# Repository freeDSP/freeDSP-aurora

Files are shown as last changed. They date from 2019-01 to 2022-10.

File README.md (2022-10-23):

FreeDSP logo

# freeDSP aurora

An open source and open hardware [freeDSP](https://freedsp.github.io) board based on ADAU1452 with 8 analog I/O, S/P-DIF I/O, ADAT I/O, USB Audio, WiFi, Bluetooth.

It supports various and convenient physical addons and multiple software plugins, and is controlled by web interface.

## Main features

* Analog Devices ADAU1452, 294.912 MHz, 32-bit SigmaDSP
	* 6144 SIMD instructions per sample @ 48kHz fs
	* 40kWords of data RAM
	* 800ms digital audio delay pool @ 48kHz fs
	* 8 stereo ASRCs with 139dB DNR
* XMOS XE216-512-TQ128 for multichannel bidirectional audio streaming
* ESP32 for WiFi or Bluetooth control
* AKM AK4458 32bit-DAC
* AKM AK5558 32bit-ADC
* Supporting sample rates between 44.1kHz and 192kHz
* 8 analog balanced input channels, +6dBu
* 8 analog balanced output channels, +6dBu
* S/P-DIF input and output
* ADAT input and output
* Wordclock input and output
* Support for display, rotary encoder, volume potentiometer, temperature sensor, PWM controlled fan, IR sensor
* One freeDSP expansion header
* USB Audio Class 2 Bidirectional streaming with 8 channels in and 8 channels out, full-duplex. Works with ASIO driver under Windows 10 and driverless under macOS and Linux.
* Realtime control software over WiFi or Bluetooth available under an open source license
* THD DAC: -103dB @ 1kHz, 0dBfs, fs=48kHz
* THD ADC: -101dB @ 1kHz, 0dBfs, fs=48kHz
* Latency: 1.125ms (talkthrough ADC->DSP->DAC)
* Board dimensions: 110mm x 110mm

MAIN COORDINATOR: [dspverden](https://github.com/dspverden)

## Contributing

**Please take care on which branch you're currently working!**

Branches:

- *master* - this branch always holds the latest released revision
- *develop* - this is the develop branch with new features. Please base your patches on this branch.

[Build instructions](BUILDING.md) | [Addons](ADDONS/README.md) | [User Documentation](DOCUMENTATION/)

## License
<br />This work is licensed under a <a rel="license" href="http://creativecommons.org/licenses/by-sa/4.0/">Creative Commons Attribution-ShareAlike 4.0 International License</a>.

## Related Projects
- [Generate Aurora Plugins from SigmaStudio Exports (Alternative to Aurora's python scripts)](https://github.com/archi/aurora-tool)
- [PCB with startup delay (I2C) mod with a DM 2.4" OLED](https://github.com/Ca-Wi/freeDSP-aurora-extension-i2c-mod-display)
- [PCB to expand the freeDSP aurora expansion port with 3V3 regulator](https://github.com/Ca-Wi/freeDSP-aurora-expansion-port-extender)

## Custom Plugins
- [7.1 Homecinema Plugin with Highpassfilter by pillepalle1234](https://github.com/pillepalle1234/FreeDSP-Aurora-7.1-Homecinema-Plugin-Highpass)

## Links

- [Buy Aurora board and addons](https://auverdion.de/)
- [freeDSP](https://freedsp.github.io)
- [Kickstarter campaign](https://www.kickstarter.com/projects/auverdion/freedsp-aurora-dsp)
- [DIYAudio forum (english)](https://www.diyaudio.com/forums/digital-line-level/334055-freedsp-aurora-dsp-8-os-usb-audio-dif-adat-bluetooth-wifi-contro.html)
- [DIYHifi forum (german, features)](https://www.diy-hifi-forum.eu/forum/showthread.php?18572-freeDSP-aurora-Der-Feature-Thread)
- [DIYHifi forum (german, specs)](https://www.diy-hifi-forum.eu/forum/showthread.php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)
- [ADAU1452 at Analog Devices](https://www.analog.com/en/products/adau1452.html)
- [ESP32 at Espressif](https://www.espressif.com/en/products/socs/esp32/overview)
- [XMOS XE216-512-TQ128 datasheet](https://www.xmos.com/file/xe216-512-tq128-datasheet)
- [AKM 4458](https://www.akm.com/us/en/products/audio/audio-dac/ak4458vn/)
- [AKM 5558](https://www.akm.com/us/en/products/audio/audio-adc/ak5558vn/)

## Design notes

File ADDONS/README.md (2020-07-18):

# Addons

## Add-On A: The woodworker’s friend

Perfect for an active loudspeaker 

- 1x XLR Analog in
- 1x RCA Analog in
- 1x TOSlink in (for S/P-DIF via glassfiber)
- 1x RCA Digital in (for S/P-DIF via coaxial cable)
- 1x RCA Digital out (connect a subwoofer)
- 1x XLR Analog Out (connect a subwoofer)
- 1x USB
- Volume potentiometer

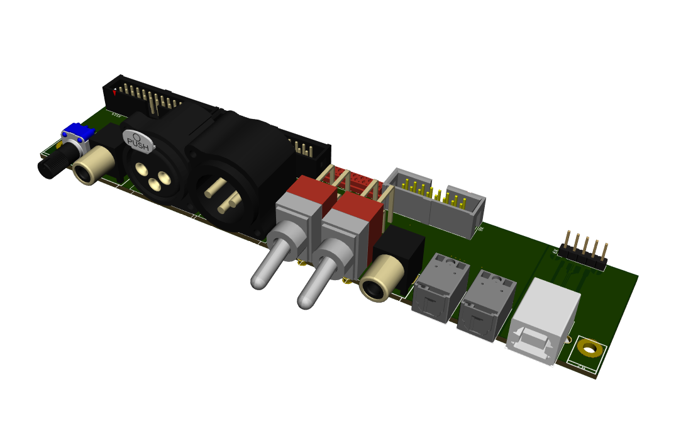
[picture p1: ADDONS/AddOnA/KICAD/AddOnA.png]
Board


### Links

* [Schematics and backplates v1.0.0](AddOnA%201.0.0/)
* [Schematics and backplates](AddOnA/)

## Add-On B: Down with developers

Pre-amp / 7.1-management without limits.

- 8x XLR Analog Out, unbalanced (RCA) is possible too
- 8x RCA Analog In
- 8x XLR Analog In
- 4x RCA Digital In (for S/P-DIF via Cinch)
- 4x TOSlink Digital In ((for S/P-DIF via LWL)
- 1x USB in

All digital inputs are up for multiplexing

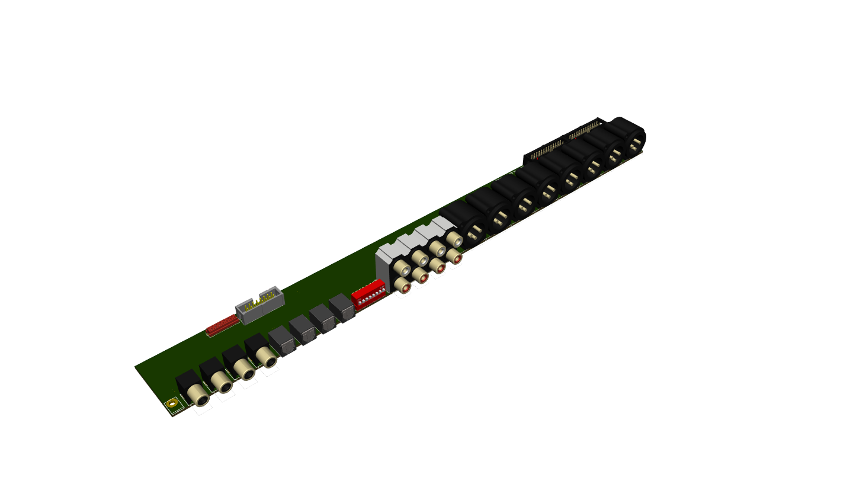
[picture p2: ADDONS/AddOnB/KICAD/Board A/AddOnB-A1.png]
Board A

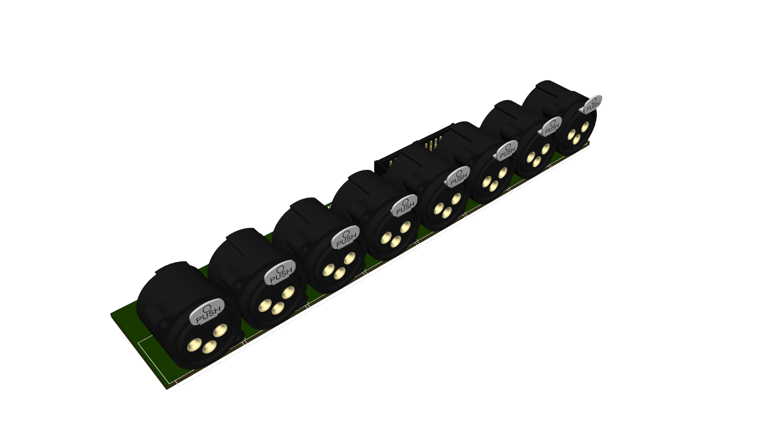
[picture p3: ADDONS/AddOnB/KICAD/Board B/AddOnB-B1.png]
Board B


### Links

* [Schematics and backplates](AddOnB/)

## Add-On C: For those who love to take control over the crowd

Loudspeaker management system for your next gig.

- 8x XLR Analog Out
- 4x XLR Analog In, two ADCs parallel for a much better SNR
- 1x TOSlink in
- 1x TOSlink out
- 1x XLR Digital In AES/EBU
- 1x XLR Digital Out AES/EBU
- 1x USB

All TOSlink can be used with ADAT or S/P-DIF.

### Links

* [Schematics and backplates](AddOnC/)

## Add-On D: Balanced Life

* 8x XLR analog input (balanced)
* 8x XLR analog output (balanced)

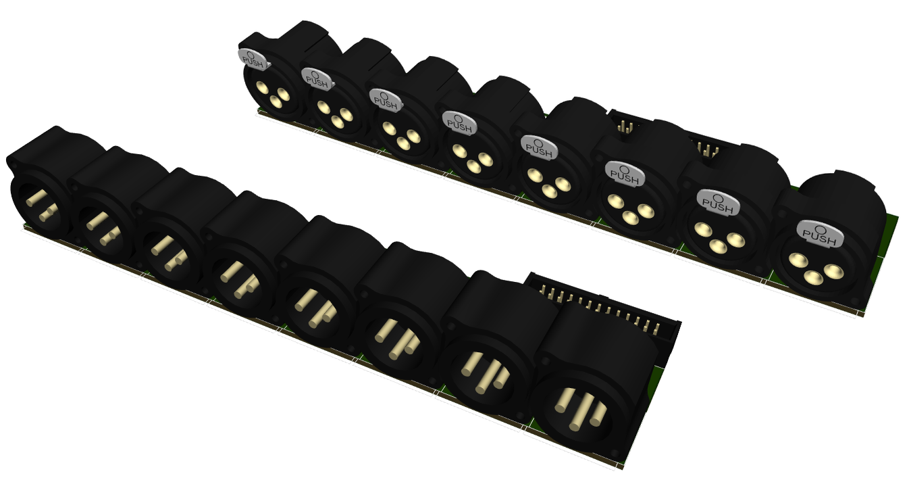
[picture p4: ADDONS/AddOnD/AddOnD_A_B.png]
Board A & B


### Links

* [Schematics and backplates](AddOnD/)

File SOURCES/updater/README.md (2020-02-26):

Updating Aurora DSP with a new binary.

Step 1
Connect your USB2Serial converter to your Aurora DSP. See the UserManual_1.1.1.pdf regarding the required wire connections.

Step 2
Open a terminal and change to directory: <path to repository>/SOURCES/WEBAPP/ESP32/updater

Step 3
On macOS you may have to make the install script executable by typing chmod +x update.sh

Step 4
On macOS execute the firmware update by running ./update.sh <your_com_port>
On Win10 execute the firmware update by running update.bat <your_com_port>
Replace <your_com_port> with the name of your USB2Serial converter, e.g. /dev/cu.SLAB_USBtoUART on macOS or COM7 on Win10.

Step 5
Follow the instructions on your screen.

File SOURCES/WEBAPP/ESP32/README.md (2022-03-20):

# How to build ESP32 firmware

## Installing ArduinoIDE

Go to https://www.arduino.cc/en/Main/Software or use your preferred package manager to install ArduinoIDE.

## Installing the ESPAsyncWebServer library

Follow the next steps to install the ESPAsyncWebServer library:

1. Download the ESPAsyncWebServer library from https://github.com/me-no-dev/ESPAsyncWebServer/archive/master.zip.  
2. Unzip the .zip folder and you should get `ESPAsyncWebServer-master` folder.
3. Rename your folder from `ESPAsyncWebServer-master` to `ESPAsyncWebServer`.
4. Move the `ESPAsyncWebServer` folder to your Arduino IDE installation libraries folder.

## Installing the Async TCP Library for ESP32

The ESPAsyncWebServer library requires the AsyncTCP library to work. Follow the next steps to install that library:

1. Download the AsyncTCP library from https://github.com/me-no-dev/AsyncTCP/archive/master.zip.  
2. Unzip the .zip folder and you should get `AsyncTCP-master` folder.
3. Rename your folder from `AsyncTCP-master` to `AsyncTCP`.
4. Move the `AsyncTCP` folder to your Arduino IDE installation libraries folder.

## Installing the Arduino ESP32 Filesystem Uploader

1. Go to https://github.com/me-no-dev/arduino-esp32fs-plugin/releases/ and click the `ESP32FS-1.0.zip` file to download.
2. Unzip the .zip folder and you should get `ESP32FS` folder
3. Move the `ESP32FS` folder to your Ardino IDE installation tools folder.  
You should have a similar folder structure: `<home_dir>/Arduino/tools/ESP32FS/tool/esp32fs.jar`.

## Installing the ArduinJSON library

1. Open the Arduino Library Manager
2. Search for `ArduinoJson`
3. Select the version: `6.13.0`
4. Click Install.

## Installing the U8g2 library

1. Open the Arduino Library Manager
2. Search for `U8g2`
3. Select the version: `2.27.6`
4. Click Install.

## Installing the IRremote Library

1. Download the IRremote library from https://github.com/dspverden/Arduino-IRremote/archive/master.zip.
2. Unzip the .zip folder and you should get `Arduino-IRremote-master` folder.
3. Rename your folder from `Arduino-IRremote-master` to `Arduino-IRremote`.
4. Move the `Arduino-IRremote` folder to your Arduino IDE installation libraries folder.

## Installing ESP32 boards

1. Open ArduinoID `File > Preferences` dialog, and add following URL to Additional Cards setting:
- https://dl.espressif.com/dl/package_esp32_index.json

2. Open `Tools > Card Types > Manage Cards` and install `ESP32 dev module`.
3. Select `Tools > Card Types > ESP32 Arduino > ESP32 Dev Module` as card.

Ensure Python is in your PATH (as `python`) and it has pyserial module installed.

## Uploading Code and Files

Before uploading, read [firmware update documentation](../../../DOCUMENTATION/AN001%20Firmware%20Update%20EN.pdf).

1. Open the file `aurora.ino` in your ArduinoIDE and click on Upload.
2. After uploading the code, you need to upload the data files.
3. Go to `Tools > ESP32 Data` Sketch Upload and wait for the files to be uploaded.

## That's it

You can now compile and upload new ESP32 firmware.

----

# Alternative method using espmake32 (experimental)

**Following instructions are meant only for espmake32, else skip this!**

## espmake32

Download and install [espmake32](https://github.com/plerup/makeEspArduino).

## Download and install libraries

You have to download the last libraries manually, you'll find them here:

1. [ArduinoJson](https://github.com/bblanchon/ArduinoJson/releases/download/v6.13.0/ArduinoJson-v6.13.0.zip)
2. [u8g2](https://github.com/olikraus/u8g2/archive/master.zip), which does not offer proper releases. Let's hope master doesn't break anything.
3. [IRremote](https://github.com/z3t0/Arduino-IRremote/archive/master.zip). However, while [this PR from dspverden](https://github.com/z3t0/Arduino-IRremote/pull/689) isn't merged, you'll probably prefer [dspverden's branch](https://github.com/dspverden/Arduino-IRremote/archive/master.zip).

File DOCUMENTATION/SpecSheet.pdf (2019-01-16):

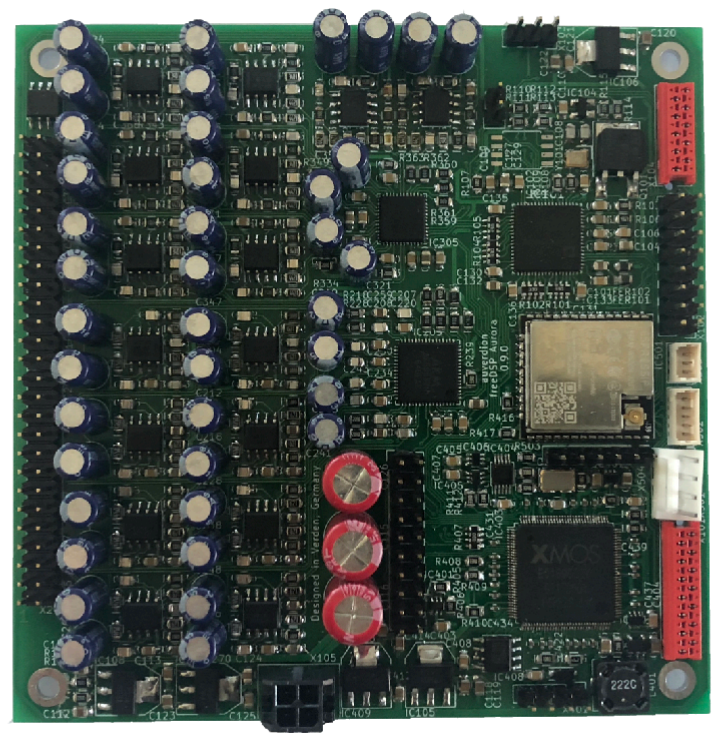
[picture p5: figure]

# FREEDSP-AURORA SPECIFICATIONS PRELIMINARY

auverdion | 1

## REVISION HISTORY

Revision | Description | Date
v1.0 | Initial Version | 15 Jan 2019
auverdion | 2

## ABOUT FREEDSP-AURORA

The freeDSP-aurora is a cost-effective real-time audio signal processing solution for researchers and the do-it-yourself community. It is a bare circuit board that can be incorporated into your own projects. It comes with no housing. Easy assembling and simple programmability are the main focus. It is based on Analog Devices’ ADAU1452 DSP chip in bundle with the free graphical development environment SigmaStudio. The programming model is function-block based – comparable to other graphical programming languages like PureData or Max/MSP. Many prebuilt blocks (e.g., filters, compressors, effects, or logic) can be placed in the signal path via drag and drop. If the included libraries do not have the functions needed, low-level blocks, such as multipliers and delays, can be wired together to create custom algorithms. For more information please refer to the Analog Devices website.

FreeDSP-aurora offers a wide range of DSP processing options and interface controls with easy programmability. It can be used in various audio applications, e.g.:

Room compensation / system equalization
Digital crossovers in active loudspeaker concepts
Multiband dynamics processing
Delay compensation / phase shift
Bass enhancement
Subwoofer integration
Advanced instrument audio effect units Stereo image widening
…

A XMOS XE216-512-TQ128 MCU is used to expose an USB Audio Class 2 compliant interface to a host computer running macOS, Linux or Windows 10. The boards provides 8 audio input and 8 audio output channels to the host computer. Additionally an ADAT input/ output and a Wordclock input/output is provided by the XMOS MCU.

auverdion | 3

The ESP32 MCU controls the operation of the DSP. Furthermore, it provides WiFi and Bluetooth connectivity and handles peripherals like rotary encoder, display, temperature sensor, PWM controlled fan and IR sensor.

As part of the project an open source software is published that controls the operation of the freeDSP-aurora from macOS, Windows or iOS. Via the control software the user can access all parameters of the uploaded DSP schematic. Due to the open source licenses users can modify the control software for supporting their own DSP schematics.

The plans and software for the freeDSP-aurora board are published under a Creative Commons Attribution NonCommercial ShareAlike 4.0 International (CC BY-NC-SA 4.0) license, which allows the unrestricted use and modification of the module for non-commercial purposes. This means that experienced users can make their own version of the board, extending it and improving it, as long as they credit freeDSP and auverdion and release their designs under the same license.
The freeDSP brand and freeDSP logo are copyright of Sebastian Merchel and Ludwig Kormann and cannot be used without formal permission.
The auverdion brand is copyright of Raphael Knoop and cannot be used without formal permission.
This getting started guide is published under the same CC license.
auverdion | 4

## FEATURES

- Analog Devices ADAU1452, 294.912 MHz, 32-bit SigmaDSP 6144 SIMD instructions per sample @ 48kHz fs 40kWords of data RAM
800ms digital audio delay pool @ 48kHz fs
8 stereo ASRCs with 139dB DNR
- XMOS XE216-512-TQ128 for multichannel bidirectional audio streaming
- ESP32 for WiFi or Bluetooth control
- AKM AK4458 32bit-DAC
- AKM AK5558 32bit-ADC
- Supporting sample rates between 44.1kHz and 192kHz
- 8 analog balanced input channels, +6dBu
- 8 analog balanced output channels, +6dBu
- S/P-DIF input and output
- ADAT input and output
- Wordclock input and output
- Support for display, rotary encoder, volume potentiometer, temperature sensor, PWM controlled fan, IR sensor
- One freeDSP expansion header
- USB Audio Class 2 Bidirectional streaming with 8 channels in and 8 channels out, full-duplex. Works with ASIO driver under Windows 10 and driverless under macOS and Linux.
- Realtime control software for Windows, macOS, Linux, iOS connecting by WiFi or Bluetooth available under an open source license
- Board dimensions: 100mm x 100mm
auverdion | 5

## OVERVIEWS

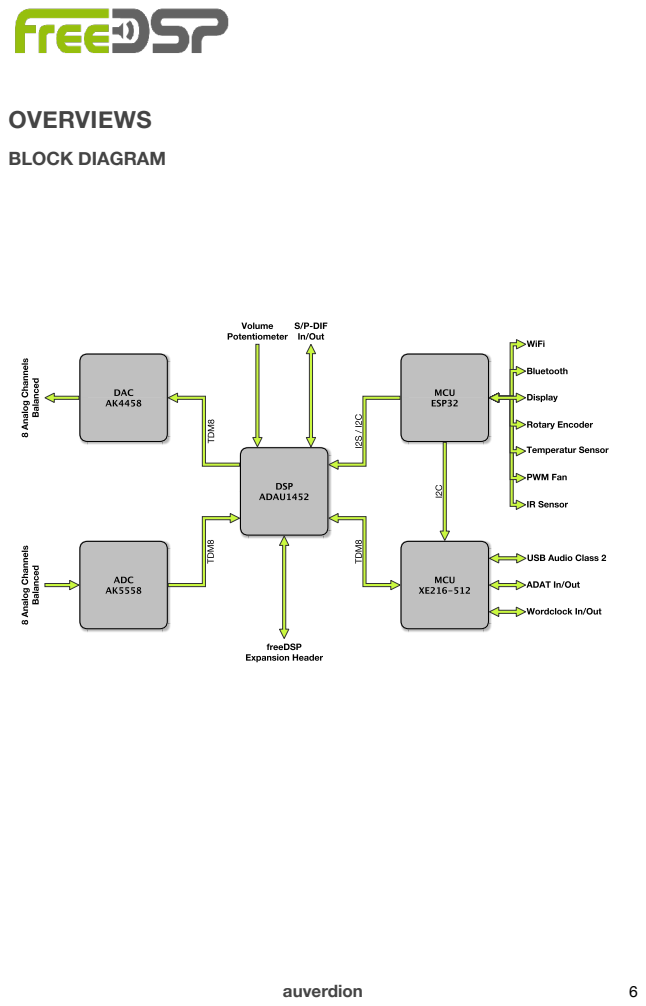
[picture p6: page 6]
BLOCK DIAGRAM; auverdion

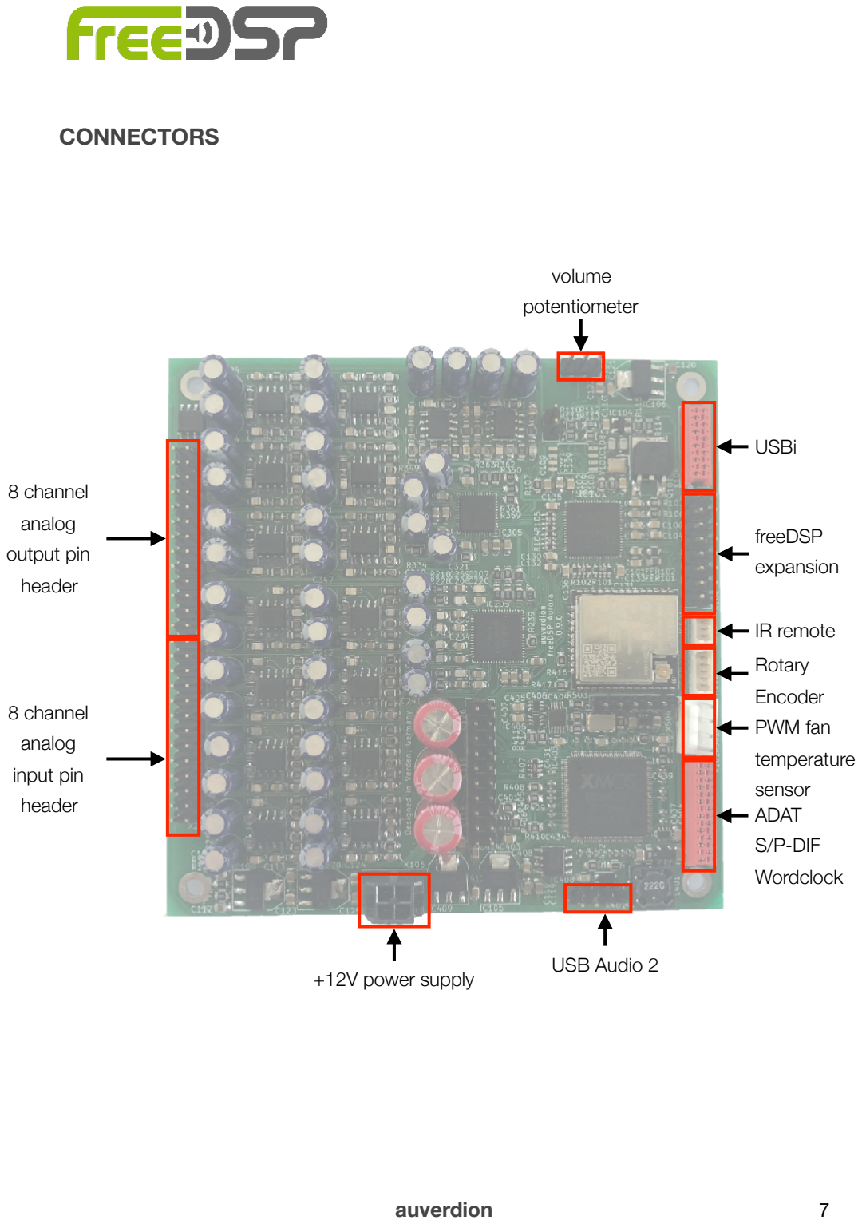
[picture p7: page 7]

CONNECTORS

auverdion | 7

8 channel
analog
output pin
header

8 channel
analog
input pin
header

+12V power supply

volume
potentiometer

USB Audio 2

freeDSP
expansion

USBi

IR remote

ADAT
S/P-DIF
Wordclock

Rotary
Encoder
PWM fan
temperature
sensor

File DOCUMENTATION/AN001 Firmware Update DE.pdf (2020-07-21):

# FIRMWARE UPDATE FREEDSP-AURORA

auverdion | 1

## REVISIONSÜBERSICHT

Revision | Beschreibung | Datum
v1.0.0 | Initial Version | 09 Feb 2020
v1.1.0 | WebOTA hinzugefügt | 26 Feb 2020
v2.1.0 | Empfehlung zum Presetexport hinzugefügt | 20 Jul 2020
auverdion | 2

Revisionsübersicht | 2
Wichtige Information | 4
Update der Firmware via USB | 5
Update vorbereiten | 5
Firmware hochladen | 6
Update der Firmware über webOTA | 12
Hochladen der Firmware | 12
Haftungsausschluss | 14
auverdion | 3

## WICHTIGE INFORMATION

Das freeDSP-Aurora-Board kann Signale erzeugen, die Dein Audiogerät beschädigen können. Bitte lies dieses Application Note und das Handbuch sorgfältig, bevor Du mit der Arbeit mit Deinem Board beginnst. Passe alle Hardware-Einstellungen an und konfiguriere Deine Software, bevor Du ein Audiogerät an freeDSP-aurora anschließt. Beginne immer mit der geringsten Lautstärke an Deinem Verstärker und erhöhe den Pegel langsam, um das Risiko einer Beschädigung Deines Audiosystems zu verringern.

Insbesondere die Installation von Alpha- und Betaversionen kann zu einem fehlerhaften Verhalten führen. Die Installation erfolgt auf eigenes Risiko.

FreeDSP-aurora wird Dir wie gesehen zur Verfügung gestellt. Auverdion gibt keine ausdrücklichen oder stillschweigenden Garantien in Bezug auf seine Funktionalität, Funktionsfähigkeit oder Nutzung, einschließlich, aber nicht beschränkt auf stillschweigende Garantien der Marktgängigkeit, der Eignung für einen bestimmten Zweck oder Rechtsverletzungen. Wir lehnen ausdrücklich jegliche Haftung für direkte, indirekte, Folge-, Neben- oder Sonderschäden ab, einschließlich, aber nicht beschränkt auf Umsatzeinbußen, entgangenen Gewinn, Verluste infolge von Betriebsunterbrechungen oder Datenverlust, unabhängig von der Art der Klage oder der Rechtstheorie, nach der die Haftung geltend gemacht werden kann, selbst wenn wir über die Möglichkeit oder Wahrscheinlichkeit solcher Schäden informiert wurden. Funktionen und Spezifikationen können ohne vorherige Ankündigung geändert werden.

Bitte beachte, dass freeDSP-aurora ein Open-Source-Projekt ist. Da freeDSP-aurora sehr flexibel ist, sind viele Anwendungen möglich. Fragen und neue Ideen können online mit anderen Nutzern diskutiert werden. Bitte verwende das Digital Line Level Subforum @ diyAudio.com oder das auverdion Subforum @ www.diy-hifi-forum.eu, um mit anderen Personen in Kontakt zu treten, die mit freeDSP-aurora arbeiten. Bitte erstelle nur dann individuelle Themen für Dein Anliegen, wenn Du Dein Problem in den vorhandenen Themen nicht findest. Einige Fragen können durch sorgfältiges Lesen dieses Handbuchs beantwortet werden.

auverdion | 4

## UPDATE DER FIRMWARE VIA USB

Dieses Kapitel führt Dich durch alle Schritte, um ein Firmwareupdate über eine USB-Verbindung durchzuführen. Das Update selbst wird durch ein Skript durchgeführt.

UPDATE VORBEREITEN

Für das Aktualisieren der Firmware benötigst Du ein USB2Serial-Modul basierend auf einem FTx232- oder CP2102N-Modul, z.B. https://www.ftdichip.com/Products/Modules/DevelopmentModules.htm#FT2232H_Mini oder ähnlich. Bitte vergewissere Dich, daß Dein Modul mit einer Spannung von 3.3V arbeitet. Module mit +5V Spannung können Deinen freeDSP-Aurora beschädigen.
Ggfs. Musst Du noch einen Treiber für Dein USB2Serial-Modul installieren. Bitte lies hierzu das Handbuch Deines Moduls.

Wenn Du ein Update von Version 2.x.x ausführen willst, exportiere bitte zunächst Deine Presets, damit Du diese nach dem Update wieder importieren kannst.

auverdion | 5

FIRMWARE HOCHLADEN

Um eine neue Firmware auf Deinen freeDSP-Aurora hochzuladen, gehe wie folgt vor:
1. Lade das neueste Release von github: https://github.com/freeDSP/freeDSP-aurora Wenn Du eine Alpha- oder Betaversion (Preview-Versionen) installieren möchtest, musst Du eventuell in den entsprechenden Featurezweig wechseln, indem Du diesen im Dropdown-Menu Branch auswählst, z.B. feature/develop und anschliessend auf Clone or download klickst und Download ZIP auswählst.

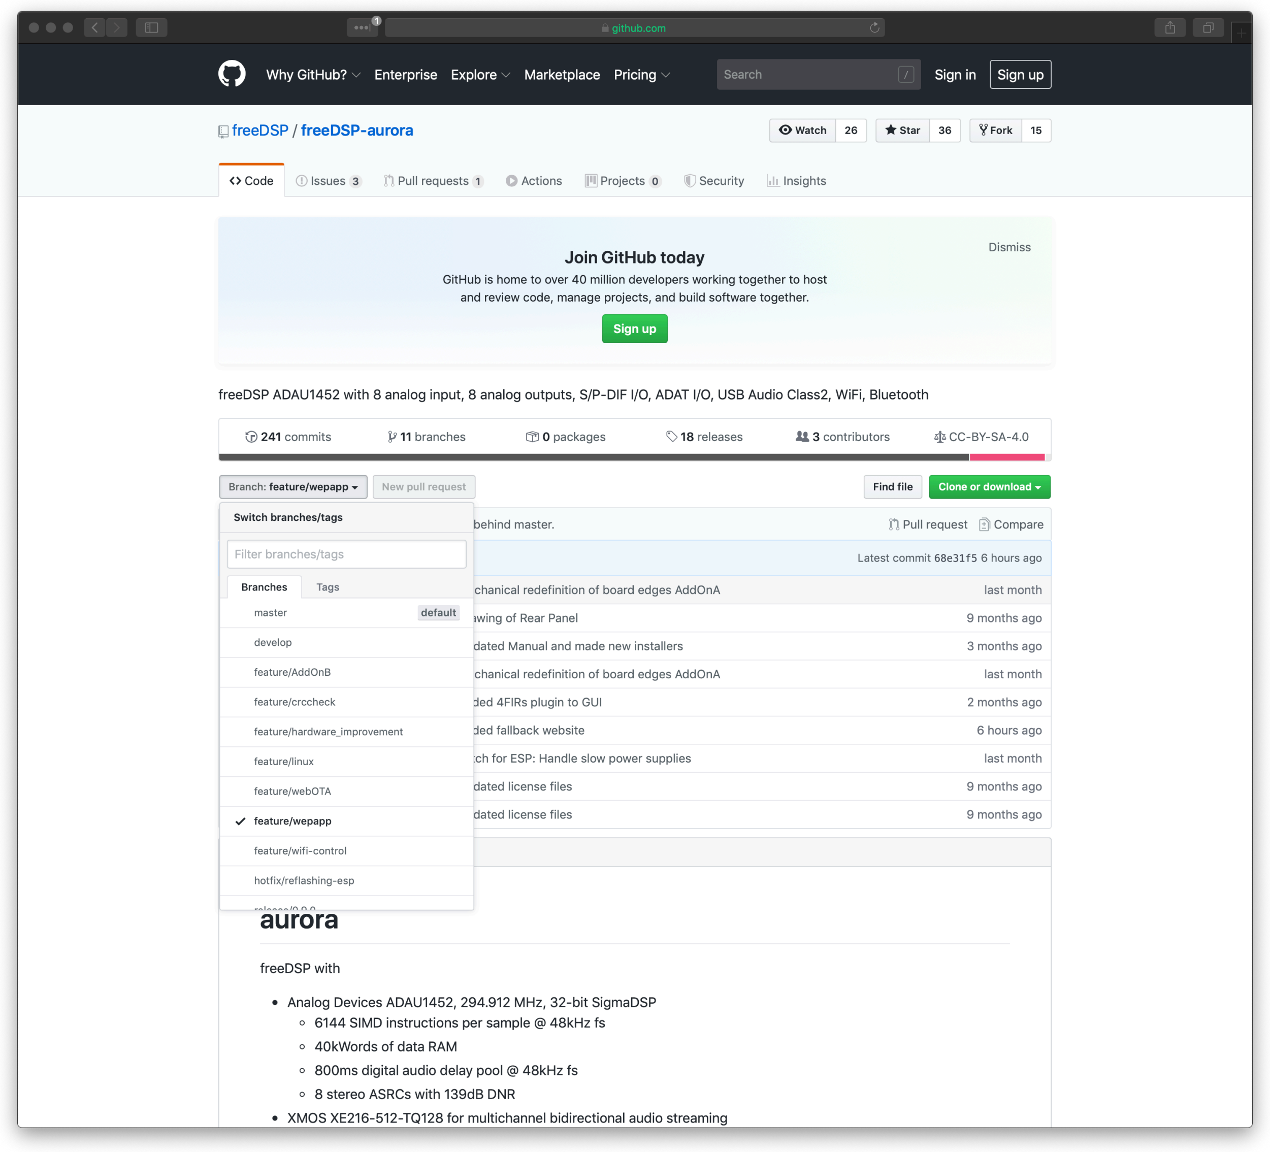
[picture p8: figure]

auverdion | 6

2. Entpacke die heruntergeladene zip-Datei (sofern Dein Computer dies nicht selbstständig erledigt).
3. Schalte Deinen freeDSP-aurora aus.
4. Installiere einen Jumper oder stelle eine Verbindung zwischen Pin 5 und 6 von X504 her. Das Update-Tool wird Dich an diesen Jumper erinnern.

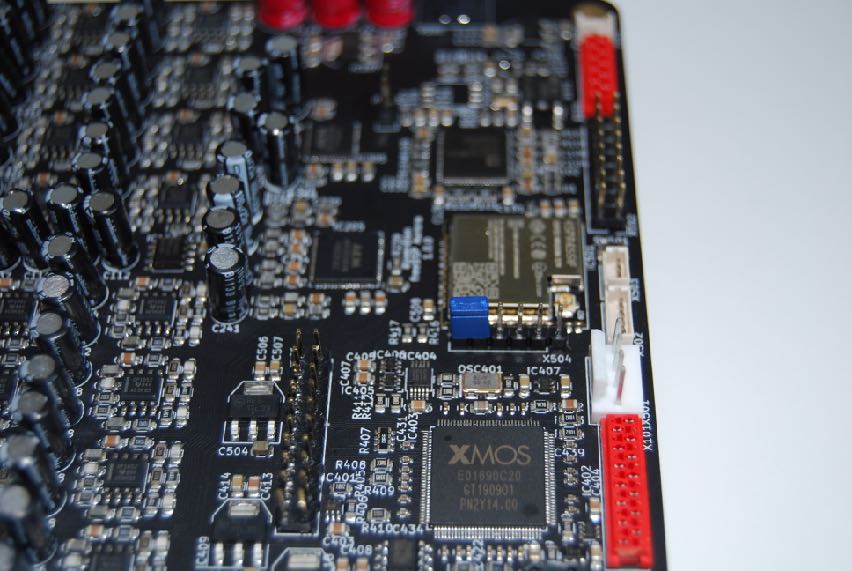
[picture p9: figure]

auverdion | 7

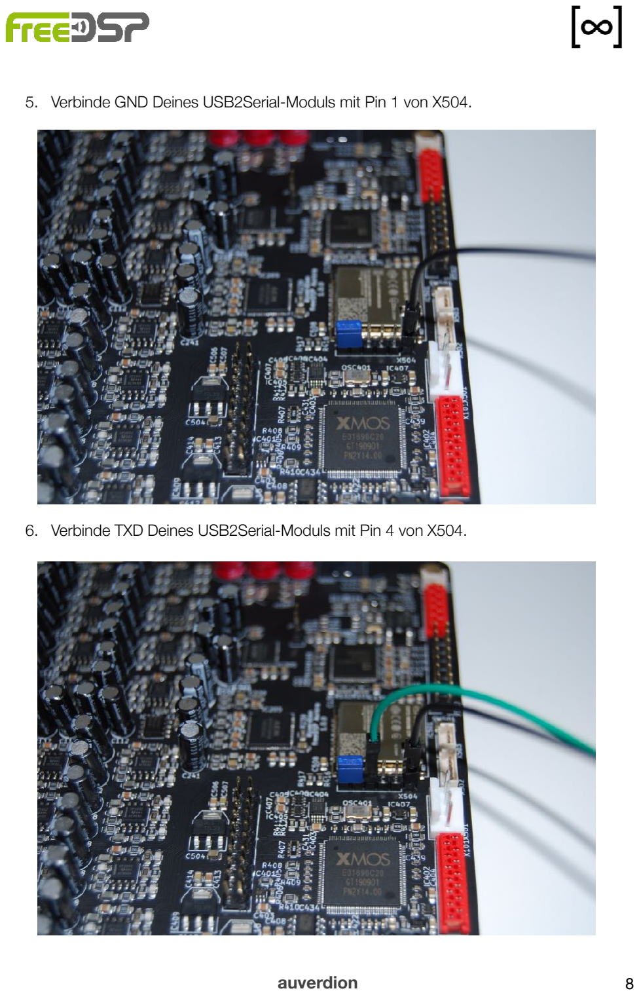
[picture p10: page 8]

5. Verbinde GND Deines USB2Serial-Moduls mit Pin 1 von X504.
6. Verbinde TXD Deines USB2Serial-Moduls mit Pin 4 von X504.
auverdion | 8

7. Verbinde RXD Deines USB2Serial-Moduls mit Pin 3 von X504.

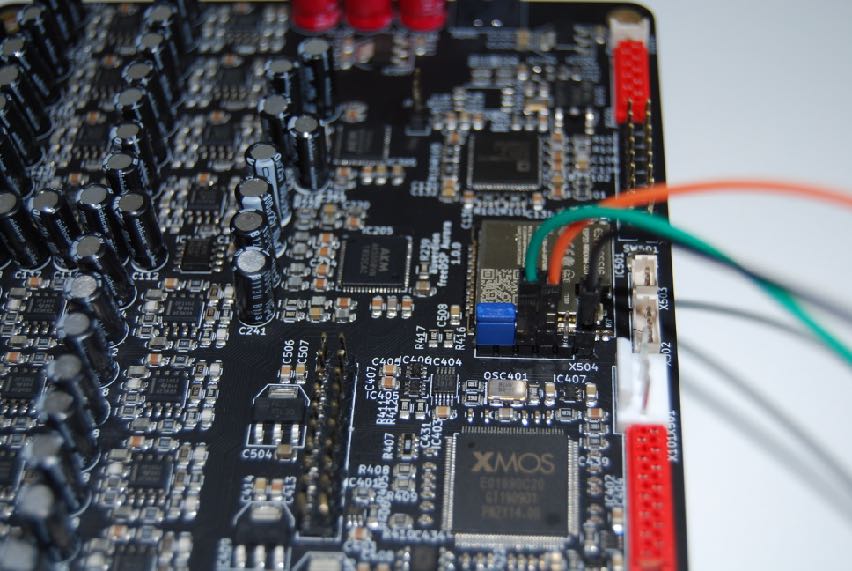
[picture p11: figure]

8. Verbinde Dein USB2Serial-Modul mit Deinem Computer.
9. Schalte freeDSP-Aurora ein.
10. Öffne ein Terminal (Eingabeaufforderung) and wechsle in das Skript-Verzeichnis durch Eingabe von
cd <path_to_repository>/SOURCES/WEBAPP/ESP32/updater
11. Unter macOs kann es sein, dass Du das Updateskript ausführbar machen musst. Gibt dazu ein:
chmod +x update.sh
12. Unter macOS starte das Skript mit ./update.sh <your_com_port>.
Dabei musst Du <your_com_port> durch den Namen Deines USB2Serial-Adapters
ersetzen, z.B. /dev/cu.usbserial-FTRXGG930.
13. Unter Windows gibts Du update.bat <your_com_port> ein.
Dabei musst Du <your_com_port> durch den Namen Deines USB2Serial-Adapters ersetzten, z.B. COM3.
auverdion | 9

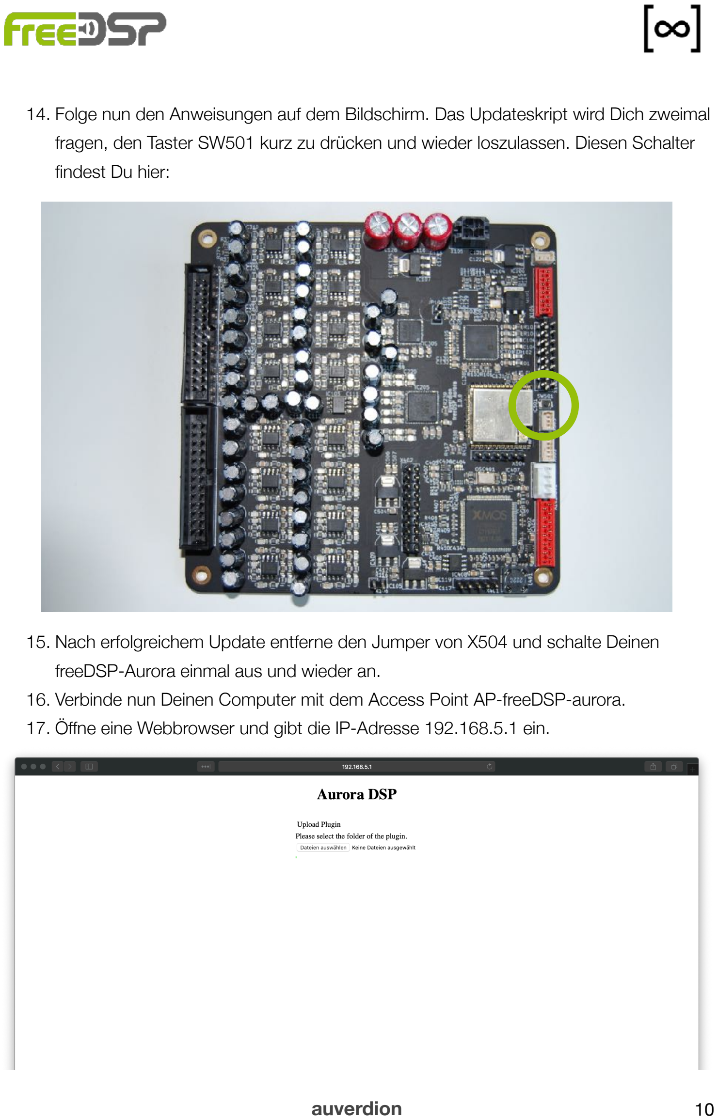
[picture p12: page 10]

14. Folge nun den Anweisungen auf dem Bildschirm. Das Updateskript wird Dich zweimal fragen, den Taster SW501 kurz zu drücken und wieder loszulassen. Diesen Schalter findest Du hier:
15. Nach erfolgreichem Update entferne den Jumper von X504 und schalte Deinen freeDSP-Aurora einmal aus und wieder an.
16. Verbinde nun Deinen Computer mit dem Access Point AP-freeDSP-aurora.
17. Öffne eine Webbrowser und gibt die IP-Adresse 192.168.5.1 ein.
auverdion | 10

18. Klicke nun auf Dateien auswählen und wähle das Verzeichnis mit Deinem Plugin aus. Wichtig: Bitte wähle nur das Verzeichnis, nicht eine Datei in dem Verzeichnis.
Du findest die Plugins im Verzeichnis <path_to_repository>/SOURCES/

WEBAPP/plugins

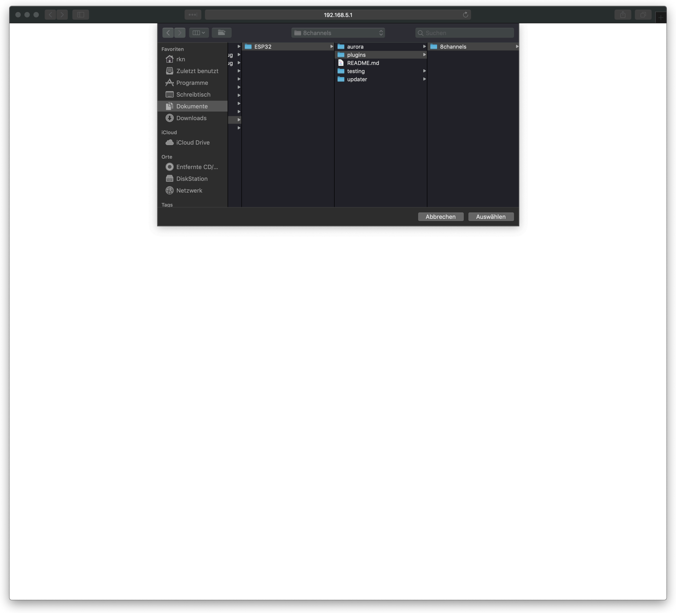
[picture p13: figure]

19. Es wird das gewählte Plugin installiert.
20. Nach erfolgreichem Update startest Du Deinen freeDSP-Aurora neu, verbindest Dich mit dem Access Point AP-freeDSP-aurora und gibst die Adresse 192.168.5.1 in Deinem Webbrowser ein. Du siehts nun das Webinterface Deines gewählten Plugins und kannst damit beginnen, freeDSP-Aurora für Deine Anwendung zu konfiguriere.
auverdion | 11

## UPDATE DER FIRMWARE ÜBER WEBOTA

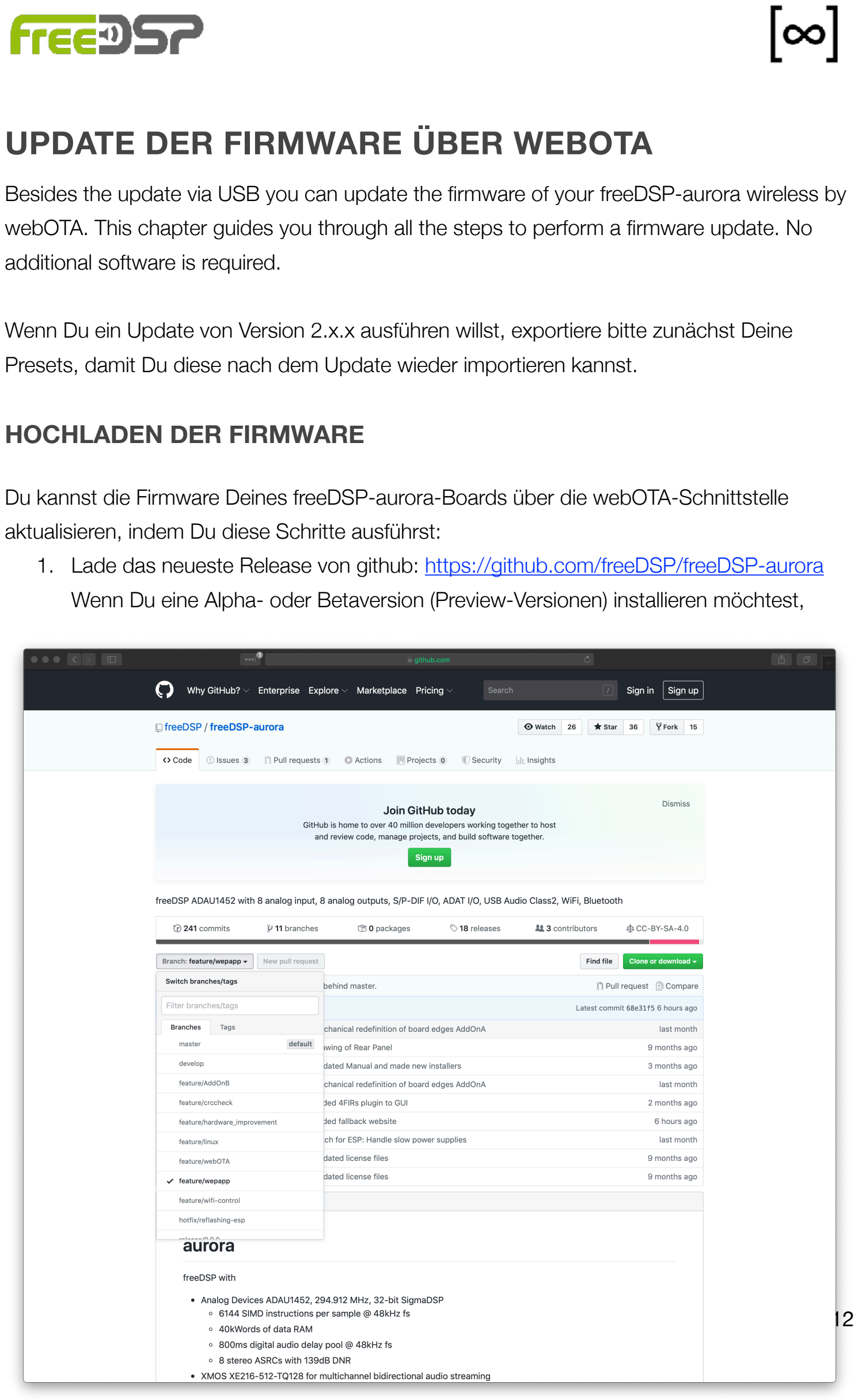
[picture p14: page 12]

Besides the update via USB you can update the firmware of your freeDSP-aurora wireless by webOTA. This chapter guides you through all the steps to perform a firmware update. No additional software is required.

Wenn Du ein Update von Version 2.x.x ausführen willst, exportiere bitte zunächst Deine Presets, damit Du diese nach dem Update wieder importieren kannst.

HOCHLADEN DER FIRMWARE

Du kannst die Firmware Deines freeDSP-aurora-Boards über die webOTA-Schnittstelle aktualisieren, indem Du diese Schritte ausführst:
1. Lade das neueste Release von github: https://github.com/freeDSP/freeDSP-aurora Wenn Du eine Alpha- oder Betaversion (Preview-Versionen) installieren möchtest,
auverdion | 12

musst Du eventuell in den entsprechenden Featurezweig wechseln, indem Du diesen im Dropdown-Menu Branch auswählst, z.B. feature/develop und anschliessend auf Clone or download klickst und Download ZIP auswählst. Die heruntegeladene ZIP-Datei musst Du noch entpacken, falls Dein Computer das nicht selbständig macht.
2. Verbinde Deinen Computer mit dem WiFi-Access-Point AP-freeDSP-aurora.
3. Öffne einen Webbrowser und gib die URL http://192.168.5.1/webota ein.
4. Alternativ kannst Du Deinen Computer mit dem gleichen lokalen WiFi-Netzwerk verbinden, mit dem auch Dein freeDSP-Aurora verbunden ist, und die IP 192.168.5.1 durch die IP ersetzen, die Dein Board von Deinem Router erhalten hat.
5. Klicke auf die Schaltfläche, um die Firmware-Binärdatei von Ihrer Festplatte auszuwählen. Der Dateiname der Firmware ist üblicherweise
aurora.ino.esp32.bin. Die Firmware auf dem neuesten Stand findest Du in

<path_to_repository>/SOURCES/WEBAPP/ESP32/updater
6. Sobald Du eine Datei ausgewählt hast wird die neue Firmware auf Dein Board hochgeladen. Nach dem erfolgreichen Update erhältst Du eine Benachrichtigung und Dein freeDSP-aurora-Board wird anschliessend automatisch neu gestartet.
7. Verbinde Dich mit dem Access Point AP-freeDSP-aurora und gebe http://192.168.5.1/fallback im URL-Feld Deines Browsers ein.
8. Installiere nun das Plugin neu.
9. Dein freeDSP-aurora ist nun auf dem neuesten Stand.
auverdion | 13

## HAFTUNGSAUSSCHLUSS

Alle Produkte, Produktspezifikationen und Daten können ohne Vorankündigung geändert werden, um die Zuverlässigkeit, Funktion oder das Design zu verbessern.
Auverdion, seine Tochtergesellschaften, Vertreter und Mitarbeiter sowie alle Personen, die in seinem oder ihrem Namen handeln, lehnen jegliche Haftung für Fehler, Ungenauigkeiten oder Unvollständigkeiten ab, die in einem Datenblatt, Handbuch, einer Anwendungsnotiz oder einem anderen Dokument zu einem Produkt enthalten sind.
Diese Baugruppe ist nur für den Einsatz in Musikwiedergabegeräten vorgesehen. Es werden keine Angaben zur Eignung für andere Zwecke gemacht. Sofern nicht anders angegeben, beziehen sich die angegebenen Spezifikationen nur auf diese Baugruppe. Die Verantwortung für die Überprüfung der Leistung, Sicherheit, Zuverlässigkeit und Einhaltung der gesetzlichen Normen von Endprodukten mit dieser Baugruppe liegt beim Hersteller des Endprodukts.

Auverdion gibt keine ausdrücklichen oder stillschweigenden Garantien in Bezug auf seine Funktionalität, Funktionsfähigkeit oder Nutzung, einschließlich, aber nicht beschränkt auf stillschweigende Garantien der Marktgängigkeit, der Eignung für einen bestimmten Zweck oder Rechtsverletzung. Wir lehnen ausdrücklich jegliche Haftung für direkte, indirekte, Folge-, Neben- oder Sonderschäden ab, einschließlich, aber nicht beschränkt auf Umsatzeinbußen, entgangenen Gewinn, Verluste infolge von Betriebsunterbrechungen oder Datenverlust, unabhängig von der Art der Klage oder der Rechtstheorie, nach der die Haftung geltend gemacht werden kann, selbst wenn wir über die Möglichkeit oder Wahrscheinlichkeit solcher Schäden informiert wurden.

Die Verwendung von Auverdion-Produkten in lebenserhaltenden Geräten oder Geräten, deren Ausfall erwartbar zu Verletzungen oder zum Tod führen kann, ist nicht zulässig.

auverdion | 14

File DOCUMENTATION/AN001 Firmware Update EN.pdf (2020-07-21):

# FIRMWARE UPDATE FREEDSP-AURORA

auverdion | 1

## REVISION HISTORY

Revision | Description | Date
v1.0.0 | Initial Version | 09 Feb 2020
v1.1.0 | Added webOTA | 26 Feb 2020
v2.1.0 | Added hint for preset export | 20 Jul 20
auverdion | 2

Revision History | 2
Important Information | 4
Updating the Firmware via USB | 5
Preparing for Update | 5
Uploading the Firmware | 6
Updating the Firmware via webOTA | 12
Uploading the Firmware | 12
Disclaimer | 14
auverdion | 3

## IMPORTANT INFORMATION

The freeDSP-aurora board might generate signals that may damage your audio equipment. Please read and understand this manual before starting to work with your board. Adjust all hardware settings and configure your software before connecting any audio equipment to freeDSP-aurora. Always start with low volume on your amplifier and slowly increase the level to reduce the risk of damaging your audio system.

Especially the installation of alpha and beta versions can lead to incorrect behavior. The installation is at your own risk.

freeDSP-aurora is provided to you ‘as is’. Auverdion makes no express or implied warranties whatsoever with respect to its functionality, operability, or use, including, without limitation, any implied warranties of merchantability, fitness for a particular purpose, or infringement. We expressly disclaim any liability whatsoever for any direct, indirect, consequential, incidental or special damages, including, without limitation, lost revenues, lost profits, losses resulting from business interruption or loss of data regardless of the form of action or legal theory under which the liability may be asserted, even if advised of the possibility or likelihood of such damages. Features and specifications might change without prior notice.

Please keep in mind that freeDSP-aurora is an open-source project. Because freeDSP-aurora is very flexible, many applications are possible. Questions and new ideas can be discussed online with other DIYers. Please use the Digital Line Level subforum @ diyAudio.com or the auverdion subforum @ www.diy-hifi-forum.eu to connect with other people working with freeDSP-aurora. Please create individual threads for your topics only if you cannot find your issue in the existing threads. Some questions can be answered by carefully reading this manual.

auverdion | 4

## UPDATING THE FIRMWARE VIA USB

This chapter guides you through all the steps to perform a firmware update via an USB connection. The update itself will be done by a script.

PREPARING FOR UPDATE

For updating the firmware you need an USB2Serial module based on a FTx232 or CP2102N module, e.g.
https://www.ftdichip.com/Products/Modules/DevelopmentModules.htm#FT2232H_Mini or similar. Please make sure that your module works with a voltage of +3.3V. Modules with +5V voltage can damage your freeDSP-Aurora.
You may need to install a driver for your USB2Serial module. Please read the manual of your module.

If you are updating from version 2.x.x please export your presets first and import them after the update again.

auverdion | 5

UPLOADING THE FIRMWARE

For uploading a new firmware to your freeDSP-aurora do the following steps:
1. Download the latest release from github: https://github.com/freeDSP/freeDSP-aurora If you want to install a alpha or beta version (preview versions) instead you may have to switch to the right feature branch by selecting it in the branch drop down menu, e.g. feature/develop. Then click on Clone or download and select Download ZIP.

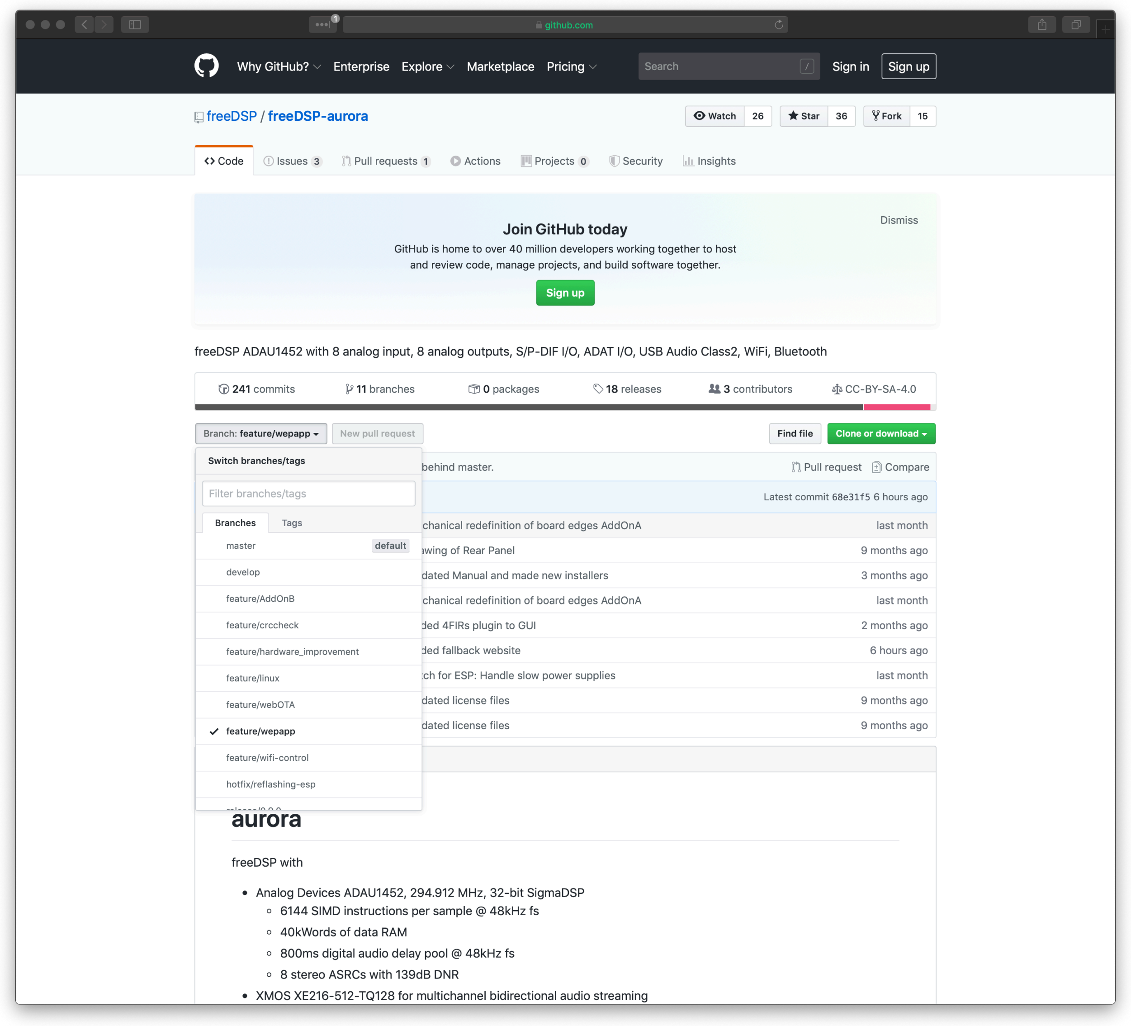
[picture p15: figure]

2. Unzip the downloaded zip file (if your computer does not do this by itself).
3. Power off your freeDSP-aurora module.
auverdion | 6

4. Install a jumper or make a connection between pin 5 and 6 of X504. The update tool will remind you of this jumper.


auverdion | 7

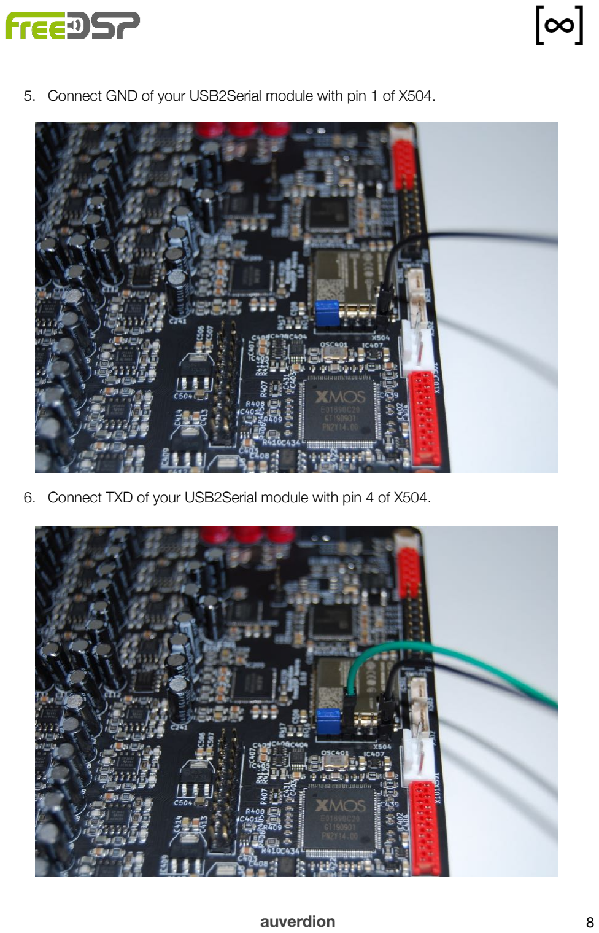
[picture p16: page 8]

5. Connect GND of your USB2Serial module with pin 1 of X504.
6. Connect TXD of your USB2Serial module with pin 4 of X504.
auverdion | 8

7. Connect RXD of your USB2Serial module with pin 3 of X504.


8. Connect your USB2Serial module with your computer.
9. Power up your freeDSP-aurora.
10. Open a terminal (command prompt) and change to script directory by entering
cd <path_to_repository>/SOURCES/WEBAPP/ESP32/updater
11. On macOs you may have to make the update script executable by entering
chmod +x update.sh
12. Under macOS start the update scrip by ./update.sh <your_com_port>. Replace <your_com_port> by the name of your USB2Serial module, e.g.
/dev/cu.usbserial-FTRXGG930.
13. Under Windows start the update scrip by update.bat <your_com_port>. Replace <your_com_port> by the name of your USB2Serial module, e.g. COM3.
auverdion | 9

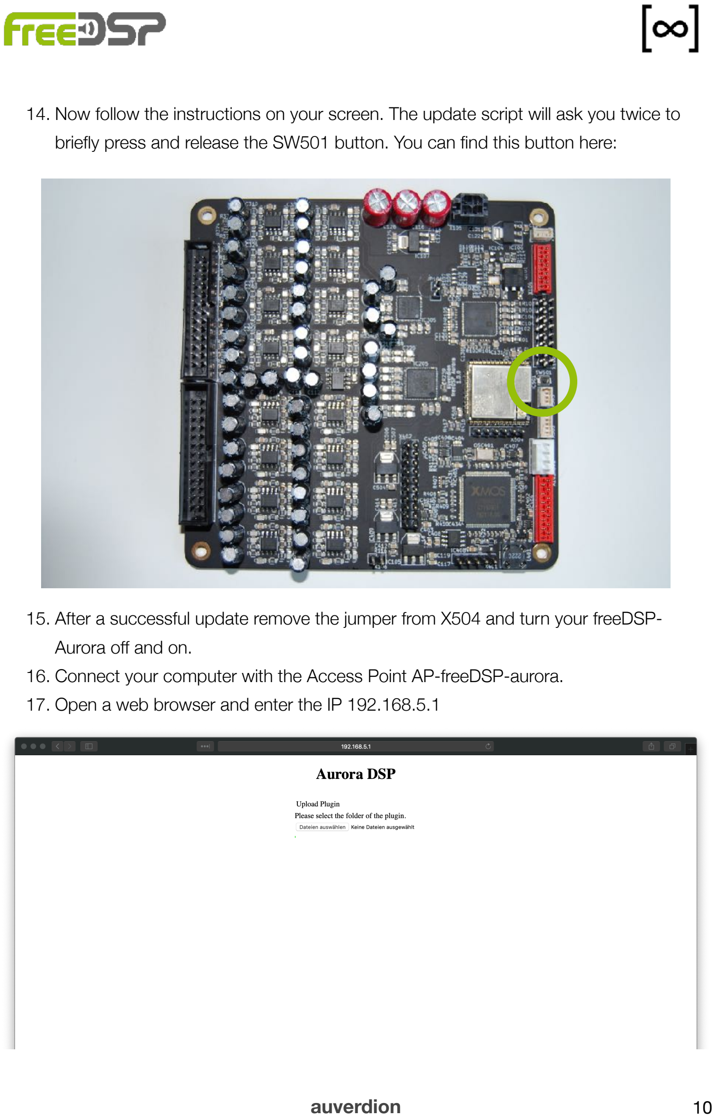
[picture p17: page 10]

14. Now follow the instructions on your screen. The update script will ask you twice to briefly press and release the SW501 button. You can find this button here:
15. After a successful update remove the jumper from X504 and turn your freeDSP-Aurora off and on.
16. Connect your computer with the Access Point AP-freeDSP-aurora.
17. Open a web browser and enter the IP 192.168.5.1
auverdion | 10

18. Click now on Select files and select the directory of the plugin you want to install. Important: You have to select the directory name not any file inside this directory. You
will find the plugins here: <path_to_repository>/SOURCES/WEBAPP/plugins

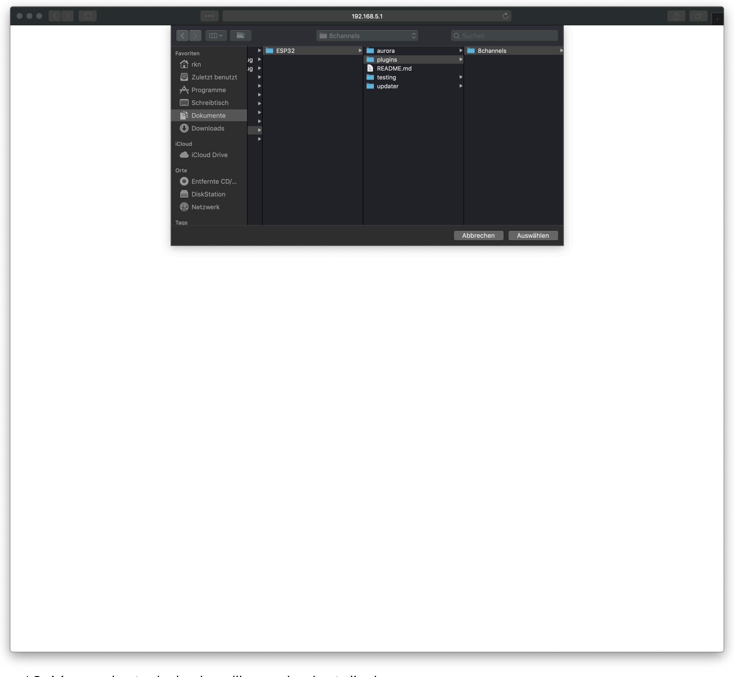
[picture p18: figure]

19. Your selected plugin will now be installed.
20. After successful installation restart your freeDSP-Aurora, reconnect to access point AP-freeDSP-aurora and in your web browser type in the address 192.168.5.1. You will see now the web interface of your selected plugin. You can now start to configure freeDSP-Aurora for your application.
auverdion | 11

## UPDATING THE FIRMWARE VIA WEBOTA

Besides the update via USB you can update the firmware of your freeDSP-aurora wireless by webOTA. This chapter guides you through all the steps to perform a firmware update. No additional software is required.

If you are updating from version 2.x.x please export your presets first and import them after the update again.

UPLOADING THE FIRMWARE

For uploading a new firmware to your freeDSP-aurora do the following steps:
1. Download the latest release from github: https://github.com/freeDSP/freeDSP-aurora If you want to install a alpha or beta version (preview versions) instead you may have

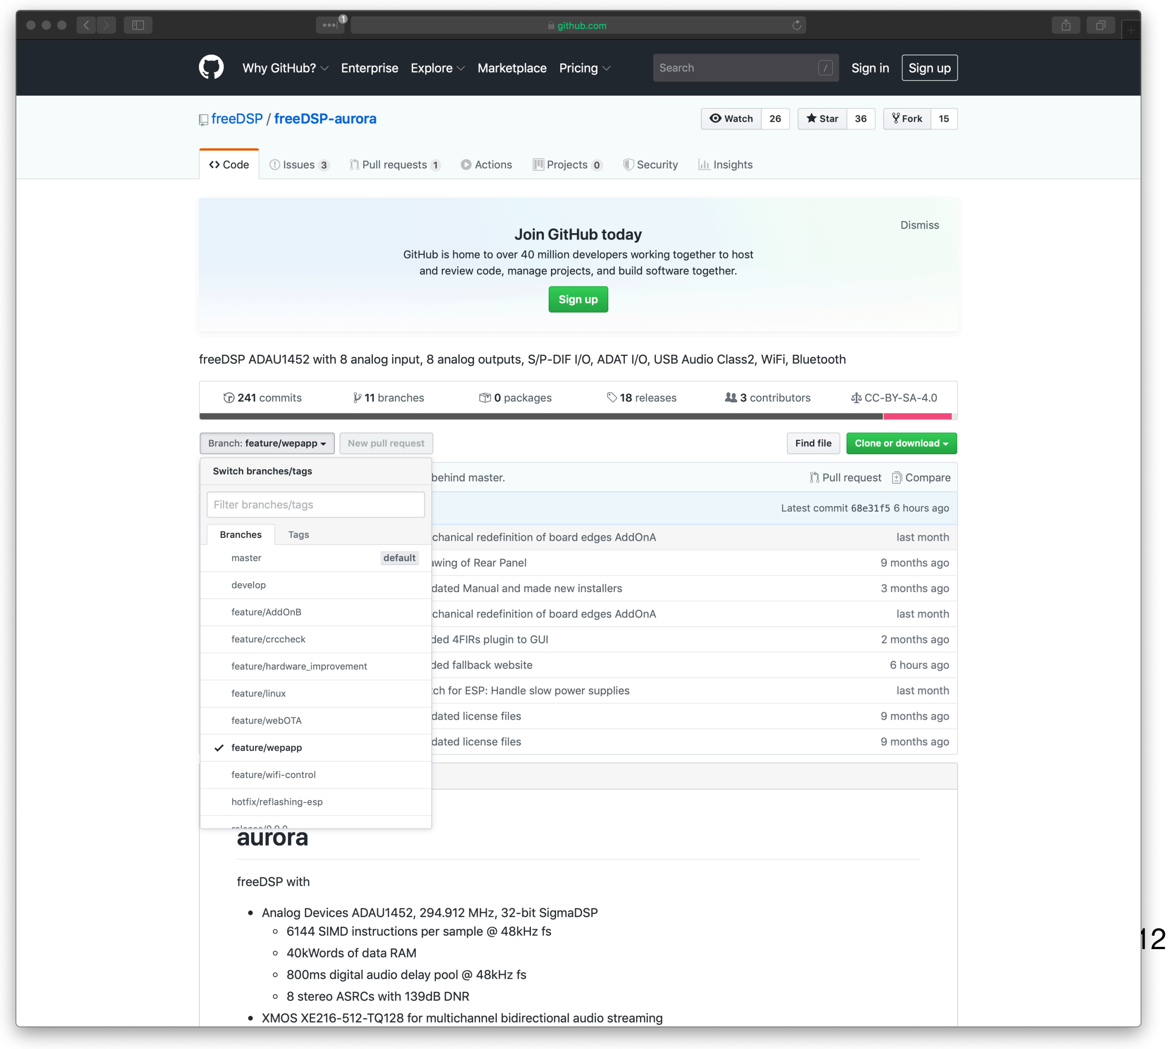
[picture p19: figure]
auverdion

to switch to the right feature branch by selecting it in the branch drop down menu, e.g. feature/develop. Then click on Clone or download and select Download ZIP.
2. Unzip the downloaded zip file (if your computer does not do this by itself).
3. Connect you computer with the WiFi access point AP-freeDSP-aurora.
4. Open web browser and type in the URL http://192.168.5.1/webota
5. Alternatively you can connect you computer to the same local WiFi network your freeDSP-aurora is connected to and replace the ip 192.168.5.1 by the ip your board got from your router.
6. Click on the button to select the firmware binary from your hard disk. The filename of the firmware is usually aurora.ino.esp32.bin. You can find the latest binary in

<path_to_repository>/SOURCES/WEBAPP/ESP32/updater
7. Once you have selected a file the update process starts. The new binary will now be uploaded to your board. After a successful update you will see a message box and afterwards your freeDSP-aurora board will restart.
8. Connect to the Access Point AP-freeDSP-aurora and enter http://192.168.5.1/fallback (http://192.168.5.1/fallback) in the URL field of your browser.
9. Reinstall your plugin now.
10. Your freeDSP-aurora is updated now.
auverdion | 13

## DISCLAIMER

All products, product specifications and data are subject to change without notice to improve reliability, function or design or otherwise.
Auverdion, its affiliates, agents, and employees, and all persons acting on its or their behalf, disclaim any and all liability for any errors, inaccuracies or incompleteness contained in any datasheet, manual, application note or any other document relating to any product.
This subassembly is designed for use in music reproduction equipment only. No representations are made as to fitness for other uses. Except where noted otherwise any specifications given pertain to this subassembly only. Responsibility for verifying the performance, safety, reliability and compliance with legal standards of end products using this subassembly falls to the manufacturer of said end product.

Auverdion makes no express or implied warranties whatsoever with respect to its functionality, operability, or use, including, without limitation, any implied warranties of merchantability, fitness for a particular purpose, or infringement. We expressly disclaim any liability whatsoever for any direct, indirect, consequential, incidental or special damages, including, without limitation, lost revenues, lost profits, losses resulting from business interruption or loss of data regardless of the form of action or legal theory under which the liability may be asserted, even if advised of the possibility or likelihood of such damages.

Life support policy: Use of auverdion products in life support equipment or equipment whose failure can reasonably be expected to result in injury or death is not permitted.

auverdion | 14

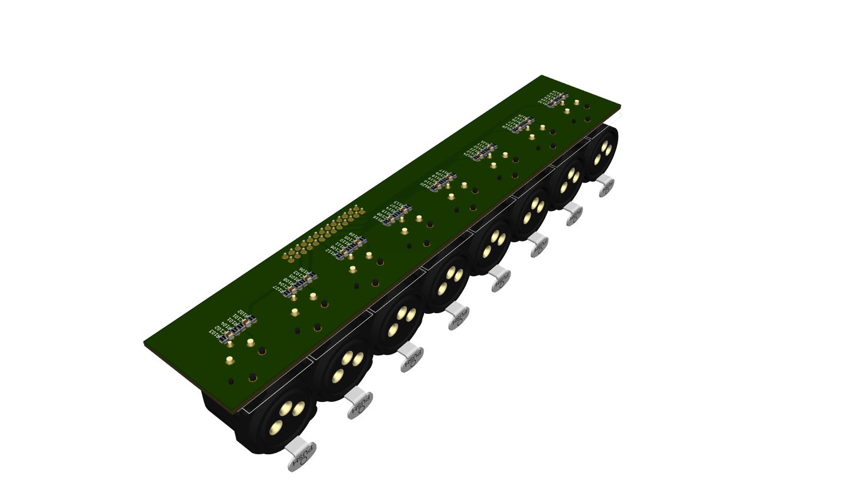
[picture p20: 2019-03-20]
ADDONS/AddOnB/KICAD/Board B/AddOnB-B2.png

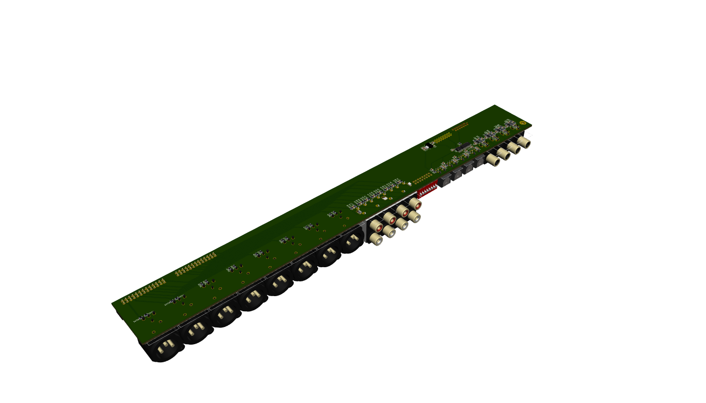
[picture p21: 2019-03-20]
ADDONS/AddOnB/KICAD/Board A/AddOnB-A2.png

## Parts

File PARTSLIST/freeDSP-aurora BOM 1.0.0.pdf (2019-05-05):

### freeDSP-aurora BOM rev 1.0.0

Reference Reference | Qty Qty | Footprint | Value1 | Value2 | Manufacturer | pn
C103 | 1 | C0805-X7R | 5n60 | 10% 50V X7R | Yageo | CC0805KRX7R9BB562
C101, C104, C111, C117, C119, C120, C122, C123, C125, C127, C132, C259, C260, C337, C360, C409, C410, C412, C414, C415, C502, C507, C508 | 23 | C0805-X7R | 10u0 | 20% 25V X5R | Murata Electronics North America | GRM21BR61E106MA73L
C102, C105, C109, C110, C118, C121, C124, C128, C129, C130, C131, C133, C134, C135, C136, C220, C230, C234, C242, C249, C261, C262, C264, C273, C274, C275, C276, C277, C278, C279, C280, C320, C328, C336, C344, C352, C361, C362, C363, C364, C365, C366, C367, C368, C369, C370, C371, C372, C373, C374, C375, C376, C377, C402, C403, C404, C405, C406, C407, C408, C411, C413, C501, C503, C506 | 65 | C0805-X7R | 100n | 5% 50V X7R | KEMET | C0805C104K5RACTU
C106 | 1 | C0805-X7R | 150p | 5% 50V C0G | KEMET | C0805C151J5GACTU
C107, C108 | 2 | C0805-X7R | 22p0 | 5% 50V C0G/NP0 | KEMET | C0805C220J5GACTU
C112, C113, C114, C137, C138, C203, C204, C211, C212, C217, C218, C219, C227, C228, C229, C233, C237, C238, C241, C247, C248, C255, C256, C269, C270, C301, C302, C309, C310, C314, C315, C321, C324, C325, C329, C330, C331, C340, C341, C345, C346, C347, C353, C356, C357 | 45 | RD2_D5_L11 | 100u | 20% 25V | Nichicon | UVY1E101MDD
C115, C116, C126 | 3 | RD3.5_D8_L14 | 330u | 20% 25V | Wurth Electronics Inc. | 860010474012
C201, C210, C225, C226, C240, C252, C267, C268 | 8 | C0805-X7R | 1n00 | 5% 50V PPS | Panasonic Electronic Components | ECH-U1H102JX5
C205, C206, C213, C214, C221, C222, C231, C232, C236, C243, C244, C246, C257, C258, C271, C272, C281, C282, C283, C284, C285, C286, C287, C288 | 24 | C0805-X7R | 100p | 5% 50V C0G/NP0 | KEMET | C0805C101J5GACTU
C202, C207, C208, C209, C215, C216, C223, C224, C235, C239, C245, C251, C253, C254, C265, C266 | 16 | C0805-X7R | 220p | 2% 50V PPS | Panasonic Electronic Components | ECH-U1H221GX5
C250 | 1 | C0805-X7R | 4u70 | 20% 25V X5R | Murata Electronics North America | GRM21BR61E475MA12L
C263, C401 | 2 | C0805-X7R | 10n0 | 10% 50V X7R | Yageo | CC0805KRX7R9BB103
C305, C306, C318, C319, C334, C335, C350, C351 | 8 | C0805-X7R | 27p0 | 5% 50V C0G/NP0 | KEMET | C0805C270J5GACTU
C307, C308, C322, C323, C338, C339, C354, C355 | 8 | C0805-X7R | 3n90 | 5% 16V PPS | Panasonic Electronic Components | ECH-U1C392JX5
C313 | 1 | C0805-X7R | 1u00 | 10% 16V X7R | Yageo | CC0805KKX7R7BB105

Reference | Qty | Footprint | Value1 | Value2 | Manufacturer | pn
C303, C304, C311, C312, C316, C317, C326, C327, C332, C333, C342, C343, C348, C349, C358, C359 | 16 | C0805-X7R | 470p | 2% 50V PPS | Panasonic Electronic Components | ECH-U1H471GX5
C416, C504 | 2 | C0805-X7R | 22u0 | 20% 10V X5R | Murata Electronics North America | GRM21BR61A226ME51L
C417, C418, C419, C420, C421, C422, C423, C424, C425, C426, C427, C428, C429, C430, C431, C432, C433, C434, C435, C436, C437, C438, C439, C440, C441 | 25 | C0402-X7R | 100n | 10% 10V X7R | Murata Electronics North America | GRM155R71A104KA01D
D401 | 1 | SOD123 | MBR120VLSFT | Schottky 20V 1 A | ON Semiconductor | MBR120VLSFT3G
FER101, FER102 | 2 | C0805-RES | 600R | @100MHz 600mA | Murata Electronics North America | BLM21AG601SN1D
IC101 | 1 | QFP72_10x10_EP | ADAU1452 | - | Analog Devices Inc. | ADAU1452WBCPZ
IC102 | 1 | SOIJ8_5.3x5.3mm_P1.27mm | DNP | 1Mbit | Microchip Technology | 25AA1024T-I/SM
IC103 | 1 | SOIC8_3.9x4.9mm_Pitch1.27mm | TLE2426ID | Spannungsrefere nz | Texas Instruments | TLE2426IDR
IC104 | 1 | SOT143 | ADM811TARTZ | Spannungsmonito r | Analog Devices Inc. | ADM811TARTZ-REEL
IC105, IC107 | 2 | SOT223 | LM1117MP-5.0 | LDO | Texas Instruments | LM1117MP-5.0/NOPB
IC106, IC409, IC502 | 3 | SOT223 | NCP1117LPST33 | LDO | ON Semiconductor | NCP1117LPST33T3G
IC201, IC202, IC203, IC204, IC206, IC207, IC208, IC209, IC301, IC302, IC303, IC304, IC306, IC307, IC308, IC309 | 16 | SOIC8_3.9x4.9mm_Pitch1.27mm | OPA1652AIDR | OpAmp | Texas Instruments | OPA1652AIDR
IC205 | 1 | QFN64_9x9mm_Pitch0.5mm_EP | AK5558VN | ADC | AKM Semiconductor Inc. | AK5558VN
IC305 | 1 | QFN48_7x7mm_Pitch0.5mm_EP | AK4458VN | DAC | AKM Semiconductor Inc. | AK4458VN
IC401 | 1 | SC-70-6 | NC7WZ07 | Noninverting Buffer | ON Semiconductor | NC7WZ07P6X
IC402 | 1 | SOT-363_SC-70-6 | NC7SZ175 | D-Type Flip-Flop with Asynchronous Clear | Texas Instruments | SN74LVC1G175DCKR
IC403 | 1 | TQFP-128_14x14mm_Pitch0.4mm_EP | XE216-512-TQ128 | xCore | XMOS | XE216-512-TQ128-C20
IC404 | 1 | MSOP-10_3x3mm_Pitch0.5mm | CS2100CP | Fractional-N Clock Multiplier | Cirrus Logic Inc. | CS2100CP-CZZ
IC405, IC406 | 2 | SC-70-6 | NC7SZ157 | 2-Input Non-Inverting Multiplexer | ON Semiconductor | NC7SZ157P6X
IC407 | 1 | SC70-5 | TLV70025 | 2.5V, 200mA | Texas Instruments | TLV70025DCKR
IC408 | 1 | SOIC8_3.9x4.9mm_Pitch1.27mm | IS25LP080D | 8Mb | ISSI, Integrated Silicon Solution Inc | IS25LP080D-JNLE
IC410 | 1 | SOT-23-5 | TLV62565 | 1.5A | Texas Instruments | TLV62565DBVR
IC501 | 1 | ESP32-WROOM-32U | ESP32-WROOM-32U | Module | Espressif Systems | ESP32-WROOM-32U
JP101 | 1 | HDR_01x02 | Jumper | - | Wurth Electronics Inc. | 61300211121
L401 | 1 | MCSDRH73B | 2u20 | 30% 4.5A 26 mOhm | Murata Power Solutions Inc. | 45222C
OSC401 | 1 | ASFL1 | 24M0 | - | Abracon LLC | ASFL1-24.000MHZ-EC-T

Q101 | 1 | TO-252-2 | STD2805 | PNP 60V 5A 150MHz 15W | STMicroelectron ics | STD2805T4
R101, R102, R104, R105, R407 | 5 | R_Array_Convex_4x0603 | 33R0 | 5% 62,5mW | Yageo | TC164-JR-0733RL
R103, R114, R410 | 3 | C0805-RES | 1K00 | 1% 0.125W Thick | Yageo | RC0805FR-071KL
R106 | 1 | C0805-RES | 4K32 | 1% 0.125W Thick | Yageo | RC0805FR-074K32L
R108 | 1 | C0805-RES | 100R | 1% 0.125W Thick | Yageo | RC0805FR-07100RL
R109, R239, R402, R404, R408, R409, R411, R412 | 8 | C0805-RES | 33R0 | 1% 0.125W Thick | Yageo | RC0805FR-0733RL
R110, R111, R416, R417 | 4 | C0805-RES | 2K00 | 1% 0.125W Thick | Yageo | RC0805FR-072KL
R107, R112, R113, R401, R405, R406, R413, R414, R501 | 9 | C0805-RES | 10K0 | 1% 0.125W Thick | Yageo | RC0805FR-0710KL
R115, R374, R375, R376, R377, R378, R379, R380, R381, R382, R383, R384, R385, R386, R387, R388, R389, R418 | 18 | C0805-RES | 100K | 1% 0.125W Thick | Yageo | RC0805FR-07100KL
R116 | 1 | C0805-RES | 560R | 1% 0.125W Thick | Yageo | RC0805FR-07560RL
R203, R204, R207, R208, R221, R222, R229, R230, R241, R243, R250, R252, R255, R256, R259, R260 | 16 | C0805-RES | 10K0 | 1% 0.25W Thin | Stackpole Electronics Inc. | RNCP0805FTD10K0
R201, R202, R209, R210, R219, R220, R231, R232, R240, R244, R249, R253, R254, R261, R262, R273 | 16 | C0805-RES | 6K80 | 0.5% 0.125W Thin | Panasonic Electronic Components | ERA-6AED682V
R205, R206, R211, R223, R224, R242, R248, R251, R257, R258, R268, R270, R272, R276, R278, R280 | 16 | C0805-RES | 10R0 | 1% 0.25W Thin | Stackpole Electronics Inc. | RNCP0805FTD10R0
R218, R228, R238, R246, R323, R334, R349, R356 | 8 | C0805-RES | 20R0 | 1% 0.125W Thick | Yageo | RC0805FR-0720RL
R212, R233, R234, R245, R247, R263, R264, R265, R266, R267, R269, R271, R274, R275, R277, R279 | 16 | C0805-RES | 2K20 | 0.5% 0.125W Thin | Panasonic Electronic Components | ERA-6AED222V
R301, R303, R311, R313, R317, R319, R328, R330, R335, R337, R345, R347, R352, R354, R368, R370 | 16 | C0805-RES | 4K42 | 0.5% 0.1W Thin | Susumu | RR1220P-4421-D-M
R302, R304, R315, R316, R318, R320, R332, R333, R336, R338, R350, R351, R353, R355, R372, R373 | 16 | C0805-RES | 3K40 | 0.5% 0.1W Thin | Susumu | RR1220P-3401-D-M
R305, R306, R312, R314, R321, R322, R329, R331, R339, R340, R346, R348, R357, R358, R369, R371 | 16 | C0805-RES | 150R | 1% 0.25W Thin | Stackpole Electronics Inc. | RNCP0805FTD150R
R307, R308, R309, R310, R324, R325, R326, R327, R341, R342, R343, R344, R364, R365, R366, R367 | 16 | C0805-RES | 4K70 | 1% 0.125W Thin | Yageo | RT0805FRE074K7L
R403 | 1 | C0805-RES | 4R70 | 1% 0.125W Thick | Yageo | RC0805FR-074R7L
R415 | 1 | C0805-RES | 43R2 | 1% 0.125W Thick | Panasonic Electronic Components | ERJ-6ENF43R2V
R419 | 1 | C0805-RES | 80K6 | 1% 0.125W Thick | Yageo | RC0805FR-0780K6L
R420 | 1 | C0805-RES | 120K | 1% 0.125W Thick | Yageo | RC0805FR-07120KL

SW501 | 1 | SW_SPST_B3U-1000P | B3U-1000P | SWITCH TACTILE SPST-NO 0.05A 12V | Omron Electronics Inc-EMC Div | B3U-1000P
X101 | 1 | MM-14G | MicroMatch-14 | - | TE Connectivity AMP Connectors | 1-215079-4
X102 | 1 | HDR_02x08 | HDR_02x08 | - | Sullins Connector Solutions | PRPC008DAAN-RC
X103, X503 | 2 | Molex_PicoBlade_530470310 | PB-01x03 | - | Molex, LLC | 530470310
X104 | 1 | MM-10G | MicroMatch-10 | - | TE Connectivity AMP Connectors | 1-215079-0
X105 | 1 | Microfit3_43045-0428 | MicroFit3 02x02 | - | Molex, LLC | 430450428
X106 | 1 | HDR_01x02 | HDR-01x02 | - | Wurth Electronics Inc. | 61300211121
X201, X301 | 2 | IDC26 | IDC26 | - | Bud Industries | BC-32677
X401 | 1 | PinHeader_1x05_P2.54mm_Vertical | HDR-01x05 | - | Sullins Connector Solutions | PRPC005SAAN-RC
X402 | 1 | HDR_02x10 | HDR-02x10 | - | Sullins Connector Solutions | PRPC010DAAN-RC
X501 | 1 | Molex_KK254_0022032041 | KK254-01x04 | - | Molex, LLC | 22232041
X502 | 1 | Molex_PicoBlade_530470510 | PB-01x05 | - | Molex, LLC | 530470510
X504 | 1 | PinHeader_1x06_P2.54mm_Vertical | HDR-01x06 | - | Sullins Connector Solutions | PRPC006SAAN-RC
Y101 | 1 | Crystal-3.2x2.5 | 24M576 | - | EPSON | FA-238 24.5760MB-K3
| 1 | | RF ANT 2.4GHZ | WHIP TILT CABLE | PulseLarsen Antennas | W1049B050

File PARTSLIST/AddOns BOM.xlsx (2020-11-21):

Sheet: AddOnA
AddOn A rev 1.0.0
Reference | Qty | Footprint | Value1 | Value2 | Manufacturer | pn
B1, B2 | 2 | Montagewinkel
C17 | 1 | C0805-X7R | 10n0 | 10% 50V X7R | Yageo | CC0805KRX7R9BB103
C5, C6, C101 | 3 | C0805-X7R | 100p | 5% 50V C0G/NP0 | Kemet | C0805C101J5GACTU
C1, C2, C3, C4, C7, C24, C109, C113 | 8 | C0805-X7R | 100n | 5% 50V X7R | Kemet | C0805C104K5RACTU
D1 | 1 | D_0603_1608Metric |  |  | Littelfuse Inc. | PESD0603-240
IC1 | 1 | SOT23-5 |  |  | ON Semiconductor | FIN1002M5X
IC6 | 1 | SOIC8_3.9x4.9mm_Pitch1.27mm |  |  | Texas Instruments | PCA9536DR
IC101 | 1 | SOIC-16_3.9x9.9mm_P1.27mm |  |  | Texas Instruments | SN74HC251DR
L101 | 1 | C0805-X7R |  |  | Taiyo Yuden | LBR2012T470K
P1 | 1 | RK09K1110-20 |  |  | Alps | RK09K1110A0J
R1 | 1 | C0805-RES | 91R0 | 1% 0.125W Thick | Yageo | RC0805FR-0791RL
R2 | 1 | C0805-RES | 820R | 1% 0.125W Thick | Yageo | RC0805FR-07820RL
R3, R4, R5 | 3 | C0805-RES | 470R | 1% 0.125W Thick | Yageo | RC0805FR-07470RL
R6, R29 | 2 | C0805-RES | 33R0 | 1% 0.125W Thick | Yageo | RC0805FR-0733RL
R8, R10 | 2 | C0805-RES | 100K | 1% 0.125W Thick | Yageo | RC0805FR-07100KL
R11, R12, R13, R14 | 4 | C0805-RES | 47K0 | 1% 0.125W Thick | Yageo | RC0805FR-0747KL
R25 | 1 | C0805-RES | 10K0 | 1% 0.125W Thick | Yageo | RC0805FR-0710KL
R101, R102 | 2 | C0805-RES | 68R0 | 1% 0.125W Thin | Panasonic Electronic Components | ERA-6AED680V
R7, R9, R117 | 3 | C0805-RES | 100R | 1% 0.25W Thin | Stackpole Electronics Inc | RNCP0805FTD100R
R118 | 1 | C0805-RES | 220K | 1% 0.125W Thick | Yageo | RC0805FR-07220KL
SW1, SW2 | 2 | GEMINI_A |  |  | TE Connectivity Alcoswitch | A203MD9AB04
X1, X3 | 2 | PJRAN1X1U01AUX |  |  | Switchcraft Inc. | PJRAN1X1U01AUX
X2 | 1 | NC3FAH |  |  | Neutrik | NC3FAH1
X4 | 1 | Molex_PicoBlade_530470310 |  |  | Molex | 530470310
X5 | 1 | MM-14G | MicroMatch-14 | - | TE Connectivity AMP Connectors | 1-215079-4
X6 | 1 | IDC2x8_Pitch2.54mm |  |  | On Shore Technology Inc. | 302-S161
X7 | 1 | PLT133_T10W |  |  | Everlight Electronics Co Ltd | PLT133/T10W
X8 | 1 | USB_B | USB_B | horizontal | On Shore Technology Inc. | USB-B1HSB6
X9 | 1 | PinHeader_1x05_P2.54mm_Vertical |  |  | Sullins Connector Solutions | PRPC005SAAN-RC
X101 | 1 | NC3MAH |  |  | Neutrik | NC3MAH-0
X110 | 1 | PLR135_T10 |  |  | Everlight Electronics Co Ltd | PLR135/T10
X114, X115 | 2 | IDC26 | IDC26 |  | Bud Industries | BC-32677

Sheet: AddOnB
AddOn B rev 1.0.0
Reference | Qty | Footprint | Value1 | Value2 | Manufacturer | pn
Board A
C17, C18, C19, C20 | 4 | C0805-X7R | 10n0 | 10% 50V X7R | Yageo | CC0805KRX7R9BB103
C21, C23 | 2 | C0805-X7R | 10u0 | 20% 25V X5R | Murata Electronics North America | GRM21BR61E106MA73L
C101, C102, C103, C104, C105, C106, C107, C108 | 8 | C0805-X7R | 100p | 5% 50V C0G/NP0 | KEMET | C0805C101J5GACTU
C1, C2, C3, C4, C5, C6, C7, C8, C9, C10, C11, C12, C13, C14, C15, C16, C22, C24, C109, C110, C111, C112, C113 | 23 | C0805-X7R | 100n | 5% 50V X7R | KEMET | C0805C104K5RACTU
D1, D2, D3, D4 | 4 | D_0603_1608Metric |  |  | Littelfuse Inc. | PESD0603-240
IC1, IC2, IC3, IC4 | 4 | SOT23-5 |  |  | ON Semiconductor | FIN1002M5X
IC5 | 1 | SOT223 | NCP1117LPST33 |  | ON Semiconductor | NCP1117LPST33T3G
IC6 | 1 | SOIC8_3.9x4.9mm_Pitch1.27mm |  |  | Texas Instruments | PCA9536DR
IC101 | 1 | SOIC-16_3.9x9.9mm_P1.27mm |  |  | Texas Instruments | SN74HC251DR
L101, L102, L103, L104 | 4 | C0805-X7R |  |  | Taiyo Yuden | LBR2012T470K
R1, R7, R13, R19 | 4 | C0805-RES | 91R0 | 1% 0.125W Thick | Yageo | RC0805FR-0791RL
R2, R8, R14, R20 | 4 | C0805-RES | 820R | 1% 0.125W Thick | Yageo | RC0805FR-07820RL
R3, R4, R5, R9, R10, R11, R15, R16, R17, R21, R22, R23 | 12 | C0805-RES | 470R | 1% 0.125W Thick | Yageo | RC0805FR-07470RL
R6, R12, R18, R24, R29 | 5 | C0805-RES | 33R0 | 1% 0.125W Thick | Yageo | RC0805FR-0733RL
R25, R26, R27, R28 | 4 | C0805-RES | 10K0 | 1% 0.125W Thick | Yageo | RC0805FR-0710KL
R101, R102, R103, R104, R105, R106, R107, R108, R109, R110, R111, R112, R113, R114, R115, R116 | 16 | C0805-RES | 68R0 | 1% 0.125W Thin | Panasonic Electronic Components | ERA-6AED680V
R117, R119, R121, R123, R125, R127, R129, R131 | 8 | C0805-RES | 100R | 0.5% 0.100W Thin | Susumu | RR1220P-101-D
R118, R120, R122, R124, R126, R128, R130, R132 | 8 | C0805-RES | 220K | 1% 0.125W Thick | Yageo | RC0805FR-07220KL
SW101 | 1 | KAS2108E |  |  | E-Switch | KAS2108ET
X1, X2, X3, X4 | 4 | PJRAN1X1U01AUX |  |  | Switchcraft Inc. | PJRAN1X1U01AUX
X5 | 1 | MM-14G | MicroMatch-14 |  | TE Connectivity AMP Connectors | 1-215079-4
X6 | 1 | IDC2x8_Pitch2.54mm |  |  | On Shore Technology Inc. | 302-S161
X101, X102, X103, X104, X105, X106, X107, X108 | 8 | NC3MAH |  |  | Neutrik | NC3MAH-0
X109 | 1 | PJRAS4X2U01 |  |  | Switchcraft Inc. | PJRAS4X2U01AUX
X110, X111, X112, X113 | 4 | PLR135_T10 |  |  | Everlight Electronics Co Ltd | PLR135/T10
X114, X115 | 2 | IDC26 | IDC26 |  | Bud Industries | BC-32677
 | 5 |  | IDC26 Connector |  | On Shore Technology Inc. | 101-266
 | 2 |  | IDC16 Connector |  | On Shore Technology Inc. | 101-166
 | 2 |  | MicroMatch-14 Connector |  | TE Connectivity AMP Connectors | 1-215083-4
Board B
C101, C102, C103, C104, C105, C106, C107, C108, C109, C110, C111, C112, C113, C114, C115, C116 | 16 | C0805-X7R | 100p | 5% 50V C0G/NP0 | Kemet | C0805C101J5GACTU
R101, R103, R105, R107, R109, R111, R113, R115, R117, R119, R121, R123, R125, R127, R129, R131 | 16 | C0805-RES | 100R | 0.5% 0.100W Thin | Susumu | RR1220P-101-D
R102, R104, R106, R108, R110, R112, R114, R116, R118, R120, R122, R124, R126, R128, R130, R132 | 16 | C0805-RES | 100K | 1% 0.125W Thick | Yageo | RC0805FR-07100KL
R133, R135, R136, R138, R139, R141, R142, R144, R145, R147, R148, R150, R151, R153, R154, R156 | 16 | C0805-RES | 0R00 | 0.5% 0.125W Thick | Yageo | RC0805JR-070RL
R134, R137, R140, R143, R146, R149, R152, R155 | 8 | C0805-RES | DNP
X101, X102, X103, X104, X105, X106, X107, X108 | 8 | NC3FAH | NC3FAH |  | Neutrik | NC3FAH1
X109 | 1 | IDC26 | IDC26 |  | Bud Industries | BC-32677

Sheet: AddOnD
AddOn D rev 1.0.0
Reference | Qty | Footprint | Value1 | Value2 | Manufacturer | pn
Board A
R101, R102, R103, R104, R105, R106, R107, R108, R109, R110, R111, R112, R113, R114, R115, R116 | 16 | C0805-RES | 68R0 | 1% 0.125W Thin | Panasonic Electronic Components | ERA-6AED680V
X101, X102, X103, X104, X105, X106, X107, X108 | 8 | NC3MAH | NC3MAH |  | Neutrik | NC3MAH-0
X115 | 1 | IDC26 | IDC26 |  | Bud Industries | BC-32677
Board B
C101, C102, C103, C104, C105, C106, C107, C108, C109, C110, C111, C112, C113, C114, C115, C116 | 16 | C0805-X7R | 100p | 5% 50V C0G/NP0 | Kemet | C0805C101J5GACTU
R101, R103, R105, R107, R109, R111, R113, R115, R117, R119, R121, R123, R125, R127, R129, R131 | 16 | C0805-RES | 100R | 1% 0.25W Thin | Susumu | RR1220P-101-D
R102, R104, R106, R108, R110, R112, R114, R116, R118, R120, R122, R124, R126, R128, R130, R132 | 16 | C0805-RES | 100K | 1% 0.125W Thick | Yageo | RC0805FR-07100KL
R133, R135, R136, R138, R139, R141, R142, R144, R145, R147, R148, R150, R151, R153, R154, R156 | 16 | C0805-RES | 0R00 | 0.5% 0.125W Thick | Yageo | RC0805JR-070RL
R134, R137, R140, R143, R146, R149, R152, R155 | 8 | C0805-RES | DNP
X101, X102, X103, X104, X105, X106, X107, X108 | 8 | NC3FAH | NC3FAH |  | Neutrik | NC3FAH1
X109 | 1 | IDC26 | IDC26 |  | Bud Industries | BC-32677

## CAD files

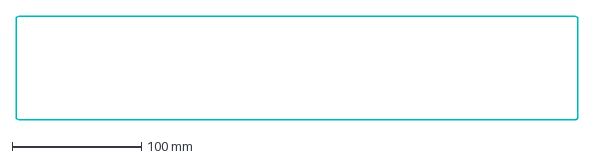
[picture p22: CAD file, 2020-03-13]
ADDONS/AddOnB/Case Plates/2HE Aussenkontur.dxf
435.0 x 80.0 mm

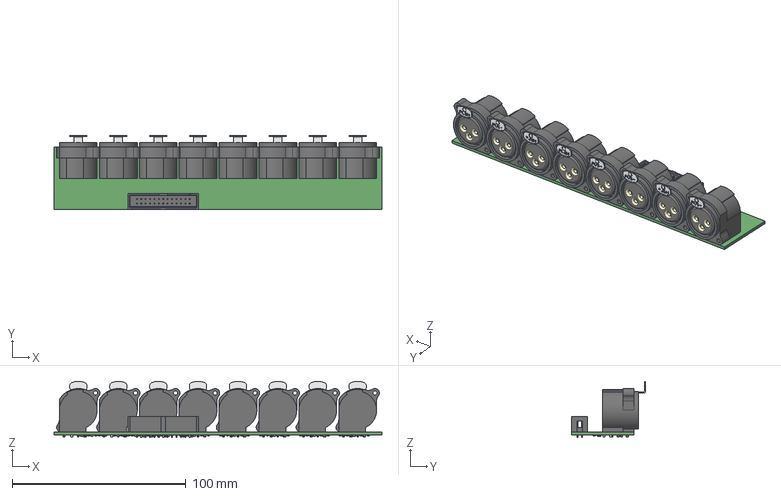
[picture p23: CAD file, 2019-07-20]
ADDONS/AddOnB/KICAD/Board B/AddOnB.step
189.0 x 42.9 x 32.4 mm

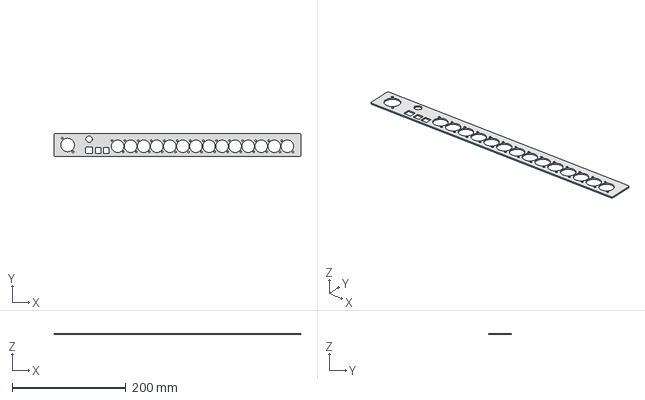
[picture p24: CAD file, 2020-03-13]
ADDONS/AddOnC/Case Plates/Panel-C+Powercon.stp
435.0 x 40.0 x 2.00 mm

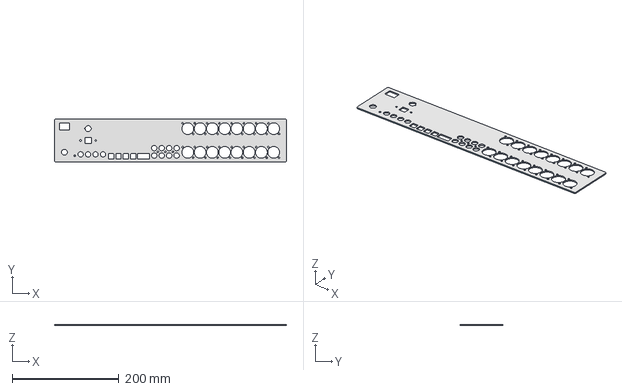
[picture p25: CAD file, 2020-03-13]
ADDONS/AddOnB/Case Plates/Panel-B+12v.stp
435.0 x 80.0 x 2.00 mm

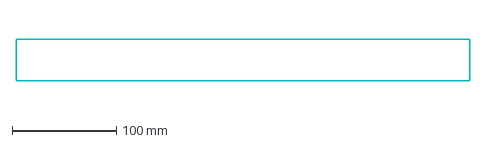
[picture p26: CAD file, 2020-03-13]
ADDONS/AddOnD/Case Plates/Aussenkontur 1HE.dxf
435.0 x 40.0 mm

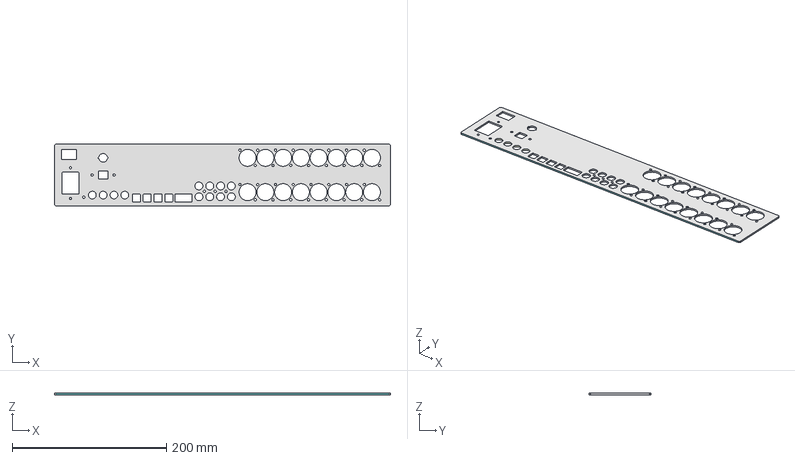
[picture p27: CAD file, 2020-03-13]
ADDONS/AddOnB/Case Plates/Panel-B+Kalt.stp
435.0 x 80.0 x 2.00 mm

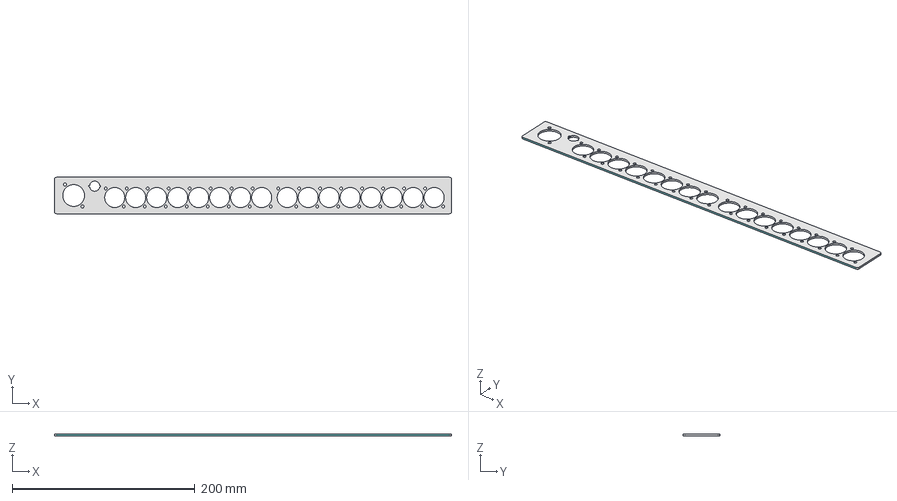
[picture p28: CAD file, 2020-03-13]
ADDONS/AddOnD/Case Plates/Panel-D+Powercon.stp
435.0 x 40.0 x 2.00 mm

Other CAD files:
ADDONS/AddOnD/Case Plates/Panel-D+12v.stp
ADDONS/AddOnC/Case Plates/Panel-C+12v.stp
ADDONS/AddOnC/Case Plates/Panel-C+Kalt.stp
ADDONS/AddOnB/Case Plates/Panel-B+Powercon.stp
ADDONS/AddOnB/Case Plates/Panel-B+12v.dxf
ADDONS/AddOnB/Case Plates/Panel-B+12v.stl
ADDONS/AddOnB/Case Plates/Panel-B+Kalt.dxf
ADDONS/AddOnB/Case Plates/Panel-B+Kalt.stl
ADDONS/AddOnB/Case Plates/Panel-B+Powercon.dxf
ADDONS/AddOnB/Case Plates/Panel-B+Powercon.stl
ADDONS/AddOnC/Case Plates/Panel-C+12v.dxf
ADDONS/AddOnC/Case Plates/Panel-C+12v.stl
ADDONS/AddOnC/Case Plates/Panel-C+Kalt.dxf
ADDONS/AddOnC/Case Plates/Panel-C+Kalt.stl
ADDONS/AddOnC/Case Plates/Panel-C+Powercon.dxf
ADDONS/AddOnC/Case Plates/Panel-C+Powercon.stl
ADDONS/AddOnD/Case Plates/Panel-D+12v.dxf
ADDONS/AddOnD/Case Plates/Panel-D+12v.stl
ADDONS/AddOnD/Case Plates/Panel-D+Powercon.dxf
ADDONS/AddOnD/Case Plates/Panel-D+Powercon.stl

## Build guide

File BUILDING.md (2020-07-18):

# Software build instructions

If you just want to use the Aurora in your project, please use the pre-built releases instead of building your own firmware (this is **not** necessary for creating your own plugins).
But if you want to assist with development by contributing code, you will find the Aurora actually runs three firmwares:

1. **ESP32**: Runs the primary program which controls everything else, and offers the WiFi interface. Probably the most interesting of the bunch. See [this document](SOURCES/WEBAPP/ESP32/README.md) for more details and how to build.
2. **ADAU1452**: The DSP firmware is build using SigmaStudio. The firmware is stored on the ESP32 as part of the installed plugin.
3. **XMOS**: The USB interface comes with a 7.1 firmware pre-installed; if you want to change this, you need to build your own firmware.

Please note that a complete Aurora Plugin consists of a DSP firmware image, an associated control website and some meta-data.
The actual XMOS and ESP32 firmware are not modified by plugins.

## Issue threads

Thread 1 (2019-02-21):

Connect ESP32 to a Serial Data port to Receive from the DSP

jjloud, 2019-02-21:
The ESP32 is connected to the ADAU1452 in one direction only. The ESP32 can only send data to the DSP, the DSP can not send data to the ESP32. It's worth while to connect the ESP32 to also receive data from the DSP. This would enable the device to be a Bluetooth Source (in addition to what it is now being a "Sink"). It also adds the possibility of it to become a Bluetooth/Wifi "Transceiver" so you can send audio data to a receiving device.

Just something to think about. Thank you for your hard work on this project.

dspverden, 2019-08-30:
There are no pins free on the ESP32 that could be used for this.

Closed 2019-08-30.

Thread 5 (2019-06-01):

power supply issue

bob808, 2019-06-01:
I see that the DSP/ADC/DAC chips are powered from the single 3.3V supply (IC106), provided by a linear regulator that drops it from 12V.
ADAU1452 can draw 500mA in full program. Just the DSP means the small regulator will have to dissipate 4.3W.
That thing will go like popcorn.
You need a lower voltage on its input, or use a switching regulator. This is in not safe as it is now.
IC107 as well is pretty loaded at the quiescent current of the opamps + analog stages of ADC/DAC. It dissipates 1.5W with no work from the opamps.
This board should be run at max 6-7V as it is now. That should work.

dspverden, 2020-03-13:
This has been addressed already. Please refer to the documentation.

Closed 2020-03-13.

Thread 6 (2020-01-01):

webOTA fails

dspverden, 2020-01-01:
We have seen some strange behavior with the webOTA feature the ESP SDK from espressif. After an update of the firmware via webOTA the board does not come back with WiFi access.
Meanwhile a workaround is to update via the Serial Port as described in the user manual.
So far only Windows machines seem to be involved in this issue.

dspverden, 2020-03-13:
Has been solved in firmware version 2.0.0

Closed 2020-03-13.

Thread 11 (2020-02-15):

full amplitude output

notanumba, 2020-02-15:
concerns: auverdionControl 1.2.1 and firmware 1.2.1 with 8 Channel Plugin

Hi,
i am using the above fw and control on Win10 64bit on a Laptop. I logged into the DSP-AccessPoint via wifi. I configured the DSP for some time successfully.

To my setup:
I am using selfmade 3-way speakers w/o any passive filter network - the DSP works as pre-amp for 6x170W power amplifiers and then on the 2x3 chassis (SUB, MID, HIGH). I am aware of the fact, that its critical for the chassis if something in the pathway goes wrong, but i used resistors until i was sure the setup works flawless. I had it nicely running for some weeks now. And a little tweek should be done today - bad idea: i fried (literally burned) my tweeter :(

It seems the DSP has a problem with the following situation:

- boot system on laptop
- start auverdionControl 1.2.1
- connect to the DSP
- make some settings - maybe even save them to the board - everything works
- (!) let the laptop go to sleep / hibernate with open auverdionControl
- (eventually switch off/on the DSP - i cant remember doing it)
- wake the laptop - auverdionControl should offer to read the DSP settings (green arrows upper right)
- click the green arrows
- the DSP outputs maximum noise and it seems nonfiltered (low frequencies on all outputs, and on tweeter)

I am not very familiar with the board now, but here is my opinion:
The DSP got confused in this - for sure dumb - scenario. But anyways - the dsp or auverdioncontrol should realize this, to prevent damage.

1st priority for further development should be a safe usage while playing with the settings. If i am too blind and set something wrong (e.g. lowpass for tweeter) it`s my own stupidity. But the DSP should never play with wrong settings which happened in my case.

Suggestion:
- Before changing any setting in the DSP, volume for the affected chan to -80dB
- If there is no ACK from DSP -> Errormsg
- Write parameters to DSP and Double check data consistency in auverdioncontrol and the DSP
- If there is no consistency -> volume for all chan to -80dB, Errormsg
- Any other safety mechanism (watchdog for DSP?) should be prioritized in development

... out for buying new tweeters....

notanumba

EDIT 1:
After trying to access the DSP aofter power down / power up with the control utility, it took very long to read out all parameters of the  8 Channel Plugin (approx 4 minutes). I tried to write a previously saved file, and got errors (not an ACK from DSP) and got stuck. Trying to rewrite fw via webota now.

EDIT 2:
BTW: I am sure the noise was self generated by the DSP itself - no signal in Analog1/2 was inserted in the 8 Channel Plugin.

Edit 3:
Instead of Cinema Plugin mentioned in earlier post version i used the default  8 Channel plugin

dspverden, 2020-03-13:
Firmware version v2.0.0 introduces some consistency checks.

Raphael

Closed 2020-03-13.

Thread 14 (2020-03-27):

Cannot connect to aurora

gdimopoulos, 2020-03-27:
I'm trying to connect to Aurora for the first time. I successfully pushed the WiFi configuration and the Aurora connected to my network. When I try the "read all parameters" in auverdionControl it fails. Same thing with webOTA when trying with a browser.

dspverden, 2020-03-27:
You should provide more detailed infos. With this limited description nobody can help you.
because you have to be able to configure the WiFi I assume you have been able to connect to the access point. Thus, you should check first wether you can do the read all via the access point connection.
The most common problems with the WiFi in a local WiFi networks are issues with firewalls, wrong router settings, wrong IP configuration in auverdionControl. Many problems are caused by Windows or AntiVirus software.
Therefore, we recommend to update to firmware 2.0.1 and use the web application instead.

gdimopoulos, 2020-03-27:
Sorry, you are right. The Aurora firmware version is 1.0.1. No add-ons or plugins. I'm running auverdionControl 1.0.1 on MacOS Catalina.

I did enable the AP mode and tried to connect but with the same result.

dspverden, 2020-03-27:
I am still wondering what you did.
1) You said that you have been able to set the WiFi credentials and that it connects to your WiFi.
Can you verify that? Is it listed with a valid IP in our router?
2) Can you show a picture of your settings dialog? I think there you did a wrong configuration.
3) What is the exact error message of auverdionControl?
4) When trying to read parameters in AP mode, did you switch auverdionControl to AP mode?
5) If yes for 4) did you connect your mac to AP-freeDSP-aurora?

I strongly recommend to update to 2.0.1. Please refer to the documentation for how to do that.

gdimopoulos, 2020-03-28:
Problem solved, after a couple of reboots I was able to connect with the auverdionControl and push different configurations. I also managed to upgrade to 2.0.1 as you recommended. Now everything works fine.

Thanks a lot for your help.

Closed 2020-03-28.

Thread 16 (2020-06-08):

Loud noise when configuring DSP via webinterface

archi, 2020-06-08:
In case this is relevant, my DSP plugin is a modified 8channels: All channels have their maximum delay cut in half (to make some space on the device); but only channels 1&2 have their maximum number of PEQ bands increased from 10 to 15 - by editing the existing PEQ. Else, it's the same, no new blocks added, none removed. Only output channels 1&2 are connected.

Anyhow: When making changes to my DSP configuration in the web interface, e.g. adjusting the parameters for the low shelv on channel 1, **my loudspeakers on both channels make a deep and loud noise**. Sounds a lot like a fully driven output signal, e.g. rather unhealthy. If the Aurora was connected directly to the power amplifier (e.g. as preamp or active crossover), I am pretty sure this would cause damage to [some of] my speakers.

I work around this by muting the preamp, but since I plan to ultimately replace the preamp with the Aurora, this isn't an option in the long run. Not sure if relevant, but I'm currently connecting my "non-balanced" preamp directly to the board (pin assignment as you instructed me, double checked).

My power supply should be pretty stable at 7.20V DC, even with 1.5A dummy load. So I wouldn't expect an intermittent brown out in the DAC to cause this. More likely: I suppose some internal reset in the DSP to be the culprit. So I'd suggest muting the DAC via I2C while the DSP is reconfigured, this could avoid this kind of issue. E.g.: Mute DAC, wait a few ms, reconfigure the DSP, wait a few ms, unmute the DAC (if I remember the AKM datasheet correctly, it's a soft mute with some configurable transient time).
Any active audio stream briefly drops out anyway, so adding a few ms of additional silence shouldn't make a real difference.

If this only affects some DSP plugins (e.g. due to my channels having a different processing time from the modified PEQ bands?), this could be toggled using the HTTP API (I think "enabled" would be a sane default?).

I did not check the ESP32 code, at least not in great detail. So I am not sure how easy/feasible this is, but didn't want to withhold this potential source of trouble from you ;-)

archi, 2020-06-09:
Ha, the source say the DAC is already muted on every HTTP/JSON call. Hm... if you have any idea what I can try to debug, let my now. I only have an old [HM 312 oscilloscope](https://i.ebayimg.com/images/g/y4YAAOSwAbBe1lWw/s-l1600.jpg), so that's a little bit limited; but I can do "auditive" tests with my 5$ sacrificial speaker.

(Also: Switching to German is perfectly alright with me ;-))

dspverden, 2020-06-09:
Hi,

from your description I read that you have modified the 8channels plugin. Does the unmodified plugin produce the noise, too? Or does only the modified one make that noise?
If that is the case you may have to double check that alle the addresses are changed correctly (read it from params.ini) and that the GUI elements of the HTML page point to the right filter block.

archi, 2020-06-12:
I played around a bit, and I think the PEQ is at fault. I have to use some rather big gains (up to 18dB), and those seem to cause artifacts on DSP reconfigure; at least the boards output produces some ugly DC (7s video from my scope, just toggling the bypass of some control: https://photos.app.goo.gl/sewJ2kZ3popBjks38)

By manually entering the HP+PEQ settings into the vanilla 8channels plugin I could reproduce it. As a "solution" I now added a delay(500) to `softUnmuteDAC`. Together with the other 500ms delay that's in front of virtually every call to `softMuteDAC`, every change now produces ~1s of silence, but I think that's better than a blown tweeter.

zas, 2020-07-22:
@archi: which code did you change and how to fix your issue? I'm curious about delay for unmute.

archi, 2020-07-22:
As said above, but I can commit it to my branch after work ;)

zas, 2020-07-23:
> As said above, but I can commit it to my branch after work ;)

Actually you could prepare a PR against the current main repo. I guess the delay is applied after the unmute command, so it would be in sync with what I have done for mute in https://github.com/freeDSP/freeDSP-aurora/pull/35

dspverden, 2020-11-07:
Fixed: 58badc2
Pull request #56 is the fix.

Closed 2020-11-07.

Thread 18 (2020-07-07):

aurora.ino:writeSettings: potential attempt to close non-opened file

zas, 2020-07-07:
If `fileSettings` failed to open, trying to close it may lead to an error

https://github.com/freeDSP/freeDSP-aurora/blob/21276bfe22873ccbef2ed4d0ad9af257ecf8831c/SOURCES/WEBAPP/ESP32/aurora/aurora.ino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

zas, 2020-07-07:
Same issue at https://github.com/freeDSP/freeDSP-aurora/blob/21276bfe22873ccbef2ed4d0ad9af257ecf8831c/SOURCES/WEBAPP/ESP32/aurora/aurora.ino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

zas, 2020-07-08:
Related code isn't in develop branch anymore, closing.

Closed 2020-07-08.

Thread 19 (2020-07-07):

aurora.ino:handlePostInputJson: Invalid use of http code 404 in case of failed deserialization

zas, 2020-07-07:
https://github.com/freeDSP/freeDSP-aurora/blob/21276bfe22873ccbef2ed4d0ad9af257ecf8831c/SOURCES/WEBAPP/ESP32/aurora/aurora.ino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

Imho, it would be more appropriate to use http error code 400 with a meaningful message, perhaps something like.

```
request->send( 400, "text/plain", err.c_str());
```

zas, 2020-07-07:
Same issue at https://github.com/freeDSP/freeDSP-aurora/blob/21276bfe22873ccbef2ed4d0ad9af257ecf8831c/SOURCES/WEBAPP/ESP32/aurora/aurora.ino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
https://github.com/freeDSP/freeDSP-aurora/blob/21276bfe22873ccbef2ed4d0ad9af257ecf8831c/SOURCES/WEBAPP/ESP32/aurora/aurora.ino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
https://github.com/freeDSP/freeDSP-aurora/blob/21276bfe22873ccbef2ed4d0ad9af257ecf8831c/SOURCES/WEBAPP/ESP32/aurora/aurora.ino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

zas, 2020-07-08:
Related code doesn't exist anymore in develop branch, so closing.

dspverden, 2020-07-18:
Fixed here: f833d43

Closed 2020-07-18.

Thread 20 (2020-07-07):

Suggestion: use rotary encode to select digital inputs

zas, 2020-07-07:
I don't know what's planned for rotary encoder, but it would be great to have the option to use it as source selector.

With push button and addon B, it could be:

- normal position, select between digital inputs
- in pushed position, select presets

Together with volume potentiometer, it'd pretty near usual preamp features.

Of course an alternative use is as volume controller. Various options should be offered by default imho.

zas, 2021-12-12:
https://github.com/freeDSP/freeDSP-aurora/blob/681eaee9fcaf23816395fc31fa001ef69c9ea5c2/SOURCES/WEBAPP/js/aurora.js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 is the code switching inputs inside the web interface

For AddonB, server side it is handled by https://github.com/freeDSP/freeDSP-aurora/blob/0c6edf79fcab260e279281e42e99ac09a16ecc5e/SOURCES/WEBAPP/ESP32/aurora/web.cpp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

From that, I'm not sure how to proceed, I don't know enough about addons internals & input configuration.

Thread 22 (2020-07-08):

aurora.ino: filename capitalization mismatch ak4458.h vs AK4458.h

zas, 2020-07-08:
https://github.com/freeDSP/freeDSP-aurora/blob/21276bfe22873ccbef2ed4d0ad9af257ecf8831c/SOURCES/ESP32/aurora/aurora.ino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

`aurora.ino` tries to include headers `AK4458.h` and `AK5558.h` but files are named `ak4458.h` and `ak5558.h`, this will cause problems on case-sensitive filesystems (ext3/4 on linux), but will not raise any error on non-case-sensitive filesystems (win).

On Linux, using ArduinoIDE, this leads to a `file not found` error.

Closed 2020-07-11.

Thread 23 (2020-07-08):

Current documentation format (Apple Pages) do not ease contributions

zas, 2020-07-08:
Using a proprietary and non-textual format for documentation prevents people to provide patches and to review changes.

I would suggest to move to markdown (and then convert to PDF if needed). Or use documentation system like readthedocs / sphinx.

Also there's no CONTRIBUTING.md in source tree.

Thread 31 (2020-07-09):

Documentation: User Manual EN 2.1.0: page 20, potentiometer, rotary encoder, etc.

zas, 2020-07-09:
Those sections describe external devices that can be connected.

Examples should be in the same section as the connector description.

zas, 2020-07-09:
Same goes for Power Supply connection, it should be made clear which kind of power supply is expected (7V, single output + expected power)

dspverden, 2020-07-09:
Ahm, both requests are already done in user manual 2.1.0. Even with links to successful used modules.

zas, 2020-07-09:
> Ahm, both requests are already done in user manual 2.1.0. Even with links to successful used modules.

Yes, I based my intial comment on previous doc, then saw you added them, so I modified it, perhaps you read initial version before modification.

Currently, we have a description of each connector, then a section with examples, I think about following structure:

- device1 (e.g. potentiometer)
  - connector description
  - compatible device description
  - examples of devices known to work
- device2 (e.g rotary encoder)
  - etc.

mike811, 2020-07-17:
Hi,
Page 19 of current German 2.1.0 manual: "Wenn Du ein I2C-Display anschließen möchtest, schließe es bitte ebenfalls an diese Stiftleiste an."
Users may connect their display to Vin (7-12V) according to this.

dspverden, 2020-10-03:
Fixed the typo on page 19: 89b92949f60f382ca76765154c1b1950259f8080

Closed 2020-10-03.

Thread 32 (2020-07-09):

Documentation: User Manual EN 2.1.0: page 41, make clear 3.3V refers to logic levels

zas, 2020-07-09:
Many USB2Serial devices provide 5V and 3.3V, but still only have 5V TTL logic levels (this is misleading), so make it clear Aurora requires 3.3V logic levels (power is'nt connected anyway)

dspverden, 2020-07-12:
Fixed here: 2fdda929ab346bdfab28eb38788bc423972b683e

Closed 2020-07-12.

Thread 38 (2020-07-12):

Addon B board B has schematics as PDF, board A has none

zas, 2020-07-12:
https://github.com/freeDSP/freeDSP-aurora/tree/develop/ADDONS/AddOnB/KICAD/Board%20A
https://github.com/freeDSP/freeDSP-aurora/blob/develop/ADDONS/AddOnB/KICAD/Board%20B/AddOnB-B.pdf

zas, 2020-07-13:
File was removed by https://github.com/freeDSP/freeDSP-aurora/commit/62fd40cd7139a54ca8f13c47d5be9e3a5f3ebbf2
Was it intentional?

cleener, 2021-01-17:
[AddOnB-A.pdf](https://github.com/freeDSP/freeDSP-aurora/files/5826653/AddOnB-A.pdf)

dspverden, 2021-01-18:
Updated schematic PDFs here: 70e72e3

Closed 2021-01-18.

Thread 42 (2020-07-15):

Addons A & B switches aren't listed in addon features

zas, 2020-07-15:
https://auverdion.de/produkt/addon-a-the-woodworkers-friend/ description doesn't list switches
https://auverdion.de/produkt/addon-b-down-with-developers/ doesn't either (micro switches)

Closed 2021-01-20.

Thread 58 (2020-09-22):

rk.lib and rkdev.lib are missing from the KiCad project files

wolfield, 2020-09-22:
Since most of the symbols and footprints used in the project are custom made and not from the standard KiCad library, absence of the mentioned library files renders the whole KiCad project very hard to use and almost impossible to work on.

dspverden, 2020-09-27:
The kicad project comes with a cache.lib that holds all the symbols needed for the project. Used that in stead of rk.lib and rkdev.lib

Closed 2020-09-27.

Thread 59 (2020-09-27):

Source code for XMOS controller is missing

wolfield, 2020-09-27:
Source code for XMOS controller software is almost completely missing. Files that are provided are not enough to build the working firmware for XE216-512-TQ128 and there is no instructions in the case if the firmware should be obtained from the third party.

dspverden, 2020-09-27:
Hi,

instructions for where to get and how to setup the third party frameworks are given in the getting started document in the documentation folder.

Closed 2020-09-27.

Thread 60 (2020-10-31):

4FIR Plugin Impulse Response

MarsianCRaute, 2020-10-31:
It is unclear whether a impulse response is already loaded or not.
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
Switching presets is slow/laggy. IF possible optimize fetching data into DSP or at least note hardware limits (20000 taps all presets combined) in the manual.

dspverden, 2020-11-04:
Just one comment first to avoid confusion: 20000taps is the limit for all filters per preset combined. Thus, each preset can have 20000 taps shared by 1,2,3,4,5... filters. For 4FIRs there are 4 filters with 4096 taps each. When switching a preset all 4 filters have to be updated by the ESP32 ( = 4x 4096 taps). Doing it this way, you can have 4 different sets of filters per preset.

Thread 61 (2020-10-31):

Manual: rotate pictures for analog in and output

Finnitio, 2020-10-31:
The schematics and pictures of the connectors have different orientation which is confusing. Page 17.

dspverden, 2021-01-03:
Fixed: 2b2743c

Closed 2021-01-03.

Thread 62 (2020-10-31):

4FIR Plugin: No confirmation of switching between Presets

Finnitio, 2020-10-31:
When swichting between presets the Interface stays like this:
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
After refreshing the browser it shows the newly loaded plugin.

dspverden, 2020-11-01:
Fixed. 10d50f0

Closed 2020-11-01.

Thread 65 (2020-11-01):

Phantom power 42V available?

audioprog, 2020-11-01:
Is phantom power 42V for condenser microphone available?

dspverden, 2020-11-01:
I am sorry, no, there eis no 42V phantom power available on the board.

Closed 2020-11-01.

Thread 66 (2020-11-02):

4FIR Plugin Bypass Filter

MarsianCRaute, 2020-11-02:
"Updating..." message stays till refresh/pressing F5 after bypassing a FIR Filter. Impulse response data is removed after reseting bypass. Maybe linked to #60 ?

dspverden, 2020-11-04:
Should be fixed by 23c243a
Plz update firmware and reinstall plugin for testing

MarsianCRaute, 2020-11-07:
Will test asap. Hopefully tomorrow.

Finnitio, 2020-11-09:
I tested it and it works to bypass and reenable the fir filter.

MarsianCRaute, 2020-11-09:
Confirmed.

Closed 2020-11-09.

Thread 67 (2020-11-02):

4FIR Plugin Input Selection visual reset to Analog1

MarsianCRaute, 2020-11-02:
Input selection is stored, but after reopening browser (FF, cookies cleared) it displays Analog1 for all channels. All selection are still correct, but not displayed correctly.
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

dspverden, 2020-11-02:
Can you show me the version numbers at the right bottom?

MarsianCRaute, 2020-11-02:
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
Should be 10d50f0 ...

dspverden, 2020-11-02:
Did you recompile the firmware from the develop branch? Seems that your FW is outdated.

MarsianCRaute, 2020-11-02:
I'm a simple man - I download things, upload things and complain when stuff isn't working.
What needs to be recompiled? I thought using the WebApp folder from develop is enough.

dspverden, 2020-11-02:
recompile aurora.ino

MarsianCRaute, 2020-11-02:
ESPAsyncWebServer.h: No such file or directory
ufff

dspverden, 2020-11-02:
You did read the build instructions? Anyway, I have just compiled it for you.
[aurora.ino.esp32.bin.zip](https://github.com/freeDSP/freeDSP-aurora/files/5476699/aurora.ino.esp32.bin.zip)

MarsianCRaute, 2020-11-02:
Pls forgive a n00b...
Case closed.

Closed 2020-11-02.

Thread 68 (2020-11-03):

Manual Page 27 Display Connection VDD via X501

Finnitio, 2020-11-03:
The manual describes when using Addon B it would be possible to connect the display via X501 PIN2, that is in the schematics described with 12 V.

dspverden, 2020-11-03:
This was already fixed in some earlier commits before 10d50f0

Finnitio, 2020-11-03:
cool, will check the develope branch next time.

Closed 2020-11-03.

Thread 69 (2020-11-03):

Wrong pin specification in the manual

dannyAux, 2020-11-03:
On page 27 of the German manual (and also in the English version) you can read that you can also tap pin x501 for the display. This damages the display, because 12V are applied there.

Closed 2020-11-03.

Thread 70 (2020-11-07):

[Develop] 4FIR Plugin, Switching presets does not change inputs.

Finnitio, 2020-11-07:
I mainly use preset A and B to switch between digital or manual inputs unfortunately it does not change the inputs. Not sure what else might not be changing.

MarsianCRaute, 2020-11-07:
Version?  I have not compiled fix #66 yet, but previus build works nicely.

Finnitio, 2020-11-07:
Latest develop build

dspverden, 2020-11-07:
Did you recompile?

Finnitio, 2020-11-07:
why should I? I use the \freeDSP-aurora-develop/SOURCES/WEBAPP/ESP32/aurora.ino.esp32.bin and \freeDSP-aurora-develop\SOURCES\WEBAPP\plugins\4FIRs for testing.

MarsianCRaute, 2020-11-07:
Please take a look at #67 and learn from my mistakes.
https://github.com/freeDSP/freeDSP-aurora/blob/master/SOURCES/WEBAPP/ESP32/README.md

I guess we need compiled stuff - we are new to this stuff. Of course we should learn how to recompile code and understand why it needs to be done.

Finnitio, 2020-11-08:
alright, expected the develop to be precompiled beacause a) there are precompiled files b) the master is precompiled. Will compile that later, if I have everything set up for programming. @dspverden which IDE do you use for coding?

dspverden, 2020-11-09:
I am using VScode fro coding and Arduino IDE for compiling. Both on macOS.
The Arduino IDE does not export the latest binary to project folder by default. You have to do that manually. And you know, I am a stupid man. I usually forget it, because on GitHub we have the releases for binaries and pulling develop is for getting the source code.
Btw. I have now compiled everything so far into a pre-release, perhaps that helps you.

Finnitio, 2020-11-09:
couldn't find the prerelease to be honest. But if I am right if I compile with Arduino IDE an Export the binary I can upload that via webota?

MarsianCRaute, 2020-11-09:
https://github.com/freeDSP/freeDSP-aurora/releases/tag/v2.1.3-alpha.1
Jep, that should work too.

Finnitio, 2020-11-09:
Alrigt, didn't know there was a difference between branches and releases. Probably beacaus some use branches like relases. Anywas  I compiled it myself and uploaded it via webota. Since my aurora is now daily used in the living room the usb2serial adapter is inconvenient. So the volume gets updated when restarting as do the inputs when changing presets. Thank you. I will be available for testing if needed and will try to implement some features myself.

Closed 2020-11-09.

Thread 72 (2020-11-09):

4FIR Plugin, 2.1.3-alpha.1: Preset switching broken

MarsianCRaute, 2020-11-09:
As written in title, switching preset with latest FW takes forever (5 min+, nothing happens). The "Switching Preset" message stays, after refreshing connection is lost. Reboot is required.
Preset import works, takes about 20 sec.

dspverden, 2020-11-09:
Can you open the web console in Firefox and have a look wether there are any error messages?

MarsianCRaute, 2020-11-09:
`TypeError: NetworkError when attempting to fetch resource.`
Is displayed after 20sec.

dspverden, 2020-11-09:
Ah, seems to be an issue with a timeout on your network or something like this.

MarsianCRaute, 2020-11-09:
Mhm, strange. Router reboot did not help. Reuploading plugin via /fallback seems to fix it.
I guess you will get used to this constant flow of non-issues. But I really tested a lot before reporting ;)

Closed 2020-11-09.

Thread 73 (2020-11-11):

Apple Remote IR commands

MikaRau, 2020-11-11:
It seems that Apple's commands depend where you live? Atleast here in Finland default arduino code didn't work.
Here are commands after sniffing them for finnish(?) users:
Up:	 77E150F7
Down:	77E130F7
Left:	77E190F7
Right:	77E160F7
Middle:	77E1A0F7
Menu:	77E1C0F7
Play:	77E1FAF7

zas, 2021-12-02:
It should be solved by https://github.com/freeDSP/freeDSP-aurora/pull/97
Is it possible for you to test and confirm?

MikaRau, 2021-12-03:
> It should be solved by #97 Is it possible for you to test and confirm?

I will test it once I get my amp/dsp combo back up and running (couple of weeks till I get my parts). Your solution seems really interesting.

dspverden, 2021-12-13:
For Apple remotes it should be fixed by this commit: 67fe23e

Closed 2021-12-13.

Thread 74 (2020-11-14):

Persisting phase correction bypass [2.1.3. alpha 1]

OldKamuffel, 2020-11-14:
Activating the bypass on the phase correction will not be saved on 'Store Preset'.
After switching to another preset and back the bypass configuration is lost.
Also after export and reimport a preset.
Other values (hz and Q) are saved correctly.

Saw on:
Fw 2.1.3 (alpha 1)
Gui: 2.1.3
Plugin: 8 Channel and 7.1
Addon: Balanced Live
Windows, Chrome Browser

dspverden, 2020-11-21:
Fixed by 9410e82

Closed 2020-11-21.

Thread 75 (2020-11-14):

Plop on changing SPDIF-Output

OldKamuffel, 2020-11-14:
Cascading 2 DSPs via SPDIF:
Changing SPDIF-Output from or to 'SPDIF IN' results in a 'plop' on the target DSP.

Changing between other output types seems ok.

Saw on:
Fw 2.1.3 (alpha 1)
Gui: 2.1.3
Plugin: 8 Channel(Target) and 7.1(Source)
Addon: Balanced Live
Windows, Chrome Browser

dspverden, 2020-11-21:
Please can you describe it a bit more? What I read is, that you change the source for SPDIF output on board 1 and once you select SPDIF-IN as source, the second board plops? Right?

OldKamuffel, 2020-11-21:
Yes, I have first a 7.1 DSP and a second front speaker DSP connected via optical SPDIF.
When all is running, for example set 'output 1 and 2' as source for SPDIF out on first board and than changing the source of SPDIF out to SPDIF it plops.

In German:
Ich hab die Kette USB => 7.1 DSP => SPDIF für die beiden Front Kanäle => 8 Channel SPDIF.
Alles läuft, im vorderen DSP ist SPDIF out auf 'Output 1 & 2' gestellt, im hinteren DSP die 8 Eingänge abwechselnd 'SPDIF 1', 'SPDIF 2'. Stelle ich nun am vorderen DSP den 'SPDIF out' Source auf 'SPDIF IN' Ploppt es. Beim zurück stellen auf 'Output 1 & 2' ebenfalls. Das ist mir versehentlich passiert, als ich als 'SPDIF OUT' Source USB 1&2 nutzen wollte. Der 'SPDIF IN' ist bei mir nicht belegt. Umschalten zwischen USB, Analog und Output als SPDIF Source macht bei mir keine Probleme.

dspverden, 2020-11-21:
According to your last two sentences I assume the plop is caused by the open SPDIF in on board 1. Thus, the SPIF receiver cannot lock on an incoming signal. Can you you check, if the plop is gone when you feed in an SPDIF signal? If so, we need a way to check that users cannot select an open SPDIF input as source.

OldKamuffel, 2020-11-22:
Ok,
using 2.1.3-alpha2 now, same base behaviour.
After applying a signal on the optical SPDIF input, the plop is not reproduceable anymore.
Even if I disconnect the optical wire the plop is not reproduceable until I reboot the DSP.

dspverden, 2021-01-03:
What do you mean with "until I reboot the DSP"? Do you still have plops with your setup?

OldKamuffel, 2021-01-06:
Mal auf Deutsch um Missverständnisse zu vermeiden:

Ich habe die aktuelle FW "2.1.3 Combined Bugfixes" aufgespielt.

1. Der DSP wird eingeschaltet
2. Es liegt kein SPDIF Signal an
3. Beim Umschalten des SPDIF Ausganges von oder zu einem SPDIF Eingang gibt es einen Plopp
4. Ein SPDIF Kabel (optisch) mit Signal wird eingesteckt
5. Kein Ploppen mehr beim Umschalten
6. Das SPDIF Kabel wird wieder entfernt
7. Immer noch kein Ploppen beim Umschalten
8. Der DSP wird ein und wieder ausgeschaltet. >> "until I reboot the DSP"
9. Das Ploppen beim Umschalten ist wieder vorhanden.

Wenn es bei der Analyse hilft kann ich versuchen das Plopp Geräusch aufzunehmen.

dspverden, 2021-01-06:
OK, dann ist das Problem, dass die PLL im SPDIF-Receiver des DSPs sich noch nicht einrasten konnte, weil kein Signal anliegt.  Ich studiere mal die Register des DSPs, ob das irgendwie testbar z.B. mit weil ein Bit nicht gesetzt ist und daher abfangbar ist.

Ok, the problem seems to be that the PLL of the internal SPDIF-Receiver of the DSP could not lock because there is no signal present. I will study the register description of the DSP wether this situation can be identified by a bit setting and can be avoided.

volpx, 2023-01-18:
Just looking at the schematic I can see that SPDIF IN and OUT (thus RX/TX) are swapped.

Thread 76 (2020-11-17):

Suggestion: move crossover to the beginning of the signal processing chain in HomeCinema71 plugin

cborss, 2020-11-17:
According to the documentation, the crossover / bass management summation is located after the parametric filters in the HomeCinema71 plugin. I suggest to move this block to the very beginning of the signal processing chain.

This plugin is well suited for implementing the bass management and room / loudspeaker equalization of a typical A/V receiver. In this use case, the parametric filters are used to calibrate the HiFi system according to the loudpeaker characteristics and their interaction with the room (wall/floor/ceiling reflections and room modes). If the bass management block is placed after the parametric filters, then these filters no longer only affect the loudspeaker that shall be equalized but also the subwoofer. Consequently, the loudspeakers cannot be equalized independently. And even worse, the signals that are mixed together with the LFE into the subwoofer channel have no longer the same phase relation as the original mix.

deadsnare, 2024-06-09:
I also noticed that oversight since I have the exact same usecase. I have managed to create two plugins, one for 7.1 and one for 5.3 systems, which put the crossovers at before the satellite and sub PEQs. The plugins also allow for separate House Curve EQ and LFE gain management (in case your equipment does not add the required 10 dB gain). Have a look at https://github.com/deadsnare/freeDSP-aurora-bass-managed-surround. The readme needs some work, but the plugins are fully functional.

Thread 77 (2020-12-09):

AKM Alternative

octave, 2020-12-09:
Hi guys,

With the recent news regarding the disastrous fire at AKM factory in Japan, it's currently impossible to source their converter and they encourage seeking alternative suppliers at the moment.

I was wondering if some of ESS converters could be use as an alternative?

Thank you!

octave, 2020-12-16:
Found this TI ADC too: https://www.ti.com/product/TLV320ADC6140#product-details

dspverden, 2021-01-03:
I am aware of this issue. Currently after two month it seems still unclear wether AKM ADCs/DACs of Aurora will be back in production soon. Thus, I will wait a little bit longer before making a decision. Redesign with ESS might be a good option, but redesign will take a lot of time and the ESS chips are more expensive then the AKMs.

octave, 2021-01-06:
Good to know you are aware of it! All the recent news are not very optimistic. Some say about a year before we can see them back in stock...

JayShoe, 2021-01-07:
Wouldn't a great alternative be to just have an Aurora Lite with no DAC or ADC? Just buffer a few FreeDSP headers and have a tightly integrated sub-module with converters.

Zadagu, 2021-01-08:
> Wouldn't a great alternative be to just have an Aurora Lite with no DAC or ADC? Just buffer a few FreeDSP headers and have a tightly integrated sub-module with converters.

I think this is a great idea. It would even allow to build a microphone preamplifier module for the Auroa.

JayShoe, 2021-01-08:
> > Wouldn't a great alternative be to just have an Aurora Lite with no DAC or ADC? Just buffer a few FreeDSP headers and have a tightly integrated sub-module with converters.
>
> I think this is a great idea. It would even allow to build a microphone preamplifier module for the Auroa.

You can build a mic preamp module for the Aurora now... Not only are the I/O's pin headers (analog), there is also one FreeDSP connector (digital).

May I also suggest exposing some buffered SPI busses? If designed thoughtfully, one can envision a sub-module that attaches directly to right angle FreeDSP headers allowing the updated system to be the same size as it is now. Parallel FreeDSP + SPI headers would allow for pretty much any expansion module one can think of.

dspverden, 2021-01-14:
Hm, I don't like the idea of an Aurora Lite. This would require programming skills to adapt for different DACs and ADCs. But from my experiences so far there are not so many Aurora users how have these skills. Thus, it would only be useful for a very small group...

dspverden, 2021-01-14:
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

SPI? There is now SPI-bus on Aurora. And I don't see any free pin of the ESP32 to implement a SPI-bus.

kpek, 2021-09-28:
Hi, just wanted to follow up on this, any decision taken yet on probably replacing the AKM chips ? the prices are over the roof everywhere you look (~100$ per chip).
It doesnt look like the production will resume any time soon (if ever) + not even trying to guess when will the retailers actually have the chips in stock so us mortals can buy them, since iam pretty sure theres huge backlog of orders already reserved for big players.
Thanks

MIcQo, 2022-01-02:
Hi, any update of this?

I want to build one, but this "unavailability" of AKM chips blocks me. I'm very unhappy from this situation.
i'm trying to find those chips few days but without success.

Thanks for answers.

JayShoe, 2022-01-11:
> Hm, I don't like the idea of an Aurora Lite. This would require programming skills to adapt for different DACs and ADCs. But from my experiences so far there are not so many Aurora users who have these skills. Thus, it would only be useful for a very small group...

Yes but then again when chips are no longer available, you aren't stuck redesigning the entire Aurora... Sure, have a "standard expansion module" with whatever chips you support but making it two boards (mainboard + module) means that the mainboard is designed once. It also means other users can expand on the Aurora mainboard.

djkylian, 2022-10-10:
It seems AKM is back in business, They started shipping out the first in Januari 2022 as I can believe this article:
[https://audioxpress.com/news/akm-resumes-sample-shipments-of-13-velvet-sound-dac-adc-products](url)

JohanAR, 2023-06-25:
Looks like Digikey has both AK4458 and AK5558 in stock now, so everything's good again, right?

Anyone have any inside info regarding Auverdion resuming production of these? Would be nice if one could buy a board with at least the smd components pre-soldered.

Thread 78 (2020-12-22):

Display anzeige vom Plugin

kracer86, 2020-12-22:
Servus,
Seit 2.1.3 wird im Display oben links wo das Plugin stehen sollte "null" angezeigt.
Unter 2.1.2 stand da noch das Plugin als Name.
Oder ist das so gewollt?

Danke & Gruß

dspverden, 2021-01-19:
Fixed: b6d9766

Closed 2021-01-19.

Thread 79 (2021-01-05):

Power adapter causes boot loop.

gdimopoulos, 2021-01-05:
I bought [this](https://www.amazon.com/LEDMO-12V-Power-Supply-Transformers/dp/B06Y64QLBM) power adapter. It is rated 12V, 5A but when I connect it to Aurora it goes into a loop (power LED momentarily goes on and then off again).

I was using an old adapter with variable output 3-12V, 1A without a problem but I have to replace it because the connector is starting to fail.

Closed 2021-01-11.

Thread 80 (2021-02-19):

FIR > 4096 taps

dspverden, 2021-02-19:
Currently the web app does not support FIR filters with more then 4096 taps.
The function postJson() in aurora.js needs to be fixed for it.

dspverden, 2021-09-27:
Fixed by b95c9e9

Closed 2021-09-27.

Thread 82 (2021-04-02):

ADAT IO routing not available?

imbusschlussel, 2021-04-02:
ADAT IO does not seem to be an option in the web app.

Making this available would make the board far more usable for those with existing standard audio interfaces as ADAT over Toslink is a standard connection on there. Ideally with Input and Output routing options.

A common use set up would likely be to route the 8 ADC Analog Ins to the ADAT Out Port, and the ADAT In Port via the DSP to the 8 Analog Outs. This would be incredibly useful in a studio setting.

dspverden, 2021-04-07:
Currently you have to change it in the XMOS-Firmware by recompiling and uploading a new firmware to the XE-MCU. ADAT should replace then the USB channels. Feel free to build a channel multiplexer inside the XE to make mixed use of USB and ADAT

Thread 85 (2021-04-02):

Documentation

artpelling, 2021-04-02:
IMHO the documentation for this project in its current state is not very thorough. It covers the basics, but makes it tedious to dive deeper into it. A lot of the times it feels like "reinventing the wheel" when trying to understand and change the source code or make new breakout boards. It is frustrating to constantly run into problems that somebody else has surely already found a solution for.
A community driven documentation page, where knowledge can be pooled publicly would help with this issue. I suggest to use the Wiki page here on github for that reason.
This would significantly help community building, making the project more attractive in general an would also drastically improve the experience for new users.

The impression I get from the project so far is that there the devs are busy with maintenance and bugfixes for "consumer level" users and resources for higher level support and development of new features are lacking. There is a discord channel with a few users, other than that there is a lot of discussion on the diy-hifi-forum which is only in German, has a closed registration and the overall quality of communication seems very inefficient there.

Providing a central place for a thorough documentation of custom builds and features users have implemented would also benefit the maintainers of this repo as a lot of question could be already answered here. Personally, I would be happy to write small tutorials/howtos of the solutions I found for several issues I have encountered.

Related to #23

dspverden, 2021-04-07:
I like the wiki idea. I just enabled that feature, so nothing is there, yet, but feel free to add pages. I have made the wiki "public". Everyone with a GitHub account can contribute the wiki now.

Closed 2021-09-26.

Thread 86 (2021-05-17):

ESP32 WEPAPP an ANY ADAU1452 BOARD

buraked-com, 2021-05-17:
I can't find AK4458 and AK5558 in the market, I decided to use ADAU1966 in a circuit that I designed.
What features will not work in the ESP32 WEB APP if I do everything right?

dspverden, 2021-09-26:
I cannot tell you that, I did not study the ADAU1966. The only device specific feature in the web app is the ADC channel summation which is done inside the AKM chip. And you have to update the chip configuration in the ESP firmware.
But this is issue is not an issue of Aurora because you are developing your own hardware. Therefore, I close it now.

Closed 2021-09-26.

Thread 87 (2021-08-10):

Is this project dead?

xtc0r, 2021-08-10:
I' checking the shop website for months to see when new plugins are available...but nothing...
Also I do not see any new commits or comments on issues on github. So is this project dead?
Would be a shame after all the money I invested in the hardware and case.

dspverden, 2021-08-12:
Well one way to keep such a project alive would be, that you provide some plugins. ;-)

Besides that, I am currently busy with making a new version without the AKM converters after the fire disaster at their factory. But that takes a lot of time. It is basically a complete new hardware development. Therefore, I don't have much time for new software features atm.

xtc0r, 2021-08-12:
Mit plugins meinte ich die Add-ons wie z.B. das Add-on B: [https://auverdion.de/produkt/addon-b-down-with-developers/](url) Das bräuchte ich um aurora so zu nutzen wie ich es möchte oder ist der Plan eher, dass jeder die  HW dafür selbst zusammen bauen soll und nicht aus dem shop bezieht?

Ich habe auch gesehen, dass du Code bei zas' FreeDSP fork hinzufügst aber hier nicht. Wird dort das Projekt weiter entwickelt oder spielt mir github da einen Streich? Evtl. Sehe ich das auch falsch.

dspverden, 2021-08-12:
Nein, ich füge keinen Code beim fork von zas hinzu. Hauptrepository bleibt dieses.
Die AddOns wird es auch dann wieder geben, wenn es wieder Aurora's gibt.

Closed 2021-08-12.

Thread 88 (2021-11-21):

Double include of display.h

exislow, 2021-11-21:
I have noticed that this line is present twice:

`#include "display.h"`
https://github.com/freeDSP/freeDSP-aurora/blob/master/SOURCES/WEBAPP/ESP32/aurora/aurora.ino#L30
https://github.com/freeDSP/freeDSP-aurora/blob/master/SOURCES/WEBAPP/ESP32/aurora/aurora.ino#L33

What is the reason for that? Or is this just a suspect to refactoring?

dspverden, 2021-11-30:
Fixed: 049db8c4606b28c6274ccfad7ccbaad103a1ba79

Closed 2021-11-30.

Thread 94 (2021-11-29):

Doc update: IR receiver

exislow, 2021-11-29:
@dspverden I can confirm that this IR recevier diode works just fine: https://www.reichelt.de/de/de/ir-empfaenger-module-38khz-90-side-view-tsop-4838-p158403.html?r=1

Maybe you could update the docs accordingly and add this IR diode as a recommendation.

Closed 2022-03-13.

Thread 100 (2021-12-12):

v2.2.1: 4FIRs plugin web interface has oversized peq dialog

zas, 2021-12-12:
https://github.com/freeDSP/freeDSP-aurora/blob/0c6edf79fcab260e279281e42e99ac09a16ecc5e/SOURCES/WEBAPP/js/aurora.js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 causes the width to be set to a fixed width 2000px (whatever is the window width).

Here how it looks on my screen (see PEQ 10):

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

It's even worse with reduced browser window, especially since there's no mean to scroll horizontally:

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

----

Instead, setting width to 95% results in much nicer output:

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

Closed 2021-12-13.

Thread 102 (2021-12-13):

v2.2.1: 4FIRs + display: presets are incorrectly displayed

zas, 2021-12-13:
The issue was introduced by https://github.com/freeDSP/freeDSP-aurora/commit/dd2ac3b2a3ca8c657b8e869bfa71a93c1e78027e

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

Issue appeared with preset as string, when it was a letter before, related code: https://github.com/freeDSP/freeDSP-aurora/blob/681eaee9fcaf23816395fc31fa001ef69c9ea5c2/SOURCES/WEBAPP/ESP32/aurora/OLED128x64_SH1106.cpp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

dspverden, 2022-01-22:
Fixed by 853c33e

Closed 2022-01-22.

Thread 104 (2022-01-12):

No spotify or plex music over USB audio on windows 10

gdimopoulos, 2022-01-12:
I recently setup a new windows 10 PC and I tried to use Aurora with USB audio. All windows sounds play fine and I can stream audio from my browser (YouTube, Spotfiy, etc.).

But when I try to play music from my Spotify desktop app it fails with an error ("Spotify can't play this right now"). I have the same problem when playing music with Plex.

In the device manager I can see the aurora-dsp devices recognized correctly but I also see an "auverdion DFU" device that is not recognized.

dspverden, 2022-01-13:
This is an issue of Spotify or of the UAC2 driver that comes with windows 10 because as you said playing via your browser does work. Aurora does not come with its own driver, it uses the driver from Microsoft. Therefore, nothing we can do (except somebody is willing to invest time for writing a driver for Aurora).

The auverdion DFU is related to firmware update of the XMOS chip. Windows does not support this while macOS an Linux do. Therefore, this is not related to audio playing.

Conclusion: This issue is not related to this project and therefore, I am closing it.

gdimopoulos, 2022-01-13:
From the documentation and the description of the project:
> Works with ASIO driver under Windows 10.
This means that this _is_ related to the project since you claim that Aurora works fine with the ASIO driver. If you have no plan of supporting windows users and fixing the related issues, you should remove this claim from the documentation and description.

gdimopoulos, 2022-01-13:
The list of multimedia apps that don't play audio with Aurora is not limited to Spotify. As I mentioned, the same applies to Plex and VLC when playing video with specific audio formats. And these are just the ones I tried. This implies that the issue is not with a specific app or player but with how Aurora receives and decodes the audio stream from these players.

I know first hand that there are devices that are capable of working with any player or content over USB without the need of special drivers. I don't know why Aurora can't do this but I know it is feasible.

dspverden, 2022-01-13:
I know what you mean, but again this is an issue for the Windows UAC2 driver and therefore, out of the scope.
It is proven that Aurora works class compliant and the apps you mention do play with Aurora on macOS which comes with a class compliant driver, too.
As I said there is no direct audio stream from those apps to Aurora. It all goes via the UAC2 driver that receives the stream from the app (perhaps decodes it) and then sends it in UAC2 format to Aurora. The fact that Aurora works with e.g. YouTube proofs that it can receive audio from the UAC2 driver and that the broken link is between the Windows UAC2 driver and Spotify etc. and therefore we have no influence on it.
As I said the way to circumvent it is:
a) Go via ASIO if your app supports it.
b) Write a new driver to replace the Microsoft driver (that is probably the reason, why other devices work).

And hey, this is open source here, make a fork and fix it if you think it should be fixed.

gdimopoulos, 2022-01-13:
Thanks for the detailed explanation. It does make more sense to me now.

Closed 2022-01-13.

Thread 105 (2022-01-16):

DSP memory holds FIR coefficients in reverse order

mike811, 2022-01-16:
Hello,

tests reveal a maximum phase behaviour of current FIR implementation.
This seems to be caused by incorrect order of coefficient upload. According to this:
https://wiki.analog.com/resources/tools-software/sigmastudio/toolbox/filters/firfilter
Coefficents need to be loaded in reverse order.

As a quick workaround coefficients may be swapped prior upload by a script or via command line e.g:
tail -r LIN.txt > LIN_rev.txt

dspverden, 2022-03-15:
HI,

please can you verify wether the issue is solved in v2.2.2? I have added the coefficient order reversing to the ESP32 firmware.

mike811, 2022-03-15:
Hello,

seems to work correctly in principle with pre 2.2.2 but there is a difference in frequency response:
For example with 2.1.4 and manual coef reversal:
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

With pre 2.2.2 and without manual coef reversal:
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

Did something regarding PEQ change to cause this?

Regards
Michael

dspverden, 2022-03-15:
Are there PEQs involved in your setting?
Or do I see the FIR only there?
I did test it with only FIR active and directly from audio interface back into audio interface and saw the expected FIR response.

dspverden, 2022-03-15:
P.S. between 100 and 200 Hz I see a phase change, too. Can it be that you have enabled another filter (PEQ or Phase)?

mike811, 2022-03-15:
No Aurora PEQ were involved. All 10 PEQs had Gain 0. Tested with clean 2.2.1 and pre 2.2.2 FW. Only FIR-inside EQs generated via rePhase.
Didn't you mention something about extending PEQs to 10 in FIRs plugin?

dspverden, 2022-03-15:
Is there a way to show how the FIR should look like? So what did you design and does Aurora reproduce that correctly.
Or send me your filter and I can verify here.
Regarding PEQs: Yes the GUI was telling 10 PEQs but SigmaStudio has set it to 8 when copying the block from 8channels to 4FIRs.

mike811, 2022-03-15:
Yes, the first picture with 2.1.4 shows my Woofer with linear phase close to zero. This was only tuned by rePhase EQs and should look like that ;-)

dspverden, 2022-03-15:
ok, plz can you send me the text file you uploaded to aurora? I want to make sure that this is processed correctly.

mike811, 2022-03-15:
You got mail.

dspverden, 2022-03-15:
Yes saw it while I was typing here? Can I conclude from your previous post, that this issue is solved now?
Will have a look at your file anyway. Just to be sure with some files from outside of my lab.
Thanks for helping with debugging it.

MarsianCRaute, 2022-03-15:
Great! Can't wait to use FIR more often now

mike811, 2022-03-17:
Hello,
it seems there is still something going on with the FIR or EQ implementation.
After power up today I got this response measured:
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

Only after reloading the coef file again I got the nice response from two days ago...

dspverden, 2022-03-17:
I will verify this today evening.

dspverden, 2022-03-17:
Hm, I cannot reproduce that here. Could it be that you did not press "Store Preset"?
Because in the IR file you have sent me, I see that you equalize the dip at 100. So the first picture looks a bit like no filter present at all. Btw. the file you have sent me does not fully match your result because I cannot see the LP behaviour in your measurement.
This is the file you have sent me:
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
And this is what I measure after a reboot:
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

mike811, 2022-03-18:
Hi,
sorry for the confusion. I can't reproduce it here ether. You are probably right. Maybe I simply forgot to klick store preset when playing around last time...

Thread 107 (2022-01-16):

v2.2.1 PEQs ignored after power off

pillepalle1234, 2022-01-16:
After installing Firmware v2.2.1 my DSPs ignore my PEQs after disconnecting the power. Strangely this does not occur after every power disconnect, i checked the serial monitor during testing and the problem seemed to have disappeared.
1 day after i reinstalled the DSPs into the case again this issue reappears. Once it is there, the problem persists after consecutive power offs.
The values still show up in the gui but are ignored until I bypass and enable them once again.
This is independant of the used plugin, i have one DSP with the 7.1 and one with the 8 channel plugin.
Shelf-Filters and master volume still seem to work as expected.
I did not import a preset and tried reinstalling firmware/plugin several times.

Here is the log file:
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

dspverden, 2022-01-28:
I think I found the reason for this behaviour. Fixing it now.

Closed 2022-03-12.

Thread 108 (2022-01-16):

v2.2.1 DSP creates 2 Acess Points

pillepalle1234, 2022-01-16:
One of my DSPs creates 2 Acess Points. Reinstalling the firmware and plugin did not solve this. It is not critical like my other issue with ignored PEQs but it is there...
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

dspverden, 2022-01-16:
Please, can you check wether other devices show the two access points, too? E.g. what does your phone see?

pillepalle1234, 2022-01-16:
Thanks for your answer!

The other DSP does not, but appearently your tip with using the phone is golden.
It only shows 1 access point.
So it seems to be a problem with the wifi config of my computer...

dspverden, 2022-01-22:
Ok, great. Then I will close this, because it seems not related to Aurora DSP.

Closed 2022-01-22.

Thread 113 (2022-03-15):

JLCPCB package library

zgchen83, 2022-03-15:
Can it match the package library of JLCPCB?

dspverden, 2022-03-15:
I don't know what you mean exactly. The design was done in KiCAD. Therefore, I think, it will have trouble with importing it into easyEDA of JLC, if that is, what you mean.

zgchen83, 2022-03-15:
Yes, the component package jlc can not be recognized friendly

dspverden, 2022-03-15:
Feel free to make a fork and replace the component library with the ilc stuff. But be warned, you probably have to remake the whole layout. This is  really a new project then. Therefore, I close this issue now.

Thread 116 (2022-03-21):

stereoforever and The Room code artifacts

exislow, 2022-03-21:
hey @dspverden,

still a great job you are doing here. I have noticed that in the last commits code artifacts appeared, where you check against strings `stereoforever` and `The Room` to alter the behavior of the aurora board, for instance, see:

https://github.com/freeDSP/freeDSP-aurora/blob/5142f7cd48acabf1c630bbd7f1dddd0ec1198aa7/SOURCES/WEBAPP/ESP32/aurora/aurora.ino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

Is it possible, that this code handles only your private plugins? Have you committed it by accident?

dspverden, 2022-03-21:
No, the reason is a little bit different:
The plugin stereoforever will be released soon, it is in the final testing now, therefore, I decided to leave these checks in. Thus, I don't need a new release for the firmware for it.
The plugin "The Room" is a custom plugin that I made. In order to keep the firmware compatible I left the check there.
Regarding The Room please refer to www.hornsolutions.de and request the source codes there. The product is based on Aurora and falls under the license requirements of the CC license used by Aurora.

exislow, 2022-03-22:
Thank you very much for the fast clarification. I am excited about upcomming plugin.

Closed 2022-03-22.

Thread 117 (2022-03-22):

Proper code style: Refactoring

exislow, 2022-03-22:
Dear @dspverden,

I would like to contribute more and more to this project, since I really like it and use my aurora daily. I already have some custom modifications to this code held in my GitHub repository fork.

What I really have noticed is that the code styling is somehow odd. I couldn't figure out, yet, to what code style / IDE settings you stick to. I would like to propose to stick to the Arduino code style guidelines:

* https://docs.arduino.cc/hacking/software/ArduinoStyleGuide
* https://blog.wokwi.com/how-to-write-clean-arduino-code/

If you agree, I could reformat the code of the `develop` branch and send you a pull request. What do you think?

This will make the code very readable and better maintanable compared to the current code style in my opinion (also other Arduino projects have shown sticking to a proper code style increases the coding efficiency).

dspverden, 2022-03-27:
Sounds good.
I would like to merge PR #97 first, if that is ok for you?
I also would like to talk about the style guideline first, because Arduino defines sometimes different styles for the same code.

exislow, 2022-04-02:
Sure, this is totally fine. Just tell me, as soon as the PR #97 is merged.

Of course, we can discuss the style guidelines first. Have you already had a look at the JetBrains CLion code style formatter? It sticks to what Arduino code style guidelines are recommending and also to a general propper C style. Tell me what you think about it.

dspverden, 2022-04-19:
I have merged PR #97 now.
I am now looking into style guide and what would be the best way to define it. Any idea? Something like a .md file, perhaps?

exislow, 2022-05-07:
An *.md sounds reasonable. You could also create a Wiki page here and refer to it. But I guess this is not a big deal at all.

Finding and committing to a proper style guide is the bigger task. Did you have a chance to check, e.g. the code formatter of CLion?

After PR #97 is already merged, I could also just send you a new pull request with properly reformated code so you would have a better idea what I am talking about. What do you think?

exislow, 2022-06-06:
*ping

exislow, 2022-09-01:
@dspverden are we still on the same page about this idea?

dspverden, 2022-09-01:
Just send. a PR and I will have a look.
I never worked with CLion or something like that. Lately I came across the Boost-style and I am now using that in all of my newer projects. But I see that this would be a lot of work to change aurora to Boost-style.

exislow, 2022-09-02:
Okay, I will do so based on the latest develop branch. CLion is just an IDE which used an general state of the art code formatter, which is absed on any specific code style. I will just send you a PR in the next days. A lot of files will contain changes, but just formatting changes, no logic changes.

dspverden, 2022-09-02:
ok, looking forward to it.

exislow, 2022-09-11:
I have got you a the PR #124. Let me know what you think about it :-)

Closed 2023-10-17.

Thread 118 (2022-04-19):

4FIR plugin unstable preset switch

xrtze, 2022-04-19:
Upon switching between presets, the device oftentimes crashes. Display reads "switching presets" for ever / sometimes reboots automatically, sometimes won't even do that.

dspverden, 2022-04-19:
Your are using the latest version?
Is there any pattern to reproduce it?
Could be related to the file that you upload. Can you provide that?

xrtze, 2022-04-19:
It happens on FW2.2.2 as well as earlier ones. And also happens with any filter file. It appears to happen more, if switching fast between presets.
[example FIR filter](https://github.com/freeDSP/freeDSP-aurora/files/8515911/links.mp1.txt)

dspverden, 2022-04-28:
Ok, I am now going to have a look into this.

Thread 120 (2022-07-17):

7.1 Plugin: highpass instead of lowpass filter

pillepalle1234, 2022-07-17:
In the 7.1 plugin there is a lowpass instead of a highpass filter in the Subwoofer section.

While both filters might be useful, a highpass filter is needed in 99% of cases, even closed box subs profit from one 10hz and below when used for movies to limit unnecessary excursion.
Ported subs can´t be used without a highpass safely when listening at louder volumes.

Most consumer AV-receivers already apply a lowpass filter to the LFE and the rerouted low frequencies from speakers are lowpass filtered already.

I would like to make my own plugin but the script does not work for me, as i already mentioned in the diy-hifi-forum..

Thanks.

dspverden, 2022-10-07:
I have send you a modified plugin already weeks ago. Does it work now?

pillepalle1234, 2022-10-07:
Hi,
yes it works flawlessly, thank you :)

dspverden, 2022-10-07:
Great, would you mind to share it with other Aurora users? E.g. open a GitHub repository for it?

pillepalle1234, 2022-10-17:
Here it is: https://github.com/pillepalle1234/FreeDSP-Aurora-7.1-Homecinema-Plugin-Highpass

dspverden, 2022-10-23:
Excellent, thanks!

Closed 2022-10-23.

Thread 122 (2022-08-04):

User friendly web interfaces for plugins.

exislow, 2022-08-04:
The current web interfaces of the plugins are very basic and hard to handle. If you like to change, e.g. EQ settings you only have a simple input based interface. Why not make it interactive using some more javascript?

I would like to help and re-create the plugin webinterfaces in a more user friendly manner. There are already approaches to get output of several JS based frameworks on ESP32, for instance, https://github.com/ayushsharma82/ESP-DASH.

Is this something considerable? If yes, I would like to submit some PoCs.

exislow, 2022-09-01:
@dspverden any comment is appreciated.

dspverden, 2022-09-01:
I highly appreciate that. Although, I don't have the time to dive into the details of those frameworks atm. If you want to do something, just do it. The communication with the Aurora board is a simple REST API, data is transferred by JSON. It is easy to understand from the JavaScript I think.
But be aware, that memory space on the ESP is very limited. That is the reason, why I did not use a ready-to-run framework. Most of them are too big. And depending on DSP plugin you need some space for user data (e.g. 4FIRs plugin with 4 presets each with four 4096 taps Its for the FIR filters).

archi, 2022-09-02:
Re memory constraints: I am not a huge fan of cloud stuff, but maybe exposing just an API on the ESP (and maybe the basic UI?) and storing the static HTML/JS of the advanced UI somewhere else might be an option (at least for prototyping). E.g. I have a Linux NAS that's always-on, others have their RPi, etc. And if its just static code, it could even be stored on the users local filesystem.
The ESP just needs setting the apropriate [CORS headers](https://developer.mozilla.org/en-US/docs/Glossary/CORS) to allow external access.

For the general public, you could also put it on a GitHub-hosted github.io (and maybe offer to install it as a PWA so it works offline; do PWAs work offline?).

IIRC you (Raphael) are already using a filesystem lib, I suppose that's already compressing the content? Is the mentioned userdata also handled by it? If the FIR floats are stored as ASCII there could also be potential savings by storing them in a binary format.

exislow, 2022-09-02:
Memory limitation is the biggest problem here indeed. There are already some approaches getting popular JS frameworks running on a ESP32. Of course it will impossible to load your JS app with a lot of external packages and expect it to fit into the ESP memory. But a PoC is described here: https://www.pschatzmann.ch/home/2020/04/08/progressive-javascript-frameworks-with-microcontrollers-vue-js-on-esp32/

I will try to to port the 8channel plugin as an PoC and see how it goes. I will keep you updated.

@archi: This is a possible solution but creates even more complexity and dependencies. Not everybody has an NAS at home and also not everybody wants to expose its Aurora to the internet. Especially based on the experience with the majority of the users, who are using the Aurora it will be too confusing for them. I would prefer a standalone solution with all data providing by the local ESP.

dspverden, 2022-09-02:
Cloud solutions are not good, indeed. Many users run their Aurora offline via an ad-hoc connection. They don't have access to a cloud then.
In the beginning of Aurora I made a stand-alone app that runs locally on your machine. It communicated with Aurora via a REST API. The API API is somehow still the same. Yet, maintaining the native app was eating resources. Especially the Windows version was like hell. Simply too much for a one man show.

Regarding file system: All user settings (filter coeffs, eq settings etc.) are stored in a binary format on the internal NOR flash. The develop branch has already a commit that introduces a new feature: All html, js and css stuff can now be stored compress (.gz file) on the internal NOR flash.

archi, 2022-09-02:
Exposing wouldn't be necessary, and a bad idea overall; I totally agree with you there :)

But there are at least these two options I can quickly come up with:

1. Open the ESP's website on your LAN, as usual. But now there is just some minimal bootstrapper code, which loads the external resources (JS/HTML) from aurora-controller.github.io (could later be cached in the HTTP5 localStorage for offline use). For dev-work you'd need to point it to another source.
2. Go to aurora-controller.github.io, enter the IP of your aurora (stored in a cookie) and then the Webapp on there just calls to the REST API (since JS runs locally in the browser, there is actually no access from an internet-based host to the Aurora happening).

Of course putting everything on the Aurora is better, and if you're looking for someone to bash "cloud-native" and ask questions later: I'm your man ;) It was just an idea in case the better/proper solution should turn out to be absolutely, definitely and under any and all circumstances not realistically feasible.

dspverden, 2022-09-02:
The ESP only delivers. There is a new python script available that compresses all the GUI stuff needed for a DSP plugin. I just used gzip because you it is usually available on *nix machines and than I found a python lib for it.

exislow, 2022-11-02:
I have finally found some time to redo the frontend. Here is a sneak preview of a very early alpha stage. I am happy about comments.

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

Btw... How much space do we have left on the ESP32?

Also while refaactoring the frontend I have noticed that the backend API is not built according to best practices. But this is a whole another task and not for now...

MarsianCRaute, 2022-11-02:
I like the style of the current GUI. Dark, minimalistic and not too many buttons to click.
Line charts would be great though. REW filter import.... take my money!

exislow, 2022-11-03:
Progress is going well... Here is another sneak preview -- but animated this time! E.g. in my oponion a bypass sbould be activated with only one click, so I put it on the main page. I have so many ideas for backend refactoring but first things first!

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

Two big steps still to do for the frontend:
1. Add all the AJAX stuff.
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
exislow, 2022-11-05:
> The shape looks right, but the slope is too steep. Any 3rd order lowpass should be -18dB/octave. And your plot is showing -27dB per octave.

Under this assumption the output of my formula should actually be (if cut-off frequency is 200 Hz):

* 200 Hz == -3dB
* Next octave: 400 Hz == -21dB

but this is not the case. My plot show at
* 200 Hz == -0.92 dB
* 300 Hz == -4 dB

What is wrong...? I have fixed the x-axis scaling for better readability:

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

Furthermore thank you for the z-space function and the Wikipedia link. I am getting more and more in detail with this topic. Feels great!

Zadagu, 2022-11-05:
The newes one looks right. :+1:
1kHz: -20dB
2kHz: -38dB

exislow, 2022-11-05:
I do not get... Why is this correct? I thought a 3rd order lowpass has 18dB/octave. My cut-off frequency was is set to 200 Hz. Thus the result should be:

* 200 Hz == -3dB
* Next octave (double 200 Hz): 400 Hz == -21dB

Where is my calculation wrong? Or can you explain me how you calculated this values?

> 1kHz: -20dB
> 2kHz: -38dB

Zadagu, 2022-11-05:
Those filters doesn't reach their maximum steepness at the cutoff frequency. So you need to look at a point where the gradient doesn't change anymore.

> Where is my calculation wrong? Or can you explain me how you calculated this values?
>>1kHz: -20dB
2kHz: -38dB

I took those numbers out of your last diagram.

exislow, 2022-11-06:
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

I know that. I was more like: Can you explain me, why those numbers are correct, despite it is in my diagram. But anyway, I take like it is for now and try to implement the remaining features. Those algorithms can be changed easily later, if any mistake is still there.

Thank you very much (honestly!) for your support so far. I appreciate it a lot.

Zadagu, 2022-11-06:
> I know that. I was more like: Can you explain me, why those numbers are correct, despite it is in my diagram.

Have a look into the art of VA filter design.
Chapter 2.9 "Poles and Zeros" section "Rolloff".
https://www.native-instruments.com/fileadmin/ni_media/downloads/pdf/VAFilterDesign_2.1.0.pdf
It's a well written book and understandable even for me as a software developer without a degree in electrical engineering.

exislow, 2022-12-10:
Just to give you a small update: I'm still on it. Almost finished to re-implement the current functions in a more modern way. Soon all the advantages to ease up your life will be implemented, so I can release the first version of the new 8channel plugin.

fabguitar69690, 2023-04-28:
Hi ! existlow do you continue to develop the new interface ?

exislow, 2023-05-02:
Despite the fact that I was busy with something else in the meantime I am still developing this UI. You can see the progress in my personal repo (link posted somewhere up here). There is "only" the PEQ visualization part left to be done. I hope, I can release the UI for beta testing soon.

exislow, 2023-10-10:
Just a quick update here: I am currently working on a first usable beta of this plugin. But there are some issues to compile all the Svelte code into a single JS file. After this problem is solved I will offer the plugin for download for everybody who likes to test it.

The current code can be found here: https://github.com/exislow/freeDSP-Aurora-Svelte-Frontend/tree/biquad

exislow, 2023-10-18:
Finally, I am able to present the first running beta of my work:

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

This is the new web interface for the 8channel v2.2.2 plugin. You can get the beta here: [8channels_new_v2.2.2.zip](https://github.com/freeDSP/freeDSP-aurora/files/13032899/8channels_new_v2.2.2.zip)
As usual: Please backup your presets before you upload this plugin. Afterwards you need to upload your presets again. I recommend NOT to use Internet Explorer!

What are the advantages of this new web interface?

* It looks better, of course :-)
* It has some methods to import REW PEQ text export files, so you do not need to set all the parameter for each channel by hand. You can either upload the REW PEQ file for all channels at once or per channel.

Bugs:
* Maybe a lot!
* Values are reflected only after a page refresh (F5) at some points.
* The line chart view for your filters is not finally implemented, yet.

**If you like to submit bugs, ideas etc. please create an issue here:** https://github.com/exislow/freeDSP-Aurora-Svelte-Frontend/issues

I will not support any issues in this thread. Thank you for your understanding.

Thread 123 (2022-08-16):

Sound card controller / IC crashes if switched on for over 36 hours.

exislow, 2022-08-16:
I am running the latest v2.2.2 firmware on the v1 aurora hardware. My Raspberry Pi 3b is attached via USB to the aurora DSP board and uses it as a soundcard to stream music to it.

Everytime the aurora is running for 36 - 48 hours or more my Raspberry Pi is not able to stream audio anymore to the aurora using it as a soundcard. I assume the IC, which is providing the sound card functionility crashes or something. Also a reboot of the Raspberry Pi does not help. Only if I switch the aurora off and on again my Raspberry Pi is able to stream music.

Is this an already known problem? Does anybody has a better solution than rebooting the aurora everytime this happens?

My Raspberry Pi is currently running this distro: https://www.picoreplayer.org/
It is like any other music player distro: It simply runs a squeezelite instance to handle music input and using alsa to output / stream the audio.

exislow, 2022-09-01:
@dspverden any comment is appreciated.

dspverden, 2022-09-01:
oh sorry, I thought I had replied already. Maybe on another forum?
Anyway, there are too many degrees of freedom. I would do this:
Take the aurora board and connect the UAC2 input to a PC and play some music. Then let it run for 48 hours. If that succeeds, you know, that the problem is the USB stack of the RaspPi, if it fails you know that the XMOS framework has a problem.

exislow, 2022-09-05:
I have not stated this issue somewhere else. Maybe you are confusing me with someone else. But also maybe this shows, that this issue is real.

Thank you for your advice. So I did somethink similar, since I had issues moving my aurora as it is kind of burried in my hifi tower.

1. I let the Raspberry Pi stream music to the aurora (connected via USB using the soundard functionality) until no sound from the aurora is was forwarded to the amps.
2. Then I have restarted my streaming daemon (squeezelite) of my Raspbery Pi installation. Still no sound.
3. I have disconnected the USB link to the aurora from the Raspberry Pi, connected it again and restarted squeezelite. Still no sound.
4. I have rebootet the aurora board and restarted the squeezelite daemon. Et voila, sound is playing.

Do you agree, that this seems to be an XMOS framework issue?

dspverden, 2022-09-06:
Well you never know. It could be that the RasPi sends a USB packet that makes the XMOS hanging. Therefore, try it with another platform. Then we can be sure that it is something like a counter overflow.
Two questions:
1) Did you try to reboot the RasPi instead of Aurora?
2) When USB audio is not playing anymore, does Aurora still play via other inputs (e.g. analog)?

exislow, 2022-09-06:
Let me first answer your questions:

1. I did. No effect, still no sound playing.
2. It does. I can select other presets, where I have some analog sources as input and it forwards the audio stream to my amps.

You are right about the USB. I will try it with my MacBook over night.

dspverden, 2022-09-19:
Any news on this? What was the result with the MacBook over night?

exislow, 2022-09-20:
Not, yet. I had some issues with the hibernate mode, business trips etc. But I do plan to have reliable results by end of the week.

exislow, 2022-09-25:
@dspverden you have been probably right... I have let my MacBook Pro streaming music for 36+ hours using the aurora as a soundcard via USB. No crash happened. The MacBook Pro was still able to stream stream music, which was forwarded by the autota to my amps.

This is probably related to the RPi USB stack or something. How can we analyze this problem further? It would also be beneficial to implement something like a "crash protection" in the aurora code base. Do you think something like this is possible to overcome this issue for all the RaspberryPi users?

archi, 2022-09-26:
You could try sniffing the USB traffic with tcpdump/wireshark to figure out where things go awry:
https://technolinchpin.wordpress.com/2015/10/23/usb-bus-sniffers-for-linux-system/
Though 36-48h of music streaming might be a lot of raw USB traffic, and I'd be surprised if the Pi decides "now I'll send a malformed packet at random".

USB 2.0 itself doesn't seem to have sequence numbers, but maybe UAC 2.0 does (could not find info on the packet layout). Maybe these overflow after x hours. Maybe the Linux UAC stack then does something the XMOS doesn't expect (start at the wrong value, duplicates a sequence number,...) and locks up.
A 32 bit _signed_(!) counter incrementing from 0 to INT32_MAX at 16kHz overflows after **37.28 hours** (`2^31/3600/16000`), allows for different behavior (continue at 0 or INT32_MIN) and only happens after a relatively long time with a firmware that cares for 100% correct sequence numbers.
Could be a coincidence, but it's well within your 36-48 hours.

A quick google search suggests UAC 2.0 bursts audio data to the XMOS in isochronous mode at some clock ([XMOS gives an example of 8000 Hz for 96kHz/24bit audio](https://www.xmos.ai/download/Fundamentals-of-USB-Audio(1.0).pdf)).
The 8kHz example fits up to 10 channels at 192/32; in which case the overflow would happen after ~74.6 hours (signed 32 bit) or ~150h (unsigned 32bit) when doing output only. However, when doing input/output twice the amount of data has to be transferred (-> 16kHz!), and/or the UAC stack on the host might pick a higher clock for less latency (wasting some USB bandwith).

I'm using the Aurora in my WFH setup, so I can't run longterm experiments, but maybe on the weekend I can setup my Linux PC to play some nonstop music and see if this also happens on a recent kernel on x86_64.

dspverden, 2022-09-27:
> This is probably related to the RPi USB stack or something. How can we analyze this problem further? It would also be beneficial to implement something like a "crash protection" in the aurora code base. Do you think something like this is possible to overcome this issue for all the RaspberryPi users?

well I would prefer to remove the root of problem instead of working on the symptoms. ;-)
I think making it on Aurora might be difficult. You could build in something like a watchdog inside the XMOS, that reboots/resets the XMOS in case of an error of the RasPi

exislow, 2022-10-02:
So there must be something on the Raspberry Pi USB stack or any drivers used by Pi Core Player distro (https://www.picoreplayer.org/) which let the XMOS crash within a short time frame. I basically never turn off my Aurora. I just mute it, when I do not use it. Thus, my Raspberry Pis continues to stream whatever intern radio station is just playing.

Streaming with my MacBook never caused such crashes.

@dspverden: I totally agree with you! Problems should be fixed at the root cause. At the moment I cannot really estimate, if this is just a Pi Core Player distro problem or a Raspbian problem or maybe even resides inside the Raspberry Pi USB driver. Thus, while the root case is not known at the moment I would vote a) for a wathdog solution in XMOS (bonus: Pushes fail safety / fault tolerance within the Aurora) and b) doing more investigation as @archi suggested.

@archi: I definately need to get more background knowledge regarding USB to be able to further analyze any wireshark logs.

dspverden, 2022-10-03:
Well I think the next step would be to go back to a standard RasPi distribution to find out if the problem is caused by Pi Core player or the USB stack itself.

Btw. Do you need 8 channels or just stereo? If stereo you could go via I2S of RasPi as a workaround.

exislow, 2022-10-03:
I will install a stock Raspbian image to my Raspberry Pi and let it stream audio for couple of days to verify this.

I just need stereo input and 6 channel output. I need to hardware Raspberry Pi's I2S pins with the Aurora's I2S (X102) on the PCB, correct? What Raspbian dt-overlay would you recommend to use then?

dspverden, 2022-10-03:
I am not so familiar with the RasPi. Wanted to build a medal server with RasPi+Aurora but first the RasPi wasn't available and if I look now at the prices, I think RasPi is not the route to go. Therefore, no idea of the internals of RasPi. Sorry.
But yes, connect the I2S as you said. You may need to configure the I2S receiver in SigmaStudio for it and recompile the project. Perhaps we can do that from the outside by writing to some register. In a few days I will hopefully get an Arylic streamer from somebody. once this device is here, I can help with that.

exislow, 2022-10-03:
I really appreaciate your effort! Thank you very much in advance. Unfortunately I do not have a spare Raspberry Pi left, otherwise I could send it to you. But anyway, maybe the Arylic streamer can help as well.

exislow, 2022-10-07:
I have installed installed (HiFiBerryOS)[hifiberry.com], which is basically a stripped down Raspbian OS optimized for music playback. Same issues as before: After 12-24 hours the USB sound within the Aurora crashes. The Aurora needs to be restartet (mains off & on) to be able to stream music using the USB sound card function. I do not think that this is an distro related bug based on only one distro but more something Raspberry Pi (Raspbian OS, USB driver, alsa etc.) related. What do you think?

dspverden, 2022-10-07:
Looks like. I don't know how RasPi-Distros are build, but on Intel/AMD machines Linux distributions optimized for audio come with a special compiled RT-kernel (sometimes). May this be an issue on RasPi as well?
Do you have a Linux-PC at home? You could use that to see wether the issue is Linux related. My Linux-PC is currently broken and had no time yet to replace the broken hardware. :(

exislow, 2022-10-08:
the latest HiFiBerryOS uses this kernel
```
# uname -a
Linux hifiberry 5.15.56-v7 #1 SMP Thu Aug 25 10:09:45 UTC 2022 armv7l GNU/Linux
```

It does not look like an RT / preempt kernel. I have no spare linux PC at home. I guess installing a Linux virtual machine on my macOS VMWare client wouldn't deliver comparable results, would it? Otherwise I will try to organize a spare Intel PC and install Debian on it, since Raspbian is based on Debian.

dspverden, 2022-10-08:
I have good experiences with Linux on macOS via VirtualBox, but only on Intel machines. Since I switched to Apple Silicon I haven't installed a Linux yet.

exislow, 2022-10-11:
So I got myself an Lenovo ThinkPad T470s and booted a live image of the current Debian 11 with XFCE desktop. I have connected the Aurora to the laptop and have streamed music for 48 hours to the Aurora and it still works!

This somehow shows the crash is Raspberry Pi, ARM or Raspbian related? I don't know. How should we procceed?

dspverden, 2022-10-12:
We can conclude from this, that it is not related to Aurora itself.
I think debugging the RasPi UAC2 stack is beyond the scope of Aurora community. Perhaps you can ask in the RasPi community regarding this?
Regarding a workaround: This might be difficult, because I have not idea how to detect that the USB crashed inside the XMOS code. At least nothing to be implemented quick and dirty.
Perhaps this: Return the audio to the RasPi and let the RasPi check, when it is playing music, that there should be a signal on the return path. Return path could be implemented via USB, too. Once the RasPi detects no input signal anymore, it restarts the Aurora?

Closed 2023-01-11.

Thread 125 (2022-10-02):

TOSLINK (S/PDIF) does not work.

exislow, 2022-10-02:
I have an Apple TV 4 / HD which is connected to my old LG TV. My TV has an TOSLINK and Coaxial S/PDIF out. If I try to connect the TOSLINK or coaxial S/PDIF out with my Aurora and configure it accordingly no audio received / interpreted by the Aurora.

Maybe my TV is not compatible or whatever... So I have used an active HDMI audio splitter, which has Cinch and TOSLINK out. So I have connected the TOSLINK out of the HDMI splitter to my Aurora. But once again: No audio is received / interpreted.

If I connect the analogue Cinch audio out of the HDMI splitter or the Cinch out of the LG TV the Aurora receives an audio signal successfully.

Any ideas, why I my Aurora cannot interpret any S/PDIF signals?

Aurora FW: v2.2.2
I use these cables:
* [TOSLINK KabelDirekt – TOSLINK-Kabel, optisches Audiokabel – 1,5 m – Glasfaserkabel für Soundbar (TOSLINK auf TOSLINK, digitales S/PDIF-Kabel, Stereoanlage/Verstärker, Heimkino, Xbox One/PS3/PS4)](https://www.amazon.de/gp/product/B00FQK3S3A)
* [S/PDIF Goobay 50267 Koaxial Digital Audio Verbindungskabel, Cinch S/PDIF, Zweifach Geschirmt 75 ohm](https://www.amazon.de/gp/product/B000NDHK3E)

dspverden, 2022-10-03:
I guess you are using AddOn-B?
Are you sure that you selected the right input?
Did you try it with another source then the TV/HDMI-Splitter?
It could be that the TV outputs a wrong sample rate or something like that because there are users going into Aurora with SPDIF.

exislow, 2022-10-03:
Sorry, forgot to mention it: Yes, I do use Addon B.

This is how my input config looks like:
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

Is it correct?

I have no other sources besides the TV (TOSLINK & S/PDIG Coax) and the HDMI splitter. What would you suggest for testing? Are you probably aware of any HDMI splitter or any other device which corrects with the Aurora?

What sample rate is required by the aurora? In this case the TV and the HDMI splitter must have a wrong sample rate. This seems strange to me.

dspverden, 2022-10-03:
It looks correct.
I have tested the SPDIF input with a Focusrite Scarlett 18i20 and there it was working. I can test it again for you. But that may take a few days, this week is not so much free time left.

exislow, 2022-10-03:
Just to get it right:

1. `S/P-DIF Input`: This is my source.
  a. This will be mapped on `SPDIF L` and `SPDIF R` (next to the `HP` block), correct?
3. S/P-DIF Output: What is this actually exactly for?

You do not need to re-test it. I would try to get any other affordable TOSLINK source, which is able to work with the Aurora. Can you tell me, what sample rates or whatever boundaries I need to pay attention to?

exislow, 2022-10-08:
@dspverden: I would appreciate it, if you could give me a short answer.

In the meanwhile I have bought this configurable HDMI audio extractor: (HDMI 2.0 Audio Extractor 4K 60Hz PS5 1080P 120Hz 4:4:4 HDCP 2.2 18 Gbit/s D-olby Vision HDR DE-Embed SPDIF Optical 5.1CH 3.5mm Stereo L/R Audio Breakout Digital Audio EDID Management, Scaler 4k 1080P)[https://www.amazon.de/gp/product/B07TZRXKYG]

I have tried all possible settings on the HDMI audio extractor, but still no sound via TOSLINK. Should I be concerned regarding my TOSLINK ports on addon B or maybe there is something with the IC?

This is how my current Aurora config looks like ()for test purposes the midrange speakers should play the TOSLINK input):
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

dspverden, 2022-10-08:
Ah you are right to remind me. Too many threads running at the same time... ;-)

Config looks right. I am going to test it here again. Just to make sure.
What should work in any case is a sample rate of 48kHz.
S/P-DIF-Output is the output on the aurora board. You can select which signal Aurora should forward to the output. Yet, the AddOn-B does not have an output, this is on AddOn-A.

dspverden, 2022-10-08:
P.S. Could you post a picture of your wiring? Perhaps a cable is missing or broken or something like that?

dspverden, 2022-10-12:
Sample rate 48k should work, at least.
You could check the MicroMatch-cable going from Aurora to AddOn-B. Sometimes these cables don't make a contact or the wire breaks.
Or you send me an email with your address and I will send you a new one. I think it is worth the try.

exislow, 2022-10-15:
I appreciate your help very much. Let me double check, if I have another cable with MicroMatch connectors somewhere. But the wiring of the MicroMatch connectors (Aurora to Addon B) is correct in terms of pin 1 of the Aurora is connected correctly with the other pin 1 of the Addon B?

exislow, 2022-10-16:
I have double checked the MicroMatch Cable X101 with my digital multimeter. Every pin has non broken wire from connector to connector, since I had no spare MicroMatch connectors anymore.  But still no sound from TOSLINK. But what I have seen is this:

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

Due to the PCB layout the X101 housing collides with the white right next to it. I really made sure, that there is still a working conenction from MicroMatch connector to the other MicroMatch connector. Also the very first pins are only relevant for S/PDIF (not TOSLINK) according to the scheme.

Do you think there is maybe an issue with something regarding the X102 connector cable? This controls the PCA9536D on the Addon B, correct?

Here are some recent pictures of my Aurora setup:

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

@dspverden: Can you suggest how to proceed? Should I get my oscilloscope out for debugging? Or do you have any other simplier ideas?

dspverden, 2022-10-23:
If you have an oscilloscope that would be helpful.
You can track the SPDIF-Signal from connector to DSP pin then. All measure points are easy to access. You can also check, wether the MUX on AddOn-B is switching correctly.
I see an extra PCB on X102. What is it for?

exislow, 2022-10-26:
It is just an X102 expansion board (see https://www.diy-hifi-forum.eu/forum/showthread.php?20465-Vorverst%C3%A4rker-m%C3%B6glich/page2&p=323042). But maybe it has a bug or whatever. I will try to remove it and do tests without it.

Tank you for clarifying, that there are no debug routines built it. I have an oscilloscope at home. I will just study the KiCAD layouts again and try to trace down the error.

exislow, 2022-11-07:
I was going to finally trace down what is wrong with my setup. Actually it has something to do with the X102 expansion board. Since I have removed it MUXing of the S/PDIF input is working finally.

Sorry for all the hassle with this topic. Lessons learned: Do not load your base setup with a bunch of untested stuff. Do it step by step. Thank you very much for your help.

Closed 2022-11-07.

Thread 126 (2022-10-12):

Windows and enumeration idea.

djkylian, 2022-10-12:
I am wondering, is this xmos design routed the same as the Xmos multichannel explorer kit XK-AUDIO-216-MC-xxx.

Cause when i was experimenting with that kit I found an unorthodox solution to let it work as a multichannel audio card with enumaration in Windows. Which shouldnt give any problems for experimental use.
I know it works with Asio driver as well, but not for software that can only use the default windows sound card.

I found that the xmos chip is also used in proffesional audio codecs like Focus rite and Berhinger which look pretty much the same in design. 🤔 Both use a branded Theysicon driver 🤓 and have a 18 and 20 in the model number 🧐. Which made me think of using one of their PID, VID to see if i could get the explorer kit to work as one of those 💡.
This worked with the XU216 and also on an older XS1 processor on the test boards with the default xmos multichannel firmware 👊.

Maybe someone with a programmer can see if this will also work for the Aurora.

dspverden, 2022-10-12:
Hm, I don't know why you should do this hack?
Windows 10 & 11 come both with a UAC2 driver and support Aurora as default sound device. Only the channel names cannot be changed...
The only "issue" is: As far as I know the standard windows drive is actually the Thesyscon driver. Thesyscon offers two version one with high and one with low latency. The standard windows driver is the high latency version. :(
I am not 100% sure about this. Maybe I am wrong, at least that is what I could find out.

djkylian, 2022-10-12:
Cause the windows default and thesyscon driver only show as a stereo input and output soundcard and doesn't give the option to run as a multiple stereo input and output card. For DJ and DAW software it will be easier to route in and outputs.

Actually I am looking for a multichannel audio codec with only analog in and outputs and no extra features like all the potentiometer and padding settings on the behringer, but also without optical in and output, wifi, bluetooth.

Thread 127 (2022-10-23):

S/PDIF Input Settings per Preset

exislow, 2022-10-23:
I have noticed, that these S/PDIF settings are not stored per preset but globally.

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

This means, I can have only one saved setting, which will be used for all presets. Is there a reason for it? I would be very happy, if S/PDIF settings could also be stored per preset.

dspverden, 2022-10-23:
Because the other 50% of all users want it not to be stored in the presets. ;-)

exislow, 2022-10-23:
Haha got it. Is it maybe possible to have an additional option, which declares the S/PDIF globally stored or per preset?

dspverden, 2022-10-23:
Should be doable.

dspverden, 2022-11-04:
Oh, I shall make it?
I am planning the next release mid/end December. I think it can come with that release.

exislow, 2022-11-04:
If it just a "few minutes" work for you, I would really appreciate it. Otherwise I will try to have a look by myself.

dspverden, 2022-11-04:
I have put it on my ToDo-list now.

exislow, 2022-11-05:
Thank you very much, this is very kind of you.

Btw.. This totally does not make sense: https://github.com/freeDSP/freeDSP-aurora/issues/127#issuecomment-1288131869

If you could store the S/PDIF settings per preset, then somebody, who likes it, how it is implement currently simply sets the S/PDIF settings in the upcomming implementation in all presets to the same value. Hence, he has the same result as right now with the global setting: S/PDIF input / output is the same for all presets.

Thus, I wouldn't vote for another option which can decalre S/PDIF settings "global" or "per preset" instead I would save time on this and simply make the S/PDIF settings stored per preset, which can be configured to also have the exact same result as with the current implementation. What do you think?

dspverden, 2022-11-05:
A long time I was thinking like you. But unfortunately life isn't that easy. I did that what you suggest with an another parameter (I think it was the master volume) and got then tons of emails like: "Found a bug, master volume not working when switching preset, please fix it within 24h else my lawyer will send you a nice letter." ;)

exislow, 2022-11-05:
You are kidding me? Okay, unfortunately I am not much into these legal details but I am sure you will find a safe way. Sorry to hear, that you have made such negative encounters.

dspverden, 2022-11-05:
Well, I can tell you stories, you won't believe how some go crazy

exislow, 2022-11-19:
I guess this issue is obsolete, since this behavior is already implemented. I do not know what did not workout with my setup, while I was testing this initially. Sometimes the esp32 is answering the AJAX calls verrrrrryyyyyyyyyyy sloooooow, thus the page is stuck for some seconds with settings from the previously chosen preset. Maybe this was the case.

Since I have tested it again right now and must say, S/PDIF input is already stored per preset. Hence, no actions needed. Sorry for the hassle.

Closed 2022-11-19.

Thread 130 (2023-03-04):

Rklib location?

mellbergsimon, 2023-03-04:
I am working on an variation of this board, basically just changing the external connections to D-sub. Also found some issues ordering a PCBA from jlcpcb.

I were also wondering what KiCad version I need to work in to make the library connection work, I have tried 7.0 and 6.0.11.
Every footprint is in a library called Rklib. Is this the [freeDSP library](https://github.com/freeDSP/freeDSP-KiCadLibrary) that is 7 years old? Where can I find the folder rklib?

How do I get up and working without replacing basically every component. I am a new KiCad user also so sorry if this is something everyone should know.

Kind Regards.
Simon

mellbergsimon, 2023-03-04:
Have anyone of you managed to order the whole board assembled from jlcpcb for example? Is this possible with existing files?

xtc0r, 2023-05-10:
Have you managed to find the rklib? I have the same issue. I want to try to order a Addon B PCB at a PCB prototype manufacturer as it seems it's the only option to get one. The Arurora shop doesn't have any since years.

mellbergsimon, 2023-05-10:
> Have you managed to find the rklib? I have the same issue. I want to try to order a Addon B PCB at a PCB prototype manufacturer as it seems it's the only option to get one. The Arurora shop doesn't have any since years.

Hi, no I did not succeed, i started going through the components needed an if they were available on jlcpcb. There were way too many components either not in stock or EOL for me to continue. As I had a deadline.

I think because of this the design will require rework as the main chip itself is unavailable. I think a chip factory burned down or something.

Good information is to be found in this [link](https://www.diyaudio.com/community/threads/freedsp-aurora-dsp-with-8-i-os-usb-audio-s-p-dif-adat-bluetooth-and-wifi-contro.334055/page-32)

So finally I decided to go another route and bought myself a xilica solaro qr1 for my use case. Obviously your use case would differ from mine.

I wish you good luck with your endeavour.

Closed 2025-04-27.

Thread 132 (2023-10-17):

WiFi disconnect

exislow, 2023-10-17:
My aurora connects to my local WiFi router after boot. But after couple of hours it looses the connection and stays disconnected.

Is it possible to fix this or maybe implement a watchdog, which tries to re-connect on disconnected or something?

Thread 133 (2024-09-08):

compile fails

LumpiZupf, 2024-09-08:
Hey,

Does anyone still have a setup that compiles and cares to share the libraries and tools with version numbers?

This is what I tried:

Arduino IDE - 2.3.2
ESP32 - 2.0.4 / 2.0.5 / 3.0.4
ArduinoJSON - 6.13.0
AsyncTCP - 1.1.4
ESP Async WebServer - 3.0.6
IRemote - 4.4.0
U8g2 - 2.27.6

For Libraries I did stick to the version numbers from the readme, for the ESP Board Library I also tried some versions from the time when the repository was last updated. I get so many errors from different files that either I have missed something obvious or I need a specific ESP or IDE Version??

Cheers,
Christian.

Erik1803, 2024-09-13:
Hi Christian,
I've just tried compiling the WEBAPP/aurora.ino project using PlatformIO in VS Code and it seems to be working. I have no chance to flash it to an ESP right now, but I didn't get any errors. Used the latest version of all libraries.
Maybe my platformio.ini configuration is helpful:

[env:featheresp32]
platform = espressif32
board = featheresp32
framework = arduino
lib_deps =
    https://github.com/bblanchon/ArduinoJson
    https://github.com/me-no-dev/AsyncTCP
    https://github.com/me-no-dev/ESPAsyncWebServer
    https://github.com/Arduino-IRremote/Arduino-IRremote
    https://github.com/olikraus/U8g2_Arduino

LumpiZupf, 2024-09-24:
Thanks Erik,

I finally managed to give this another go this morning. I did mess about with the libraries a bit but unfortunately, I already had them installed. Neither with the new or the recommended versions I could get it to compile...

The ticket was switching over to VS Code and PlatformIO!

I still get warnings, but at least it compiles. I might have to go back to the recommended versions on some of the libraries.

Unfortunately I have no time left today, but if I get it to compile the way it should and uploaded I will report back here.

Thanks again for your reply, since I am not familiar with the arduino world, I would never have cosidered switching to another IDE / compiler.

Cheers,
Christian.

LumpiZupf, 2024-10-13:
...I found a little bit of time this evening and the platform.ini below will compile the master as well as the development version without any issues or warnings.

The me-no-dev libraries had some commits and one fix, but nothing major changed.
You might also use the official arduino remote library, which had lots of changes, but then you either have to use a 2.x version or convert to the new one.

Next time I have time I will try to program the board...

Cheers,
Christian.

[env:esp32dev]
platform = espressif32
board = esp32dev
framework = arduino
lib_deps =
    olikraus/U8g2 @ 2.27.6
    bblanchon/ArduinoJson @ 6.13.0
    https://github.com/me-no-dev/AsyncTCP
    https://github.com/me-no-dev/ESPAsyncWebServer
    https://github.com/dspverden/Arduino-IRremote

derwhalfisch, 2025-02-16:
Hi all

In VSCode + PlatformIO.
To get it to compile, I have had to go through web.cpp and change all of these lines to 'const' and make the integer argument a 'char' No idea yet if this has changed the behaviour!

from
`AsyncWebParameter *idx = request->getParam(0);`

to
`const AsyncWebParameter *idx = request->getParam("0");`

My platformio.ini:

```

`[env:esp32dev]
platform = espressif32
board = esp32dev
framework = arduino
lib_deps =
	olikraus/U8g2 @ 2.27.6
	https://github.com/me-no-dev/AsyncTCP
	https://github.com/me-no-dev/ESPAsyncWebServer
	https://github.com/dspverden/Arduino-IRremote
	bblanchon/ArduinoJson@^7.3.0`

```

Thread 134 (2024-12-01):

Readme for custom plugin building missing?

Finnitio, 2024-12-01:
I just bought a second dsp board and now have the opportunity to continue building and testing a new plugin. At one point there was a a readme to build custom plugins. I can't seem to find it somewhere. If I would like to add new blocks like a mixing matrix, what files would I need to change to add this to the default template?

I know that it will not be easily done! But I am not completely aware off how the web front end, esp32 firmware and AUDAU/sigma firmware work together. What I mean by that is: if add a block for the web interface, that will set variables on the esp firmware which will change the paramters on the DSP chip, how is the logical chain of events?

Kind reagrds

Finn

derwhalfisch, 2025-02-09:
That readme is in the Wiki.

You can follow the process in vague terms through web.cpp & adau1452.cpp.

For example - see handlePostLshelvJson in web.cpp which is handling the 'POST' HTTP request for making a change to a low-shelf block. It seems to update a local map of all parameters held in RAM in the ESP32, then calls 'setLowShelving' in adau1452.cpp to mute,  write the updates to the appropriate registers in the ADAU1452, then unmute.

The ESP32 is aware of which register addresses are mappings for each block parameter because such a list is exported by SigmaStudio when compiling the plugin.

Finnitio, 2025-02-10:
Thanks a lot, that is great input and a good starting point I think.

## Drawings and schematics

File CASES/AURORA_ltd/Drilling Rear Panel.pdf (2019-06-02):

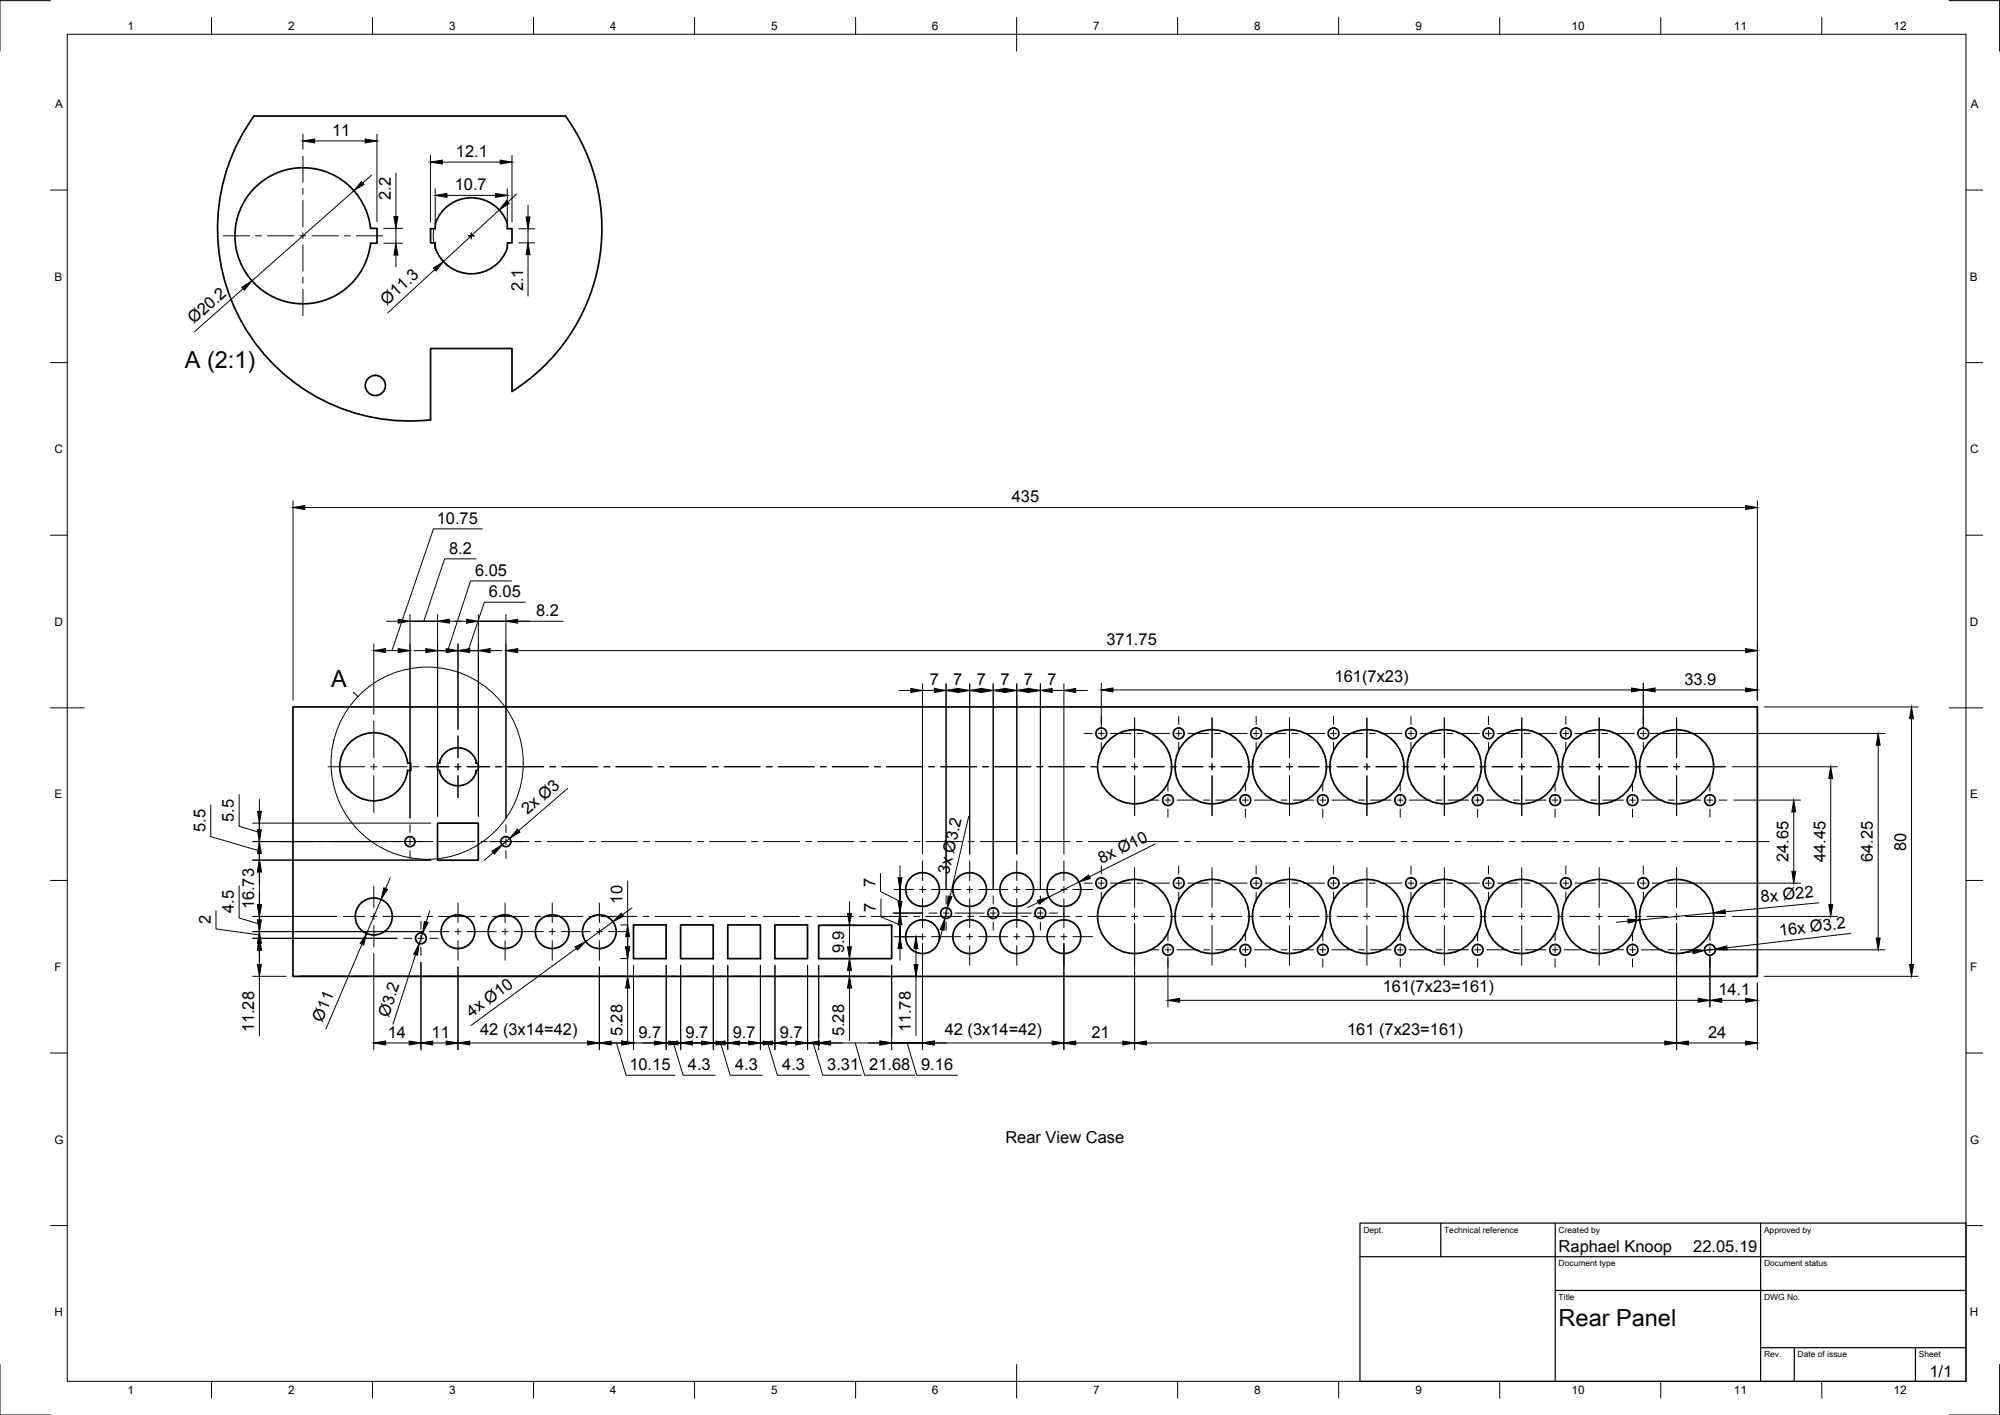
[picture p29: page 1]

Rear View Case

Dept. | Technical reference | Created by Raphael Knoop 22.05.19 | Approved by

Document type | Document status

Title Rear Panel | DWG No.

Rev. | Date of issue | Sheet 1/1

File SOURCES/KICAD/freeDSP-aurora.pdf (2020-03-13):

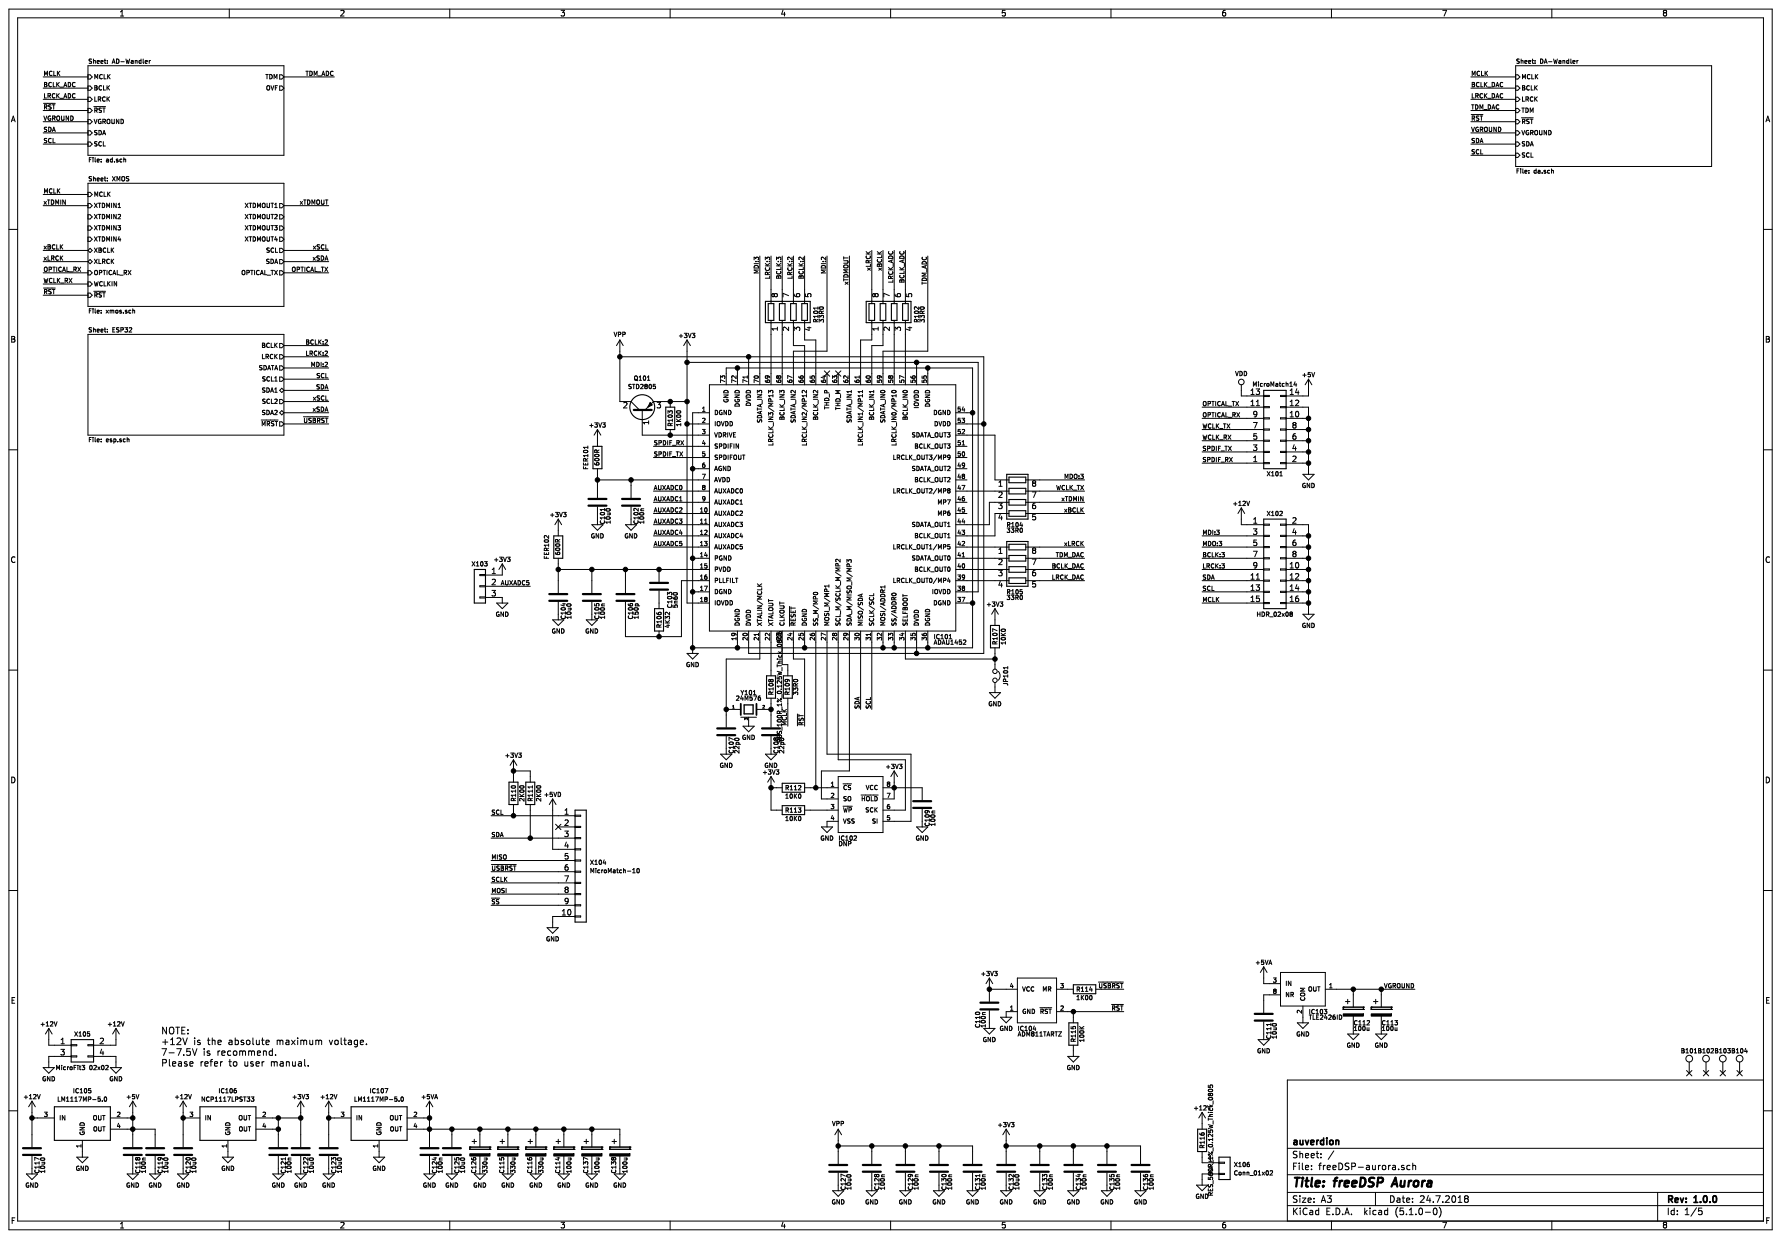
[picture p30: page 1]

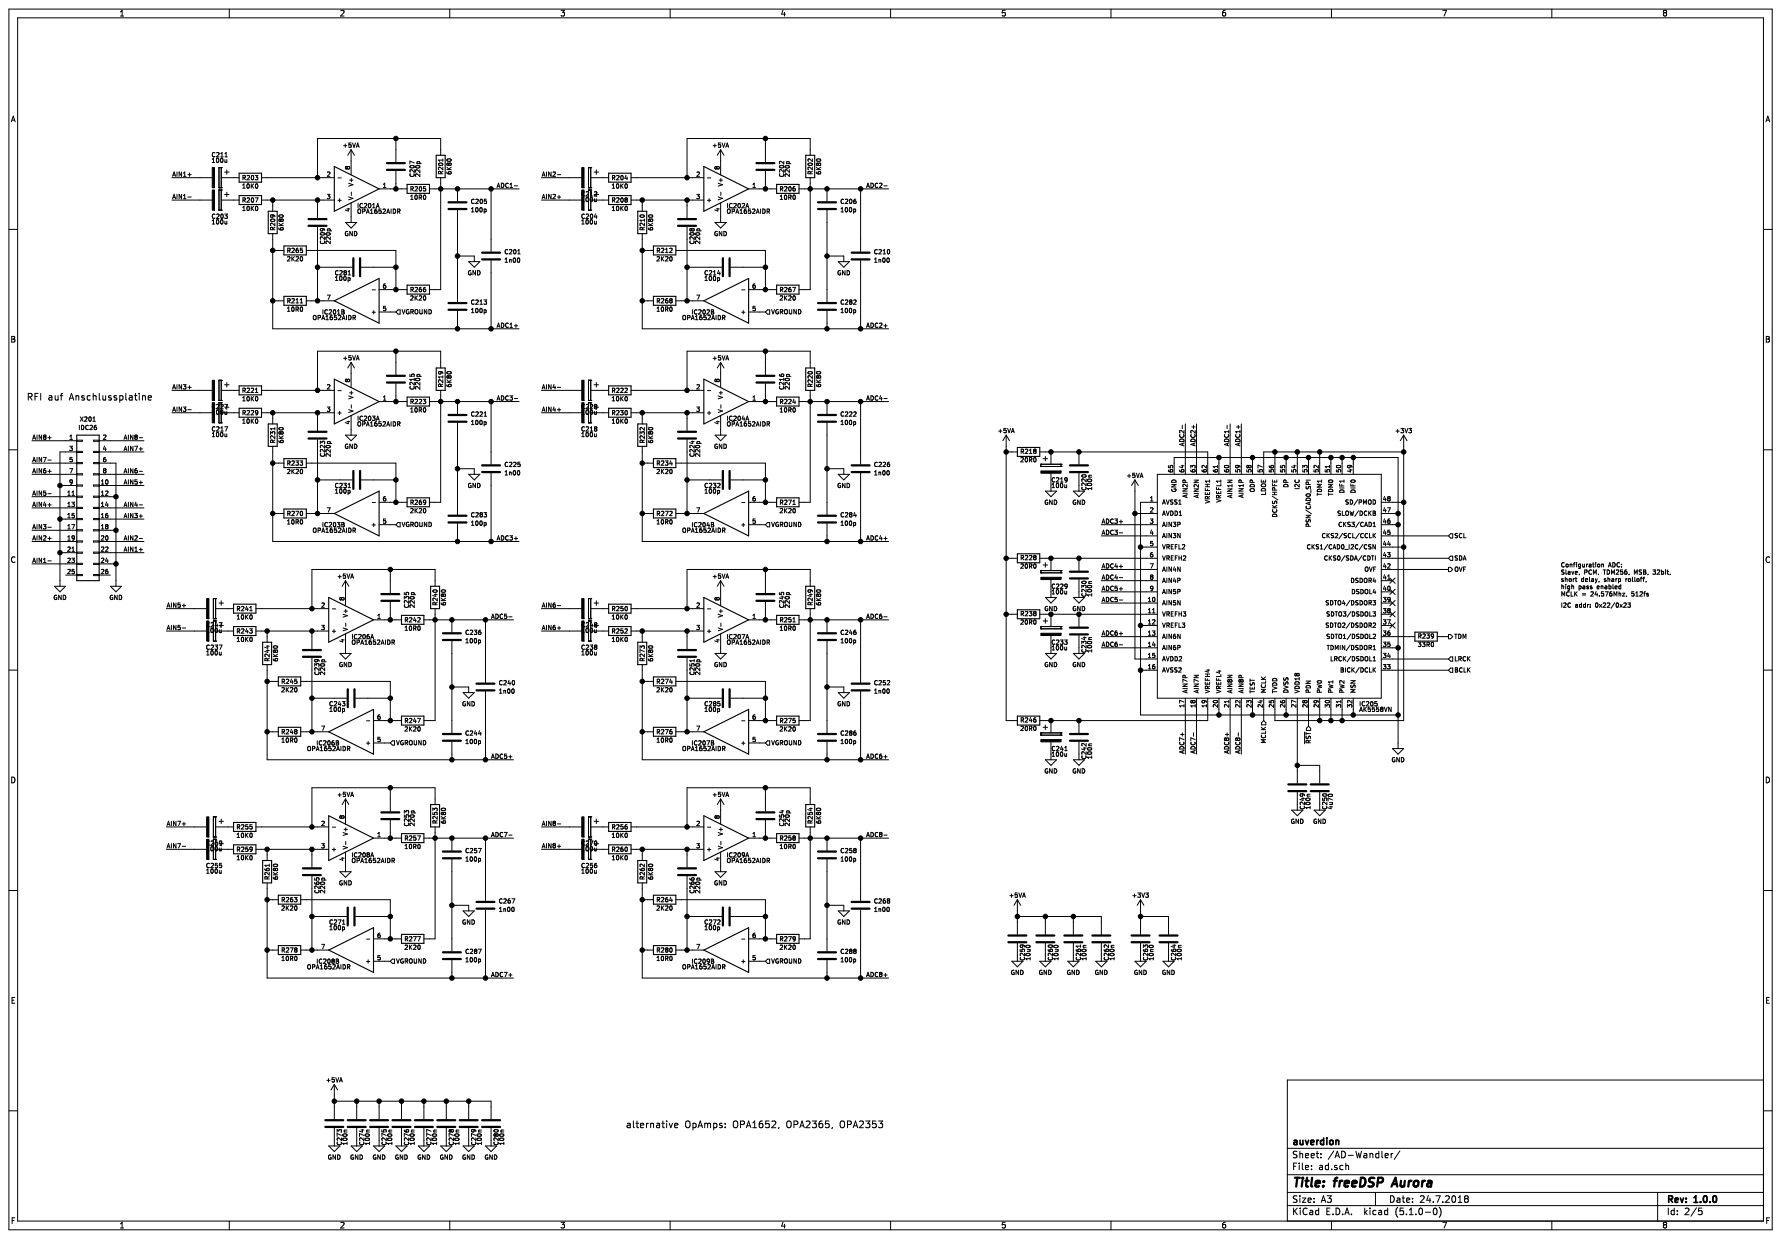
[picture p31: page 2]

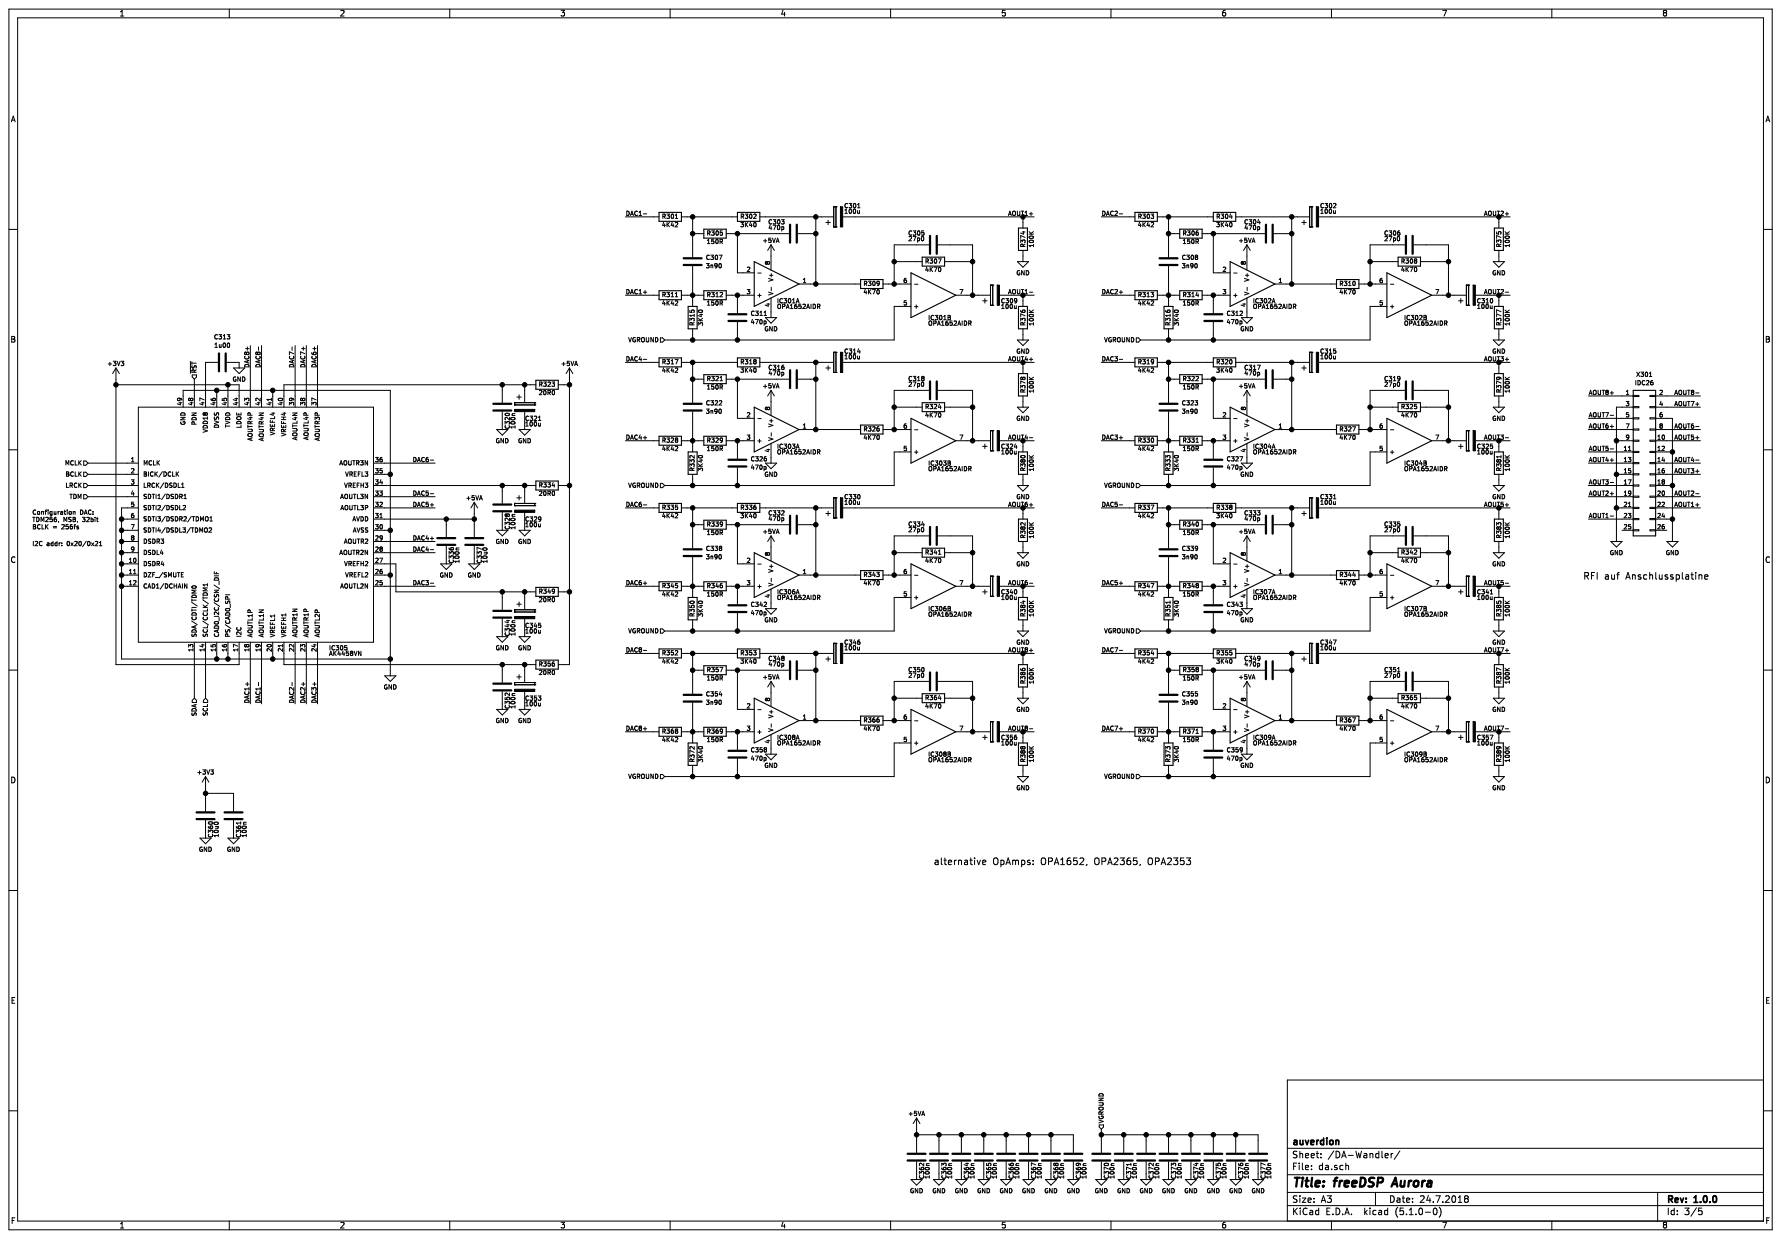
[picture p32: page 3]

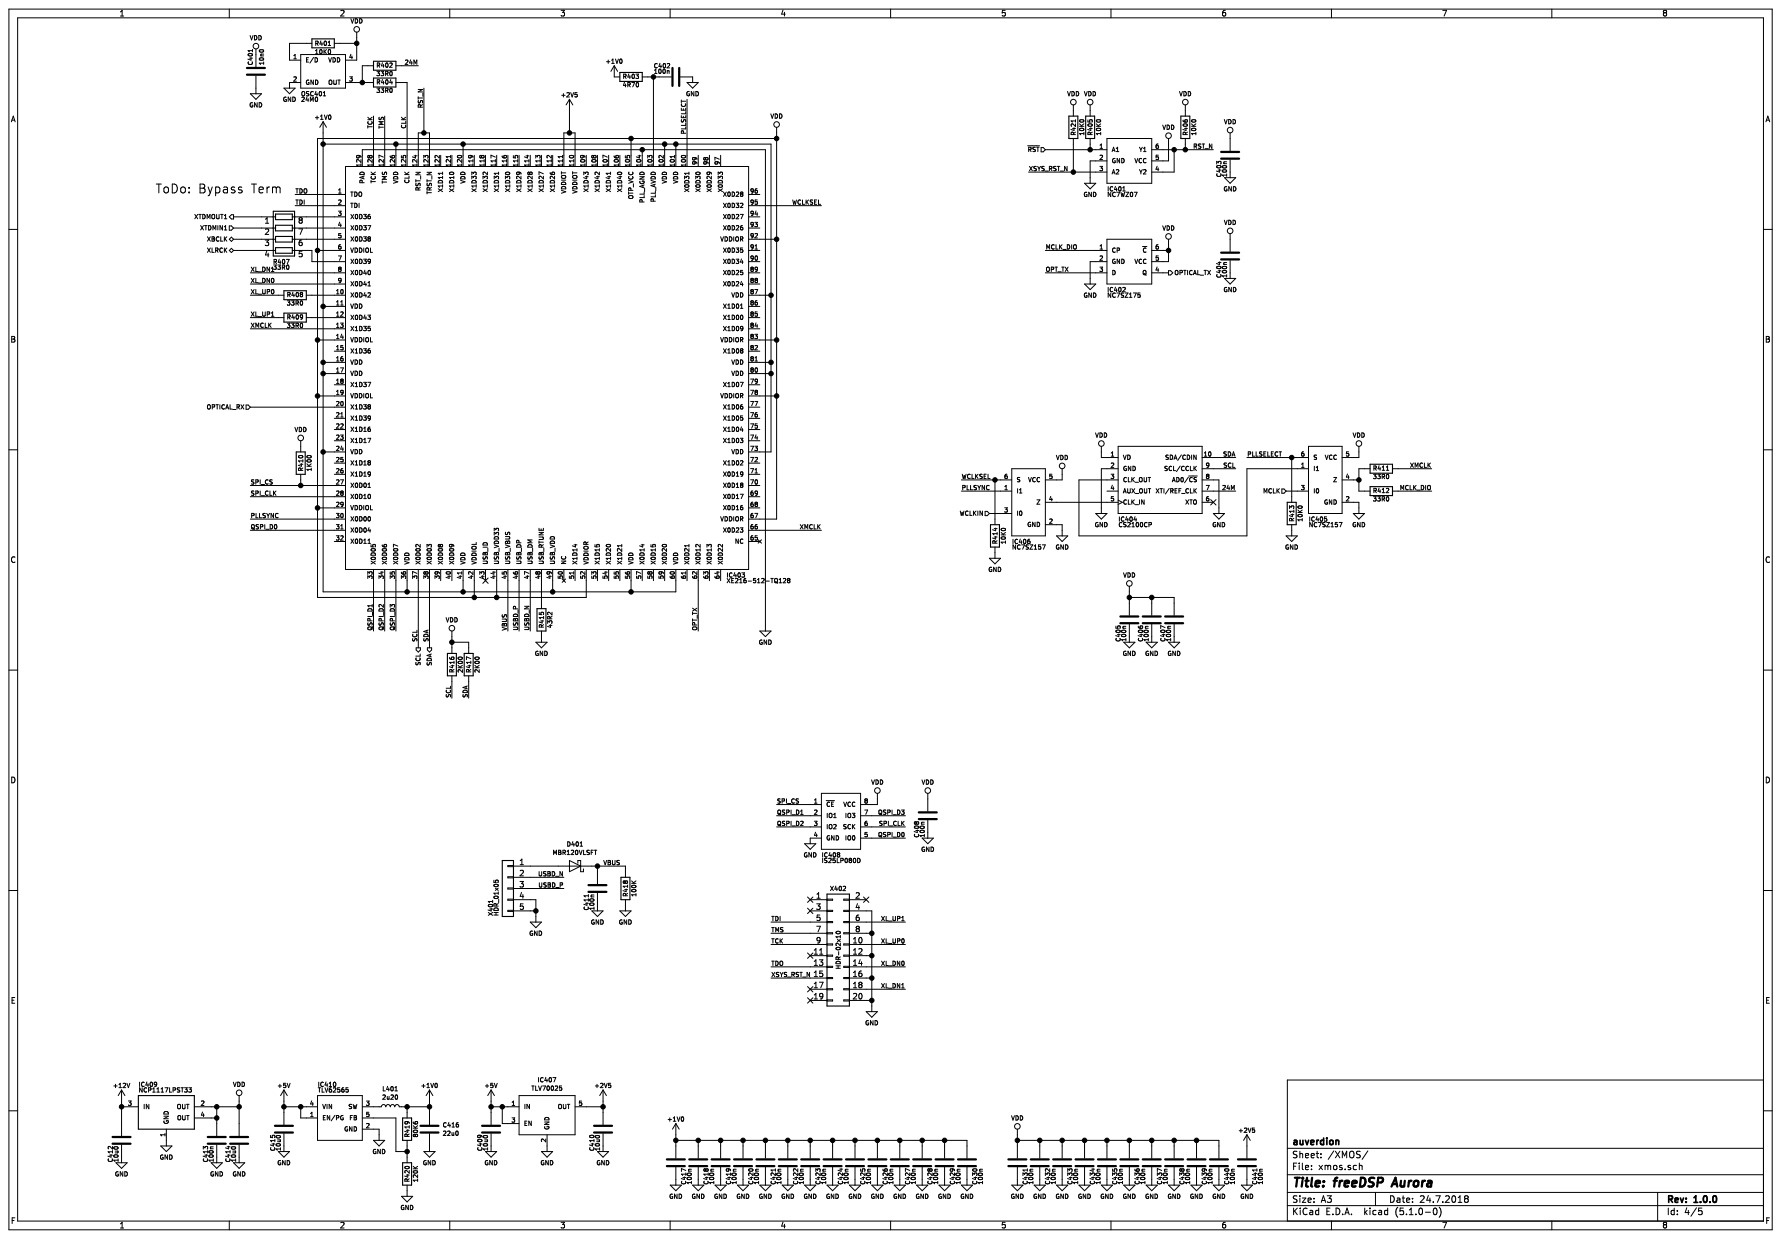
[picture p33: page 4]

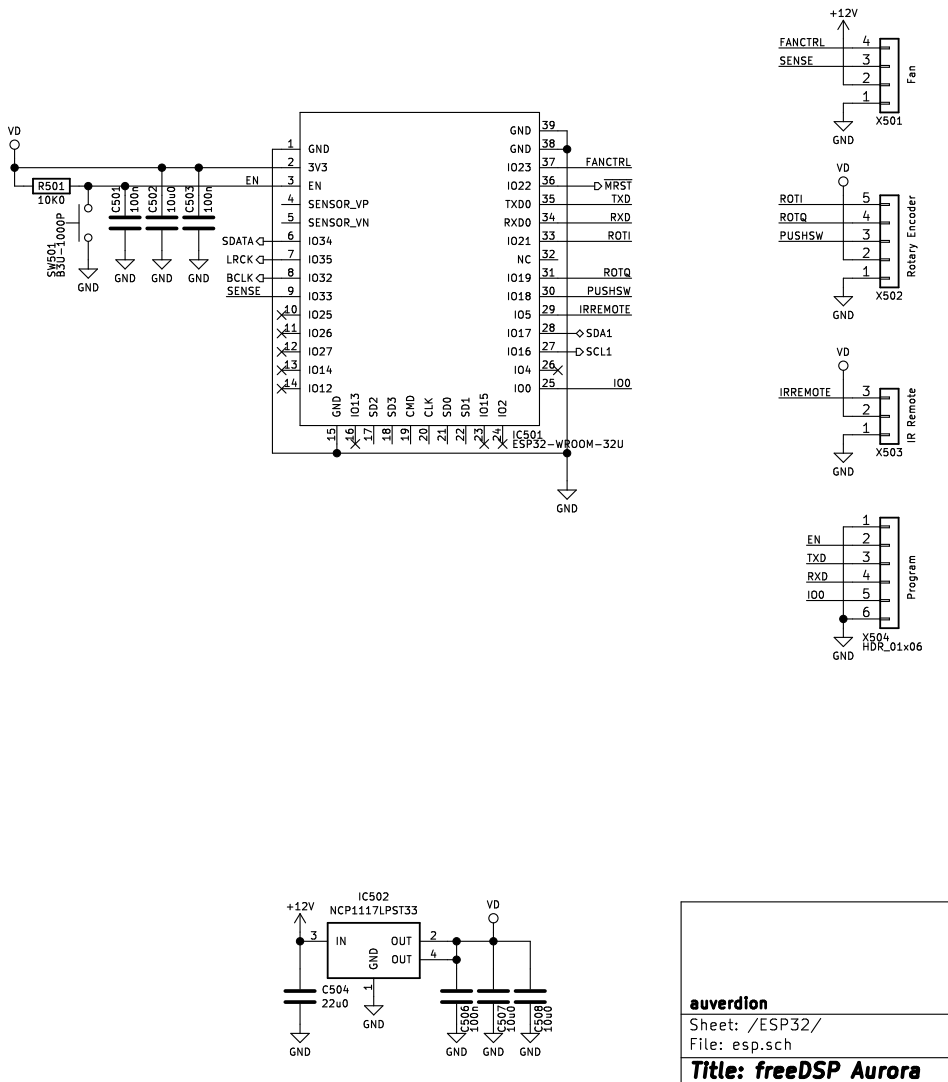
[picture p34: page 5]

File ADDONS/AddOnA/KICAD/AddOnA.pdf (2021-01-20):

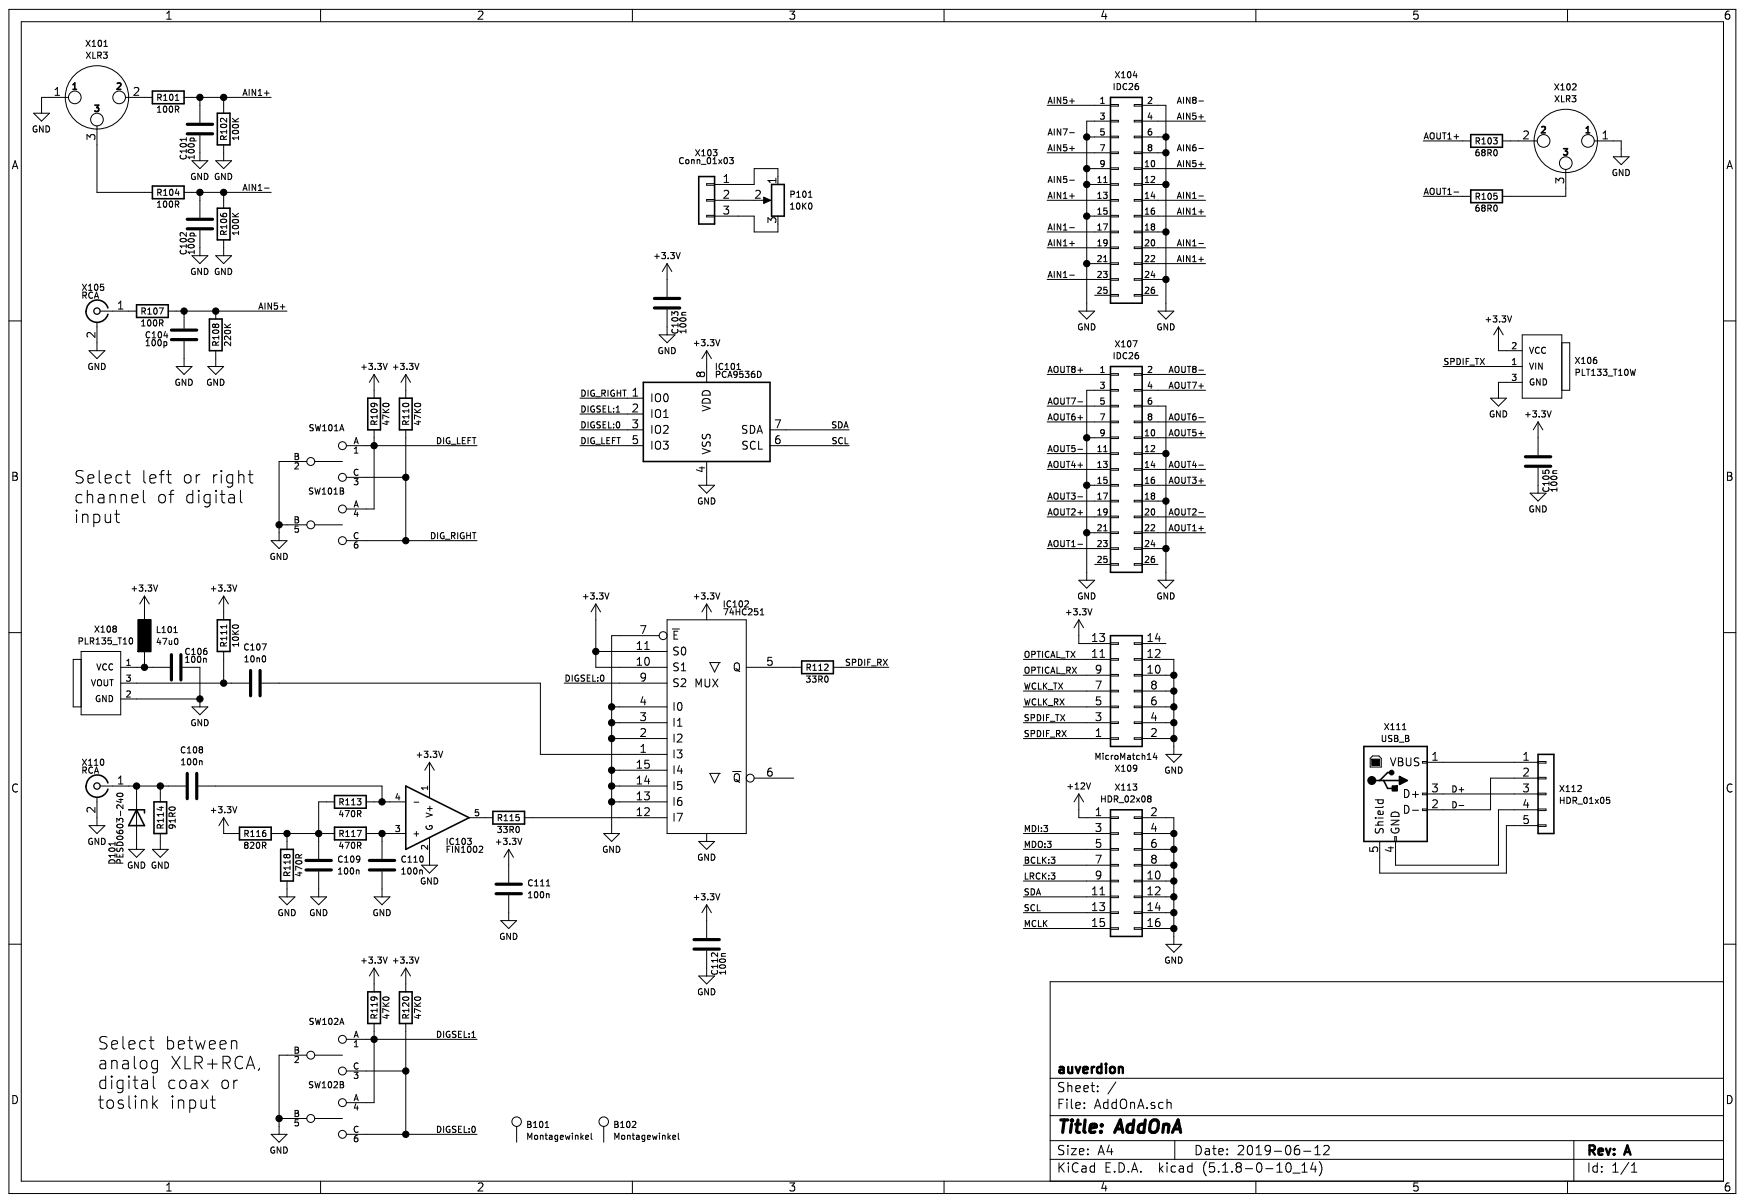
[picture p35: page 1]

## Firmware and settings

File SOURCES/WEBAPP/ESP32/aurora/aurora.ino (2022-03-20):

#include <Wire.h>
#include <WiFi.h>
#include <ESPAsyncWebServer.h>
#include <SPIFFS.h>
#include "AsyncJson.h"
#include <ArduinoJson.h>
#include "soc/timer_group_struct.h"
#include "soc/timer_group_reg.h"

#include "hwconfig.h"
#include "AK4458.h"
#include "AK5558.h"

#if HAVE_ROTARYENCODER
#include "rotaryencoder.h"
#endif

#if HAVE_IRRECEIVER
#include <IRremote.h>
#endif

#include "config.h"
#include "settings.h"
#include "adau1452.h"
#include "addons.h"
#include "display.h"
#include "plugin.h"
#include "web.h"
#include "channelnames.h"
#include "inputrouting.h"

/**
 * These are required for the espmake32 automatic library resolver
 * It's less powerful than the one from the Arduino IDE.
 * The if-guards can stay
 * see https://github.com/plerup/makeEspArduino
 */
#if 0
#include <FS.h>
#include <WebServer.h>
#include <AsyncTCP.h>
#include <u8g2.h>
#endif

File fileDspProgram;

bool changeWifiState = false;

//------------------------------------------------------------------------------
//
// Display
//
//------------------------------------------------------------------------------
#if HAVE_DISPLAY
Display myDisplay;
#endif

//------------------------------------------------------------------------------
//
// Rotary Encoder
//
//------------------------------------------------------------------------------
#if HAVE_ROTARYENCODER
long int lastREval = 0;
long int lastREsw = 0;
#endif

//------------------------------------------------------------------------------
//
// IR Receiver
//
//------------------------------------------------------------------------------
#if HAVE_IRRECEIVER
IRrecv irReceiver( IR_RECEIVER_PIN );
#endif

//==============================================================================
/*! Uploads the firmware from ESP32 SPI flash to DSP.
 */
void uploadDspFirmware( void )
{
  Serial.print(F("Init dsp......"));

  if(!SPIFFS.exists(F("/dsp.fw")))
  {
    Serial.println(F("File does not exist yet"));
    return;
  }

  fileDspProgram = SPIFFS.open(F("/dsp.fw"));

  uint32_t numBytesToRead = 0;
  byte byteReadMSB;
  byte byteReadLSB;
  uint16_t regaddr;

  if(fileDspProgram)
  {
    size_t len = fileDspProgram.size();
    int cntr = 0;
    while(cntr < len)
    {
      uint8_t byteRead;
      fileDspProgram.read( &byteRead, 1 );
      numBytesToRead = (numBytesToRead << 8) + (uint32_t)byteRead;
      fileDspProgram.read( &byteRead, 1 );
      numBytesToRead = (numBytesToRead << 8) + (uint32_t)byteRead;
      fileDspProgram.read( &byteRead, 1 );
      numBytesToRead = (numBytesToRead << 8) + (uint32_t)byteRead;
      fileDspProgram.read( &byteRead, 1 );
      numBytesToRead = (numBytesToRead << 8) + (uint32_t)byteRead;

      cntr += 4;

      //------------------------------------------------------------------------
      //--- Send register address and value
      //------------------------------------------------------------------------
      if(numBytesToRead > 0)
      {
        fileDspProgram.read(&byteRead, 1);
        regaddr = ((uint16_t)byteRead) << 8;
        cntr++;

        fileDspProgram.read(&byteRead, 1);
        regaddr += byteRead;
        cntr++;

        if(numBytesToRead == 4)
        {
          fileDspProgram.read(&byteReadMSB, 1);
          cntr++;
          fileDspProgram.read(&byteReadLSB, 1);
          cntr++;

          if(regaddr == 0x0000)
            delay(500);
          else
          {
            ADAU1452_WRITE_REGISTER(regaddr, byteReadMSB, byteReadLSB);
            if(cntr % 4096 == 0)
              Serial.print(F("."));
          }
        }
        else if(numBytesToRead > 4)
        {
          uint16_t addr = regaddr;
          byte val[4];

          for(uint32_t ii = 0; ii < numBytesToRead - 2; ii = ii + 4)
          {
            fileDspProgram.read(&(val[0]), 1);
            fileDspProgram.read(&(val[1]), 1);
            fileDspProgram.read(&(val[2]), 1);
            fileDspProgram.read(&(val[3]), 1);
            cntr += 4;
            ADAU1452_WRITE_BLOCK(addr, val, 4);
            if(cntr % 4096 == 0)
              Serial.print(F("."));
            addr++;
          }
        }
        else
        {
          Serial.print(F("[ERROR] Bad number of bytes: "));
          Serial.println(numBytesToRead);
        }
      }
    }
    int file_size = fileDspProgram.size();

    fileDspProgram.close();
    Serial.println(F("[OK]"));
    Serial.print(F("File size: "));
    Serial.println(file_size);
  }
  else
    Serial.println(F("\n[ERROR] Failed to open file dsp.fw"));
}

#if HAVE_DISPLAY
//==============================================================================
/*! Updates the user interface on the display
 *
 */
void updateUI( void )
{
  if(haveDisplay)
  {
    String ip;
    if( WiFi.status() != WL_CONNECTED )
      ip = "Not Connected";
    else
      ip = WiFi.localIP().toString();

    if( (editMode == 0) || (editMode == 1) || (editMode == 2) )
    {
      myDisplay.drawUI(currentPlugInName.c_str(), ip.c_str(), currentPreset, masterVolume.val, editMode);
    }

  }
}
#endif

//==============================================================================
/*! Wifi connection task
 *
 */
void myWiFiTask(void *pvParameters)
{
  wl_status_t state;
  bool firstConnectAttempt = true;
  bool myWiFiFirstConnect = true;
  int cntrAuthFailure = 0;
  IPAddress ip(192, 168, 5, 1);
  IPAddress subnet(255, 255, 255, 0);

  WiFi.mode(WIFI_AP_STA);
  WiFi.setHostname(AP_HOSTNAME);
  // Start access point
  if( Settings.pwdap.length() > 0 )
  {
    Serial.print(F("AP password protected "));
    Serial.println(Settings.apname);
    WiFi.softAP(Settings.apname.c_str(), Settings.pwdap.c_str());
  }
  else
  {
    Serial.print(F("AP open: "));
    Serial.println(Settings.apname);
    WiFi.softAP(Settings.apname.c_str());
  }
  delay(100);

  if(!WiFi.softAPConfig(ip, ip, subnet))
    Serial.println(F("AP Config Failed"));

  // Start server
  server.begin();

  while(true)
  {
    if((Settings.ssid.length() > 0) &&  (cntrAuthFailure < 10))
    {
      state = WiFi.status();
      if(state != WL_CONNECTED)
      {
        //if (state == WL_NO_SHIELD)
        if(firstConnectAttempt)
        {
          firstConnectAttempt = false;
          Serial.print(F("Connecting to "));
          Serial.println(Settings.ssid.c_str());
          WiFi.begin(Settings.ssid.c_str(), Settings.password.c_str());
          cntrAuthFailure++;
        }
        else if(state == WL_IDLE_STATUS)
        {
          Serial.println(F("Idle"));
        }
        else if(state == WL_NO_SSID_AVAIL)
        {
          Serial.println(F("No SSID available"));
        }
        else if(state == WL_CONNECTION_LOST)
        {
          Serial.println(F("WiFi connection lost"));
          WiFi.disconnect(true);
          cntrAuthFailure++;
        }
        // else if( state == WL_SCAN_COMPLETED )
        else if(state == WL_CONNECT_FAILED)
        {
          Serial.println(F("WiFi connection failed"));
          WiFi.disconnect(true);
          cntrAuthFailure++;
        }
        else if(state == WL_DISCONNECTED)
        {
          if(!myWiFiFirstConnect)
          {
            myWiFiFirstConnect = true;
            Serial.println(F("WiFi disconnected"));
          }
          Serial.println(F("No Connection -> Wifi Reset"));
          WiFi.persistent(false);
          WiFi.disconnect();
          WiFi.mode(WIFI_OFF);
          WiFi.mode(WIFI_AP_STA);
          delay(1000);
          // WiFi.config(ip, gateway, subnet); // Only for fix IP needed
          WiFi.begin(Settings.ssid.c_str(), Settings.password.c_str());
          delay(3000);
          cntrAuthFailure++;
        }
        vTaskDelay (250); // Check again in about 250ms
      }
      else // We have connection
      {
        if(myWiFiFirstConnect) // Report only once
        {
          myWiFiFirstConnect = false;
          cntrAuthFailure = 0;
          Serial.println(F("Connected"));
          Serial.print(F("IP address: "));
          Serial.println(WiFi.localIP());
          Serial.println(WiFi.getHostname());
          needUpdateUI = true;
        }
        vTaskDelay(5000); // Check again in about 5s
      }
    }
    else
      vTaskDelay(5000);
  }
}


//==============================================================================
/*! Arduino Setup
 *
 */
void setup()
{
  Serial.begin(115200);
  Serial.println(F("AURORA Debug Log"));
  Serial.println( VERSION_STR );
  #if DEBUG_PRINT
  Serial.print("Heap: ");
  Serial.println(xPortGetFreeHeapSize());
  #endif

  //----------------------------------------------------------------------------
  //--- Init Rotary Encoder Handling
  //----------------------------------------------------------------------------
  #if HAVE_ROTARYENCODER
  rotaryEncoder.init();
  lastREsw = rotaryEncoder.getSwitchValue();
  lastREval = rotaryEncoder.getRotationValue();
  #endif

  //----------------------------------------------------------------------------
  //--- Is user pressing the rotary encoder switch during boot?
  //----------------------------------------------------------------------------
  //rotaryEncoder.init();
  //pinMode( ROTARYENCODER_PINSW, INPUT_PULLUP );
  if( !digitalRead( ROTARYENCODER_PINSW ) )
    changeWifiState = true;
  
  //----------------------------------------------------------------------------
  //--- Configure I2C
  //----------------------------------------------------------------------------
  Wire.begin( I2C_SDA_PIN, I2C_SCL_PIN );
  Wire.setClock( 100000 );
  delay( 100 );

  //----------------------------------------------------------------------------
  //--- Scan for I2C display connected?
  //----------------------------------------------------------------------------
  #if HAVE_DISPLAY
  haveDisplay = false;
  Wire.beginTransmission(SSD1309_I2C_ADDR);
  if(Wire.endTransmission(true) == 0)
  {
    Serial.println(F("Detected SSD1309 display"));
    SSD1309.setI2CAddress(SSD1309_I2C_ADDR<<1);
    myDisplay.begin(&SSD1309);
    haveDisplay = true;
  }
  if(!haveDisplay)
  {
    Wire.beginTransmission(SH1106_I2C_ADDR);
    if(Wire.endTransmission(true) == 0)
    {
      Serial.println(F("Detected SH1106 display"));
      myDisplay.begin(&SH1106);
      haveDisplay = true;
    }
  }

  //----------------------------------------------------------------------------
  //--- Init Display (if present)
  //----------------------------------------------------------------------------
  if(haveDisplay)
    myDisplay.drawBootScreen();
  #endif

  // wait until everything is stable
  // might be a bit to defensive
  delay(2000);

  //----------------------------------------------------------------------------
  //--- Configure DAC
  //----------------------------------------------------------------------------
  Serial.println(F("Config DAC"));
  configDAC();

  //----------------------------------------------------------------------------
  //--- Configure ADC
  //----------------------------------------------------------------------------
  Serial.println(F("Config ADC"));
  configADC();

  //----------------------------------------------------------------------------
  //--- Start SPIFFS
  //----------------------------------------------------------------------------
  if(!SPIFFS.begin(true))
  {
    Serial.println(F("An Error has occurred while mounting SPIFFS"));
    return;
  }

  //--- check for old stuff (version == 1.x.x)
  String fileName = "/dspfw.hex";
  if(SPIFFS.exists(fileName))
  {
    if( SPIFFS.remove(fileName))
      Serial.println(fileName + " deleted.");
    else
      Serial.println("[ERROR] Deleting " + fileName );
  }
  fileName = "/dspparam.001";
  if(SPIFFS.exists(fileName))
  {
    if(SPIFFS.remove(fileName))
      Serial.println(fileName + " deleted.");
    else
      Serial.println("[ERROR] Deleting " + fileName);
  }
  fileName = "/dspparam.002";
  if(SPIFFS.exists(fileName))
  {
    if(SPIFFS.remove(fileName))
      Serial.println(fileName + F(" deleted."));
    else
      Serial.println("[ERROR] Deleting " + fileName);
  }
  fileName = "/dspparam.003";
  if(SPIFFS.exists(fileName))
  {
    if(SPIFFS.remove(fileName))
      Serial.println(fileName + " deleted.");
    else
      Serial.println("[ERROR] Deleting " + fileName);
  }
  fileName = "/dspparam.004";
  if(SPIFFS.exists(fileName))
  {
    if(SPIFFS.remove(fileName))
      Serial.println(fileName + F(" deleted."));
    else
      Serial.println("[ERROR] Deleting " + fileName);
  }

  Serial.print(F("Free disk space: "));
  Serial.print( (SPIFFS.totalBytes() - SPIFFS.usedBytes()) / 1024 );
  Serial.println(F("KiB"));

  File root = SPIFFS.open("/");
  File file = root.openNextFile();
  while(file)
  {
    Serial.print(file.name());
    Serial.print(F(" "));
    Serial.print(file.size());
    Serial.println(F(" Bytes"));
    file = root.openNextFile();
  }

  //----------------------------------------------------------------------------
  //--- Read settings file
  //----------------------------------------------------------------------------
  readSettings();
  changeChannelSummationADC();
  if( changeWifiState )
  {
    Serial.print(F("Changing WiFi status......"));
    Settings.wifiOn = Settings.wifiOn ? false : true;
    writeSettings();
    Serial.println(F("[OK]"));
  }

  Serial.print(F("Init user parameter......"));
  initUserParams();
  Serial.println(F("[OK]"));
  readPluginMeta();

  //----------------------------------------------------------------------------
  //--- Read virtual input channel routing (only if supported by plugin)
  //----------------------------------------------------------------------------
  if(currentPlugInName == String(F("stereoforever")) || currentPlugInName == String(F("The Room")))
  {
    if(!SPIFFS.exists(F("/vinputs.txt")))
      // if file does not exist, write it with defautl values
      writeVirtualInputRouting();
    else
      readVirtualInputRouting();
  }

  readChannelNames();

  //----------------------------------------------------------------------------
  //--- Configure AddOn
  //----------------------------------------------------------------------------
  updateAddOn();

  //----------------------------------------------------------------------------
  //--- Upload program to DSP
  //----------------------------------------------------------------------------
  uploadDspFirmware();

  //----------------------------------------------------------------------------
  //--- Upload user parameters to DSP
  //----------------------------------------------------------------------------
  uploadUserParams();

  //----------------------------------------------------------------------------
  //--- Configure Webserver
  //----------------------------------------------------------------------------
  setupWebserver();

  //----------------------------------------------------------------------------
  //--- Configure ESP for WiFi access
  //----------------------------------------------------------------------------
  // Create a connection task with 8kB stack on core 0
  if( Settings.wifiOn )
    xTaskCreatePinnedToCore(myWiFiTask, "myWiFiTask", 8192, NULL, 3, NULL, 0);

  //----------------------------------------------------------------------------
  //--- Enable Volume Potentiometer
  //----------------------------------------------------------------------------
  enableVolPot();

  //----------------------------------------------------------------------------
  //--- Init IR Receiver
  //----------------------------------------------------------------------------
  #if HAVE_IRRECEIVER
  irReceiver.enableIRIn();
  #endif

  if(currentPlugInName == String(F("stereoforever")) || currentPlugInName == String(F("The Room")))
    setVirtualInput();

  resetDAC(false);

  updateUI();

  lastREsw = rotaryEncoder.getSwitchValue();
  lastREval = rotaryEncoder.getRotationValue();

  #if DEBUG_PRINT
  Serial.print("Heap: ");
  Serial.println(xPortGetFreeHeapSize());
  #endif

  Serial.println(F("Ready"));
}

//==============================================================================
/*! Helpers
 *
 */

void update_preset(void) {
  softMuteDAC();
  initUserParams();
  uploadUserParams();
  updateAddOn();
  softUnmuteDAC();
}

void next_preset(void) {
  currentPreset++;
  if( currentPreset >= MAX_NUM_PRESETS )
    currentPreset = 0;

  update_preset();
}

void prev_preset(void) {
  if( currentPreset == 0 )
    currentPreset = MAX_NUM_PRESETS - 1;
  else
    currentPreset--;

  update_preset();
}

void increase_volume(void) {
  masterVolume.val += 0.5f;
  if( masterVolume.val > 0.f )
    masterVolume.val = 0.f;
  setMasterVolume();
}

void decrease_volume(void) {
  masterVolume.val -= 0.5f;
  if( masterVolume.val <= -80.f )
    masterVolume.val = -80.f;
  setMasterVolume();
}

//==============================================================================
/*! Arduino Main Loop
 *
 */
void loop()
{
  TIMERG0.wdt_wprotect=TIMG_WDT_WKEY_VALUE;
  TIMERG0.wdt_feed=1;
  TIMERG0.wdt_wprotect=0;


  #if HAVE_ROTARYENCODER
  if( rotaryEncoder.getSwitchValue() != lastREsw )
  {
    if(changeWifiState)
      changeWifiState = false;
    else
    {
      editMode++;
      if(currentPlugInName == String(F("stereoforever")))
      {
        if(editMode > 2)
          editMode = 0;
      }
      else
      {
        // we may have more then two modes in the future.
        if(editMode > 1)
          editMode = 0;
      }
      
      delay(300);
      needUpdateUI = true;
    }
    lastREsw = rotaryEncoder.getSwitchValue();
    lastREval = rotaryEncoder.getRotationValue();
  }
  else if( rotaryEncoder.getRotationValue() > lastREval + 1 )
  {
    if(editMode == 0)
    {
      increase_volume();
      lastREval = rotaryEncoder.getRotationValue();
      needUpdateUI = true;
    }
    else if( editMode == 1 )
    {
      myDisplay.drawSwitchingPreset();

      next_preset();

      lastREval = rotaryEncoder.getRotationValue();
      needUpdateUI = true;
    }
    else if(editMode == 2)
    {
      if(currentPlugInName == String(F("stereoforever")))
      {
        incrementVirtualInput();
        softMuteDAC();
        updateUI();
        softUnmuteDAC();
        lastREval = rotaryEncoder.getRotationValue();
        needUpdateUI = true;
      }
    }
  }
  else if( rotaryEncoder.getRotationValue() < lastREval - 1 )
  {
    if( editMode == 0 )
    {
      decrease_volume();
      lastREval = rotaryEncoder.getRotationValue();
      needUpdateUI = true;
    }
    else if( editMode == 1 )
    {
      myDisplay.drawSwitchingPreset();

      prev_preset();

      lastREval = rotaryEncoder.getRotationValue();
      needUpdateUI = true;
    }
    else if(editMode == 2)
    {
      if(currentPlugInName == String(F("stereoforever")))
      {
        decrementVirtualInput();
        softMuteDAC();
        updateUI();
        softUnmuteDAC();
        lastREval = rotaryEncoder.getRotationValue();
        needUpdateUI = true;
      }
    }
  }
  #endif

  #if HAVE_IRRECEIVER
  decode_results irResults;
  if( irReceiver.decode( &irResults ) )
  {
    Serial.println(irResults.value, HEX);
    uint32_t irval = (irResults.value & 0x0000ff00) >> 8;
    if((irval == APPLE_A_REMOTE_UP) || (irval == APPLE_B_REMOTE_UP))
    {
      increase_volume();
      needUpdateUI = true;
    }
    else if((irval == APPLE_A_REMOTE_DOWN) || (irval == APPLE_B_REMOTE_DOWN))
    {
      decrease_volume();
      needUpdateUI = true;
    }
    if(currentPlugInName == String(F("stereoforever")) || currentPlugInName == String(F("The Room")))
    {
      if((irval == APPLE_A_REMOTE_LEFT) || (irval == APPLE_B_REMOTE_LEFT))
      {
        decrementVirtualInput();
        setVirtualInput();
        needUpdateUI = true;
      }
      else if((irval == APPLE_A_REMOTE_RIGHT) || (irval == APPLE_B_REMOTE_RIGHT))
      {
        incrementVirtualInput();
        setVirtualInput();
        needUpdateUI = true;
      }
      else if((irval == APPLE_A_REMOTE_MENU) || (irval == APPLE_B_REMOTE_MENU))
      {
        myDisplay.drawSwitchingPreset();
        next_preset();
        needUpdateUI = true;
      }
    }
    else
    {
      if((irval == APPLE_A_REMOTE_LEFT) || (irval == APPLE_B_REMOTE_LEFT))
      {
        myDisplay.drawSwitchingPreset();
        prev_preset();
        needUpdateUI = true;
      }
      else if((irval == APPLE_A_REMOTE_RIGHT) || (irval == APPLE_B_REMOTE_RIGHT))
      {
        myDisplay.drawSwitchingPreset();
        next_preset();
        needUpdateUI = true;
      }
    }
    //else
    //  Serial.println(irResults.value, HEX);
    irReceiver.resume();
  }
  #endif

  if( needUpdateUI )
  {
    updateUI();
    needUpdateUI = false;
  }

}

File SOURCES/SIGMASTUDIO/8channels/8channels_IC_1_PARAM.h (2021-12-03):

/*
 * File:           C:\freeDSP-aurora\SOURCES\SIGMASTUDIO\8channels\8channels_IC_1_PARAM.h
 *
 * Created:        Friday, December 3, 2021 4:28:25 PM
 * Description:    8channels:IC 1 parameter RAM definitions.
 *
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
 * This software may only be used to program products purchased from
 * Analog Devices for incorporation by you into audio products that
 * are intended for resale to audio product end users. This software
 * may not be distributed whole or in any part to third parties.
 *
 * Copyright ©2021 Analog Devices, Inc. All rights reserved.
 */
#ifndef __8CHANNELS_IC_1_PARAM_H__
#define __8CHANNELS_IC_1_PARAM_H__


/* Module SafeLoadModule - SafeLoadModule*/
#define MOD_SAFELOADMODULE_COUNT                       6
#define MOD_SAFELOADMODULE_DEVICE                      "IC1"
#define MOD_SAFELOADMODULE_DATA_SAFELOAD0_ADDR         18832
#define MOD_SAFELOADMODULE_DATA_SAFELOAD1_ADDR         18833
#define MOD_SAFELOADMODULE_DATA_SAFELOAD2_ADDR         18834
#define MOD_SAFELOADMODULE_DATA_SAFELOAD3_ADDR         18835
#define MOD_SAFELOADMODULE_DATA_SAFELOAD4_ADDR         18836
#define MOD_SAFELOADMODULE_ADDRESS_SAFELOAD_ADDR       18837

/* Module Shift1 - Arithmetic Shift*/
#define MOD_SHIFT1_COUNT                               1
#define MOD_SHIFT1_DEVICE                              "IC1"
#define MOD_SHIFT1_BITSHIFTADAU145XALG1SHIFTBITS_ADDR  18839
#define MOD_SHIFT1_BITSHIFTADAU145XALG1SHIFTBITS_FIXPT 0x0000000E
#define MOD_SHIFT1_BITSHIFTADAU145XALG1SHIFTBITS_VALUE SIGMASTUDIOTYPE_INTEGER_CONVERT(14)
#define MOD_SHIFT1_BITSHIFTADAU145XALG1SHIFTBITS_TYPE  SIGMASTUDIOTYPE_INTEGER

/* Module HP1:1 - General Eq (2nd order)*/
#define MOD_PLUGIN_HP11_COUNT                          5
#define MOD_PLUGIN_HP11_DEVICE                         "IC1"
#define MOD_PLUGIN_HP11_ALG0_STAGE0_B2_ADDR            19200
#define MOD_PLUGIN_HP11_ALG0_STAGE0_B2_VALUE           SIGMASTUDIOTYPE_8_24_CONVERT(0)
#define MOD_PLUGIN_HP11_ALG0_STAGE0_B2_TYPE            SIGMASTUDIOTYPE_8_24
#define MOD_PLUGIN_HP11_ALG0_STAGE0_B1_ADDR            19201
#define MOD_PLUGIN_HP11_ALG0_STAGE0_B1_VALUE           SIGMASTUDIOTYPE_8_24_CONVERT(0)
#define MOD_PLUGIN_HP11_ALG0_STAGE0_B1_TYPE            SIGMASTUDIOTYPE_8_24
#define MOD_PLUGIN_HP11_ALG0_STAGE0_B0_ADDR            19202
#define MOD_PLUGIN_HP11_ALG0_STAGE0_B0_VALUE           SIGMASTUDIOTYPE_8_24_CONVERT(1)
#define MOD_PLUGIN_HP11_ALG0_STAGE0_B0_TYPE            SIGMASTUDIOTYPE_8_24
#define MOD_PLUGIN_HP11_ALG0_STAGE0_A2_ADDR            19203
#define MOD_PLUGIN_HP11_ALG0_STAGE0_A2_VALUE           SIGMASTUDIOTYPE_8_24_CONVERT(0)
#define MOD_PLUGIN_HP11_ALG0_STAGE0_A2_TYPE            SIGMASTUDIOTYPE_8_24
#define MOD_PLUGIN_HP11_ALG0_STAGE0_A1_ADDR            19204
#define MOD_PLUGIN_HP11_ALG0_STAGE0_A1_VALUE           SIGMASTUDIOTYPE_8_24_CONVERT(0)
#define MOD_PLUGIN_HP11_ALG0_STAGE0_A1_TYPE            SIGMASTUDIOTYPE_8_24

/* Module HP2:1 - General Eq (2nd order)*/
#define MOD_PLUGIN_HP21_COUNT                          5
#define MOD_PLUGIN_HP21_DEVICE                         "IC1"
#define MOD_PLUGIN_HP21_ALG0_STAGE0_B2_ADDR            19205
#define MOD_PLUGIN_HP21_ALG0_STAGE0_B2_VALUE           SIGMASTUDIOTYPE_8_24_CONVERT(0)
#define MOD_PLUGIN_HP21_ALG0_STAGE0_B2_TYPE            SIGMASTUDIOTYPE_8_24
#define MOD_PLUGIN_HP21_ALG0_STAGE0_B1_ADDR            19206
#define MOD_PLUGIN_HP21_ALG0_STAGE0_B1_VALUE           SIGMASTUDIOTYPE_8_24_CONVERT(0)
#define MOD_PLUGIN_HP21_ALG0_STAGE0_B1_TYPE            SIGMASTUDIOTYPE_8_24
#define MOD_PLUGIN_HP21_ALG0_STAGE0_B0_ADDR            19207
#define MOD_PLUGIN_HP21_ALG0_STAGE0_B0_VALUE           SIGMASTUDIOTYPE_8_24_CONVERT(1)
#define MOD_PLUGIN_HP21_ALG0_STAGE0_B0_TYPE            SIGMASTUDIOTYPE_8_24
#define MOD_PLUGIN_HP21_ALG0_STAGE0_A2_ADDR            19208
#define MOD_PLUGIN_HP21_ALG0_STAGE0_A2_VALUE           SIGMASTUDIOTYPE_8_24_CONVERT(0)
#define MOD_PLUGIN_HP21_ALG0_STAGE0_A2_TYPE            SIGMASTUDIOTYPE_8_24
#define MOD_PLUGIN_HP21_ALG0_STAGE0_A1_ADDR            19209
#define MOD_PLUGIN_HP21_ALG0_STAGE0_A1_VALUE           SIGMASTUDIOTYPE_8_24_CONVERT(0)
#define MOD_PLUGIN_HP21_ALG0_STAGE0_A1_TYPE            SIGMASTUDIOTYPE_8_24
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

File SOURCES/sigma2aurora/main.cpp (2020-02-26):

#include <QCoreApplication>
#include <QCommandLineParser>
#include <QDebug>
#include <QFile>
#include <iostream>

int main(int argc, char *argv[])
{
  QCoreApplication app(argc, argv);
  QCoreApplication::setApplicationName("sigma2aurora");
  QCoreApplication::setApplicationVersion("0.0.1");

  QCommandLineParser parser;
  parser.setApplicationDescription( "Converts SigmaStudio export files to Aurora DSp files." );
  parser.addHelpOption();
  parser.addVersionOption();
  parser.addPositionalArgument( "numbytes", QCoreApplication::translate( "main", "NumBytes_*.dat file of SigmaStudio export." ) );
  parser.addPositionalArgument( "txbuffer", QCoreApplication::translate( "main", "TxBuffer_*.dat file of SigmaStudio export." ) );

  parser.process( app );

  const QStringList args = parser.positionalArguments();

  if( args.size() != 2 )
  {
    parser.showHelp();
    exit( EXIT_FAILURE );
  }

  QString pathNumBytes = args.at(0);
  QString pathTxBuffer = args.at(1);

  qDebug()<<pathNumBytes;
  qDebug()<<pathTxBuffer;

  QFile fileTxBuffer( pathTxBuffer );
  QFile fileNumBytes( pathNumBytes );
  if( !fileTxBuffer.exists() )
  {
    std::cout<<"File"<<pathTxBuffer.toStdString()<<"does not exist"<<std::endl;
    exit( EXIT_FAILURE );
  }
  if( !fileNumBytes.exists() )
  {
    std::cout<<"File"<<pathNumBytes.toStdString()<<"does not exist"<<std::endl;
    exit( EXIT_FAILURE );
  }

  //----------------------------------------------------------------------------
  //--- Read and convert the TxBuffer_IC_1.dat file
  //----------------------------------------------------------------------------
  if( !fileTxBuffer.open( QIODevice::ReadOnly ) )
  {
    std::cout<<__FILE__<<__LINE__<<"Could not open selected file"<<pathTxBuffer.toStdString()<<std::endl;
    exit( EXIT_FAILURE );
  }

  QTextStream in( &fileTxBuffer );
  QStringList listTxBuffer;

  while( !in.atEnd() )
  {
    QString line = in.readLine().simplified();
    QStringList listStrings = line.split( ',' );
    for( int ii = 0; ii < listStrings.size(); ii++ )
    {
      QString str = listStrings[ii].simplified();
      if( str.startsWith( "0x" ) )
        listTxBuffer<<str;
    }
  }

  fileTxBuffer.close();

  //----------------------------------------------------------------------------
  //--- Read and convert the NumBytes_IC_1.dat file
  //----------------------------------------------------------------------------
  if( !fileNumBytes.open( QIODevice::ReadOnly ) )
  {
    std::cout<<__FILE__<<__LINE__<<"Could not open selected file"<<pathNumBytes.toStdString()<<std::endl;
    exit( EXIT_FAILURE );
  }

  QTextStream indat( &fileNumBytes );
  QStringList listNumBytes;

  while( !indat.atEnd() )
  {
    QString line = indat.readLine().simplified();
    QStringList listStrings = line.split( ',' );
    for( int ii = 0; ii < listStrings.size(); ii++ )
    {
      QString str = listStrings[ii].simplified();
      if( !str.isEmpty() )
        listNumBytes<<str;
    }
  }

  fileNumBytes.close();

  //----------------------------------------------------------------------------
  //--- Compose the data file content
  //----------------------------------------------------------------------------
  QByteArray content;
  int32_t offset = 0;
  for( int ii = 0; ii < listNumBytes.size(); ii++ )
  {
    uint32_t numbytes = listNumBytes[ii].toUInt( nullptr, 10 );

    content.append( static_cast<char>((numbytes >> 24) & 0xFF) );
    content.append( static_cast<char>((numbytes >> 16) & 0xFF) );
    content.append( static_cast<char>((numbytes >>  8) & 0xFF) );
    content.append( static_cast<char>(        numbytes & 0xFF) );

    for( uint32_t n = 0; n < numbytes; n++ )
    {
      if( offset >= listTxBuffer.size() )
      {
        std::cout<<"TxBuffer too small"<<std::endl;
        exit( EXIT_FAILURE );
      }

      char data = static_cast<char>( listTxBuffer[offset].toUInt( nullptr, 16 ) & 0xff );
      content.append( data );
      offset++;
    }
  }

  //----------------------------------------------------------------------------
  //--- Write firmware file
  //----------------------------------------------------------------------------
  QFile file( "dsp.fw" );
  if( !file.open( QIODevice::WriteOnly ) )
  {
    std::cout<<"Could not open dsp.fw for writing"<<std::endl;
    exit( EXIT_FAILURE );
  }

  if( file.write( content ) == -1 )
  {
    std::cout<<"Failed writing to dsp.fw"<<std::endl;
    exit( EXIT_FAILURE );
  }

  file.close();

  return 0; //app.exec();
}

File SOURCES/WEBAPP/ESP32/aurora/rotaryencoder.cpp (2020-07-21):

#include <Arduino.h>

#include "hwconfig.h"
#include "rotaryencoder.h"

portMUX_TYPE gpioMux = portMUX_INITIALIZER_UNLOCKED;

RotaryEncoder rotaryEncoder;

void IRAM_ATTR isrRotaryEncoderAB( void )
{
  uint8_t masked_state = rotaryEncoder.getCurrentState() & 0b00000011;

  portENTER_CRITICAL_ISR( &gpioMux );

  if( digitalRead( ROTARYENCODER_PINA ) )
    masked_state |= 0b00000100;
  if( digitalRead( ROTARYENCODER_PINB ) )
    masked_state |= 0b00001000;

  switch( masked_state )
  {
    case 0b00000000:
    case 0b00000101:
    case 0b00001010:
    case 0b00001111:
      break;

    case 0b00000001:
    case 0b00000111:
    case 0b00001000:
    case 0b00001110:
      rotaryEncoder.setRotationValue( rotaryEncoder.getRotationValue() - 1 );
      break;

    case 0b00000010:
    case 0b00000100:
    case 0b00001011:
    case 0b00001101:
      rotaryEncoder.setRotationValue( rotaryEncoder.getRotationValue() + 1 );
      break;

    case 0b00000011:
    case 0b00001100:
      rotaryEncoder.setRotationValue( rotaryEncoder.getRotationValue() - 2 );
      break;

    default:
      rotaryEncoder.setRotationValue( rotaryEncoder.getRotationValue() + 2 );
      break;
  }

  rotaryEncoder.setCurrentState( masked_state >> 2 );
  portEXIT_CRITICAL_ISR( &gpioMux );
}

void IRAM_ATTR isrRotaryEncoderSwitch()
{
 portENTER_CRITICAL_ISR( &gpioMux );
 if( digitalRead( ROTARYENCODER_PINSW ) )
   rotaryEncoder.setSwitchValue( rotaryEncoder.getSwitchValue() + 1 );
 portEXIT_CRITICAL_ISR( &gpioMux );
}

RotaryEncoder::RotaryEncoder( void )
{

}

void RotaryEncoder::init( void )
{
  value = 0;
  sw = 0;
  state = 2;

  pinMode( ROTARYENCODER_PINA, INPUT_PULLUP );
  pinMode( ROTARYENCODER_PINB, INPUT_PULLUP );
  pinMode( ROTARYENCODER_PINSW, INPUT_PULLUP );

  attachInterrupt( ROTARYENCODER_PINA, isrRotaryEncoderAB, CHANGE );
  attachInterrupt( ROTARYENCODER_PINB, isrRotaryEncoderAB, CHANGE );
  attachInterrupt( ROTARYENCODER_PINSW, isrRotaryEncoderSwitch, CHANGE );
}

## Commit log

2018-12-15 KiCAD files
    [ad-2018-11-09-10-59-36.sch, ad.sch, arduino.sch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]
2019-01-16 Updated BOM
    [ad.sch, da.sch, esp.sch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]
2019-02-16 Added 8channel loudspeaker management SigmaStudio project
    [8channels.params]
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2019-03-04 Added 4FIRs plugin
    [4FIRs.params]
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2019-03-19 AddOn-B prototype
    [AddOnB.kicad_pcb, AddOnB.sch]
2019-03-27 Optimized DAC Output filter
    [da.sch, esp.sch, freeDSP-aurora.kicad_pcb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]
2019-03-29 Improved ADC input stage
    [ad.sch, da.sch, esp.sch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]
2019-03-29 Added extra LDO for ESP32
    [ad.sch, esp.sch, freeDSP-aurora.kicad_pcb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]
2019-03-30 Improved layout around ESP32
    [freeDSP-aurora.kicad_pcb, xmos.sch]
2019-03-30 Improved LDO heatsinking
    [freeDSP-aurora.kicad_pcb, freeDSP-aurora.sch]
2019-03-30 Replaced obsolete +2V5 Reg
    [freeDSP-aurora.kicad_pcb, xmos.sch]
2019-03-30 I2C control of ADC
    [ad.sch, freeDSP-aurora.kicad_pcb, freeDSP-aurora.sch]
2019-03-30 I2C control of DAC
    [ad.sch, da.sch, freeDSP-aurora.kicad_pcb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]
2019-03-31 Added connector for power LED
    [freeDSP-aurora.kicad_pcb, freeDSP-aurora.sch]
2019-03-31 Added extra caps on analog supply rail
    [freeDSP-aurora.kicad_pcb, freeDSP-aurora.sch]
2019-04-01 Optimized ground plane
    [ad.sch, da.sch, esp.sch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]
2019-04-03 Final PCB layout
    [freeDSP-aurora.kicad_pcb]
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2019-04-14 Added i2c config of ADC and DAC
    [testproject.params]
2019-04-16 Preparation for production
    [freeDSP-aurora.kicad_pcb]
2019-04-17 Bugfix: Made WiFi pins unconnected
    [esp.sch, freeDSP-aurora.kicad_pcb, freeDSP-aurora.sch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]
2019-04-17 Bugfix: +3V3 connection on multiplexer
    [AddOnB.kicad_pcb, AddOnB.sch]
2019-04-19 DIY variant of layout
    [freeDSP-aurora DIY.kicad_pcb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]
2019-04-25 Updated sendParameter
    [8channels.params, ad.sch, da.sch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]
2019-04-30 Bugfix: Uploading parameters for Multi-Biquad filters
    [8channels.params, testproject2.params]
2019-04-30 Bugfix: Error message not sent in case of successful transfer of DSP parameter preset
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2019-05-05 Updated documentation
    [freeDSP-aurora BOM 1.0.0.xlsx]
2019-05-08 Bugfix: Storing Bypass setting on board
    [aurora.ino, main.cpp]
2019-05-14 Improved master volume handling
    [8channels.params]
2019-05-17 Updated Gerber for assembly
    [arduino.sch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]
2019-05-27 Minor changes on silkscreen
    [freeDSP-aurora.kicad_pcb]
2019-06-12 Schematic AddOn-A
    [1-AddOnB-TopSilkscreen.gto, 2-AddOnB-TopSoldermask.gts, 3-AddOnB-TopLayer.gtl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]
2019-06-14 Bugfix: Corrected I2C PIN numbers on ESP32
    [aurora.ino]
2019-06-19 Bugfix: C124/C125 reversed on silkscreen
    [freeDSP-aurora DIY.kicad_pcb, freeDSP-aurora.kicad_pcb]
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2019-06-20 Added USB-A connector
    [AddOnA.sch]
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2019-07-19 Added AddOn-C
    [AddOnC.kicad_pcb, AddOnC.sch]
2019-07-20 Step and PDF files for AddOns
    [AddOnB.step]
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2019-08-13 Changed version number, smaller bugfixes for input select, changed to explicit feedback for UAC2
    [aurora.ino, customdefines.h]
2019-08-21 Bugfix in sendDspParameter, SSID can be deleted
    [aurora.ino]
2019-08-27 Added HomeCinema71 plugin
    [HomeCinema71.params]
2019-08-28 USB workaround
    [8channelsUSB.params, HomeCinema71USB.params]
2019-09-27 Bugfix: Preset switching sets the correct master volume
    [aurora.ino]
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2019-10-24 Reversed X5
    [1-AddOnB-TopSilkscreen.gto, 2-AddOnB-TopSoldermask.gts, 3-AddOnB-TopLayer.gtl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]
2019-10-27 Minor bugfixes on hardware
    [1-AddOnB-TopSilkscreen.gto, 2-AddOnB-TopSoldermask.gts, 3-AddOnB-TopLayer.gtl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]
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2019-11-06 Updated Gerbers
    [AddOnA-B_Cu.gbl, AddOnA-B_Mask.gbs, AddOnA-B_Paste.gbp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]
2019-11-08 Updated BOM for AddOnA
    [AddOnA.sch]
2019-11-09 Activated SPDIF Reclocking
    [8channels.params]
2019-11-15 Updated BOMs
    [AddOnB.sch, AddOns BOM.xlsx]
2019-11-18 Updated BOM AddOnB
    [AddOnB.sch]
2019-11-20 Updated Gerbers for AddOnB
    [1-AddOnB-TopSilkscreen.gto, 2-AddOnB-TopSoldermask.gts, 3-AddOnB-TopLayer.gtl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]
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2019-12-05 Added 4FIRs plugin to GUI
    [4FIRs.params, AddOnB.sch]
2019-12-11 Added Volume Pot to DSP plugins
    [4FIRs.params, HomeCinema71.params]
2019-12-12 Enable switch for volume poti
    [4FIRs.params, 8channels.params, HomeCinema71.params]
2019-12-13 Bugfix: Init I2C before init ADC/DAC
    [aurora.ino]
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2019-12-17 Bugfix: Verify of DSP PlugIn
    [aurora.ino]
2020-01-03 Minor changes on AddOn A
    [AddOnA-B_Cu.gbl, AddOnA-B_Mask.gbs, AddOnA-B_Paste.gbp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]
2020-01-06 Mechanical redefinition of board edges AddOnA
    [AddOnA-B_Cu.gbl, AddOnA-B_Mask.gbs, AddOnA-B_Paste.gbp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]
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2020-01-16 Panel-B Rev01 - Powercon+Wippe
    AddOn-B Platine geprüft, Powercon+Wippschalter ungeprüft, Revision01
    [2D Innenkontur Rev01.dxf, 2D Panel-B Rev01.dwg, 2D Panel-B Rev01.dxf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]
2020-01-17 AddOnB: Moved case back plates to subfolder
    [2D Innenkontur Rev01.dxf, 2D Panel-B Rev01.dwg, 2D Panel-B Rev01.dxf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]
2020-01-17 Production files AddOn C
    [AddOnC-B_Cu.gbl, AddOnC-B_Mask.gbs, AddOnC-B_Paste.gbp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]
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2020-01-22 Revert "BOM maintenance"
    This reverts commit c294e1c44942507a1072948d23e8241872add495.
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2020-02-07 Bugfix Bypass switching
2020-02-11 Fixed: Invalid Master Volume address
    [aurora.ino]
2020-02-13 Fixed gain ranges and added adresses to plugin.ini
    [aurora.ino]
2020-02-19 Rear Panel-B Rev02
    [2HE Aussenkontur.dxf, Panel-B+12v.dxf, Panel-B+12v.stl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]
2020-02-19 Rear Panel-C Rev01
    [Aussenkontur 1HE.dxf, Panel-C+12v.dxf, Panel-C+12v.stl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]
2020-02-19 Rear Panel-D Rev01
    [Aussenkontur 1HE.dxf, Panel-D+12v.dxf, Panel-D+12v.stl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]
2020-02-20 Moved mechanical CAD data to subfolders
    [2D Innenkontur Rev01.dxf, 2D Panel-B Rev01.dwg, 2D Panel-B Rev01.dxf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]
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2020-03-06 Fixed Digital Input Selection on AddOnB during boot
    [aurora.ino]
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2020-03-13 Note regarding supply voltage
    [freeDSP-aurora.sch]
2020-03-29 Fixed an issue with delay = 0 ms
    [aurora.ino]
2020-04-03 Bugfix Plugin HomeCinema71: Wrong channel assignments fixed
    [HomeCinema71_IC_1_PARAM.h, aurora.ino]
2020-05-26 Update AddOnB
    [AddOnB-B_Cu.gbl, AddOnB-B_Mask.gbs, AddOnB-B_Paste.gbp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]
2020-06-14 Bugfix Volume Potentiometer HomeCinema71
    [HomeCinema71_IC_1_PARAM.h]
2020-06-14 Added SPDIF output multiplexer to 8channels
    [8channels.params]
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2020-07-09 fp-info-cache generated by KiCAD don't need to be tracked
2020-07-09 Added SPDIFout mux to GUI
    [8channels.params]
2020-07-10 myWiFiTask(): use variables and shorten softAPConfig() call
    [aurora.ino]
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2020-07-13 Fixed names in SigmaStudio projects
    [4FIRs.params, HomeCinema71.params]
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2020-07-18 Mute after deserialization attempt, so no need to unmute on error
    [aurora.ino]
2020-07-18 Silent -Werror=switch error
2020-07-19 Added spdif out routing to all plugins
    [2HE Aussenkontur.dxf, 4FIRs.params, 8channelsUSB.params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]
2020-07-20 FIxed Routing issue in matrix for SPDIF TX
    [8channels_IC_1_PARAM.h, HomeCinema71_IC_1_PARAM.h]
2020-07-21 Fixed Rotary Encoder vs. WiFi off bug
    [aurora.ino, rotaryencoder.cpp]
2020-07-21 Fixed the Safari bug for compressed javascript files
    [aurora.ino]
2020-07-22 Bugfix Importing preset from 2.0.x
    [aurora.ino]
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2020-08-02 move the AKxx58's code to their own cpp files
    (missing files amended to this commit, might not build)
    [AK4458.cpp, AK5558.cpp, aurora.ino]
2020-08-14 fix issue #16 by adding a 250ms delay
    [AK4458.cpp]
2020-10-31 Fixed: sigma2aurora.py writing wron address array to plugin.ini for high passes
    [config.h]
2020-11-01 Fixed issue #62 and #63
    [web.cpp]
2020-11-08 Update README.md
    fixed adress foe ESP32 dev module
2020-11-21 Fix issue #74
    [AddOns BOM.xlsx]
2021-01-18 PDF schematic AddOn B
    [AddOnB.sch]
2021-01-20 Fixed issue #42
    [AddOnA.sch]
2021-02-20 Fixed memory leak for FIRs with < 4096 taps and more then 4 FIRs
    [adau1452.cpp, config.h, plugin.cpp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]
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2021-08-27 Fixed display update issue
    [OLED128x64_SSD1309.cpp, aurora.ino, inputrouting.cpp]
2021-08-31 Set correct i2c address for auto detection
    [OLED128x64_SH1106.cpp, OLED128x64_SSD1309.cpp, aurora.ino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]
2021-09-26 Renaming channels and preset (issue #57)
    [channelnames.cpp, config.h, plugin.cpp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]
2021-10-08 Fixed issue #83
    [freeDSP-aurora-B_Cu.gbl, freeDSP-aurora-B_Mask.gbs, freeDSP-aurora-B_Paste.gbp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]
2021-10-08 Updated XLR input board of AddOnB
    [AddOnB.kicad_pcb, AddOnB.sch]
2021-10-09 Updated SigmaStudio files for 8channels
    [8channels.params]
2021-10-26 Updated SigmaStudio project files
    [4FIRs.params, HomeCinema71.params]
2021-11-17 Tested plugins
    [8channels.params]
2021-11-18 Reduced input/output count to 4
    [4FIRs.params]
2021-11-22 Fix for issue #91
    [4FIRs.params, 8channels.params, HomeCinema71.params]
2021-11-30 Reduce code redundancy between rotary encoder & ir remote presets & volume
2021-11-30 Mute before switching virtual input
    [TheRoom.params]
2021-12-01 The default path doesn't use version (at least with Arduino IDE1)
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2021-12-03 Fixed the missing PEQ dialog for HomeCinema71
    [OLED128x64_SH1106.cpp, OLED128x64_SSD1309.cpp, aurora.ino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]
2021-12-03 Bugfix channel screw up
    [TheRoom.params]
2022-01-14 Fixed SPDIF routing for Virtual Inputs
    [aurora.ino, channelnames.cpp, inputrouting.cpp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]
2022-02-07 Fix for issue #105
    [adau1452.cpp]
2022-03-12 Fixed wrong AddOn header in GUI
    [customdefines.h, web.cpp]
2022-03-13 Increased PEQ-Bands to 10 fpr 4FIRs plugin
    [4FIRs.params]
